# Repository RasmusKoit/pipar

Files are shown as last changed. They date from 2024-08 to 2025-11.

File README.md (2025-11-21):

# Pipar PCBs

ZMK firmware for the Pipar PCBs.



**Pipar** is a collection of different keyboards and keypads that I have designed. Each PCB in the series has unique features tailored to different needs and preferences.

## Designed PCBs

PCB Files for each keyboard/project has been seperated into their own folders. The PCBs are designed in KiCad v9.x

Currently, the following PCBs are available:

- [Pipar & Sool](#pipar-ja-sool-pepper-and-salt) - 36-key split wireless keyboard with a 3x5+3 layout and a dongle.
- [Pipar Point](#pipar-point) - 40-key split wireless keyboard with a 3x5+3+2 layout, trackpoint and LEDs.
- [Pipar Flake](#pipar-flake) - 8+1 key wireless keypad with a rotary encoder and a screen.
- [Pipar Chip](#pipar-chip) - 12-key wireless keypad with Kailh PG1316S switches and LEDs.

### Pipar ja Sool (Pepper and Salt)

> [!TIP]
> Get your own Pipar & Sool from my [Etsy Store](https://piparkeyboards.etsy.com).

Pipar Miryoku builds can be found here: [[RasmusKoit/miryoku_zmk]](https://github.com/RasmusKoit/miryoku_zmk/actions/workflows/build-example-pipar.yml)


The **Pipar ja Sool** is a 36-key split wireless keyboard with a 3x5+3 layout with a dongle. It features:

- **Microcontrollers**: XIAO BLE for both halves and a dongle.
- **Switches**: Ambients Silent Kailh Low Profile Nocturnal Choc Switches.
- **Sockets**: Kailh Hotswap sockets for easy switch replacement.
- **Key Layout**: Pipar & Sool uses Miryoku default key layout.
- **LEDs**: White LEDs for backlight.

#### Pipar ja Sool Pictures

Pictures from version V1

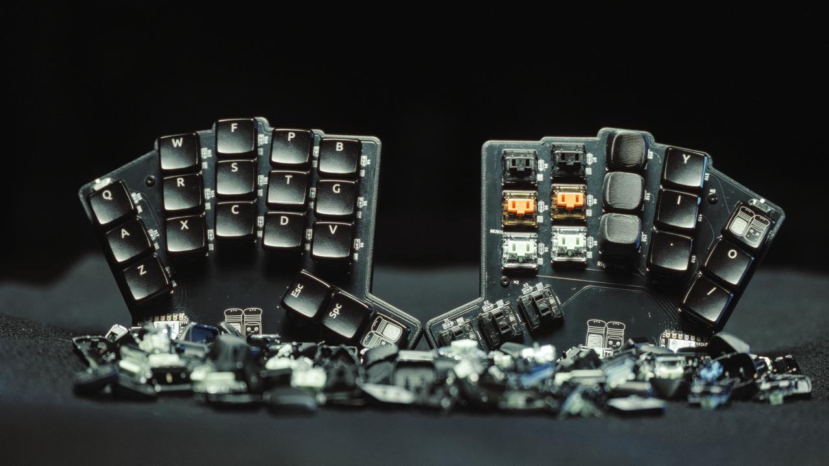
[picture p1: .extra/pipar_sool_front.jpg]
Pipar & Sool front

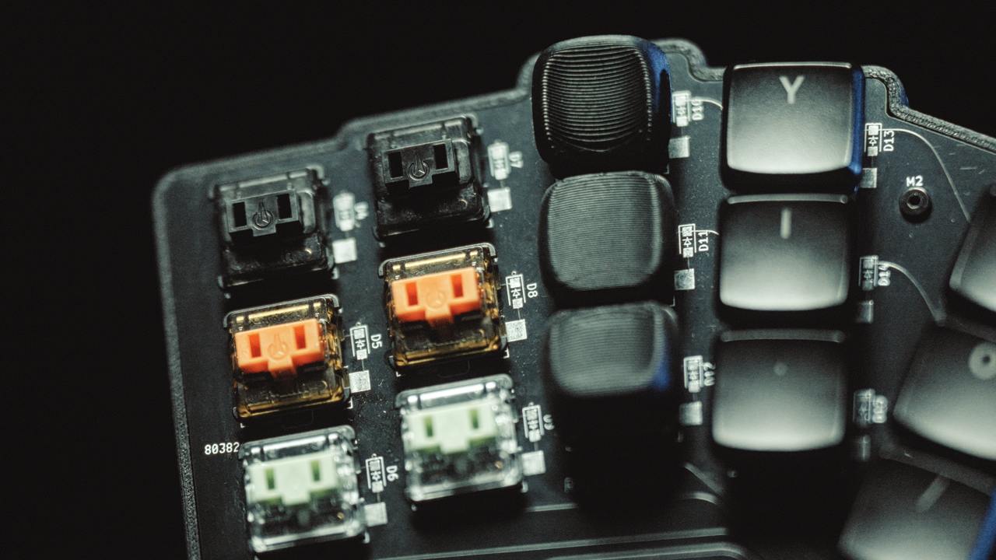
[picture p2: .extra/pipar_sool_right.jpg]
Pipar & Sool right

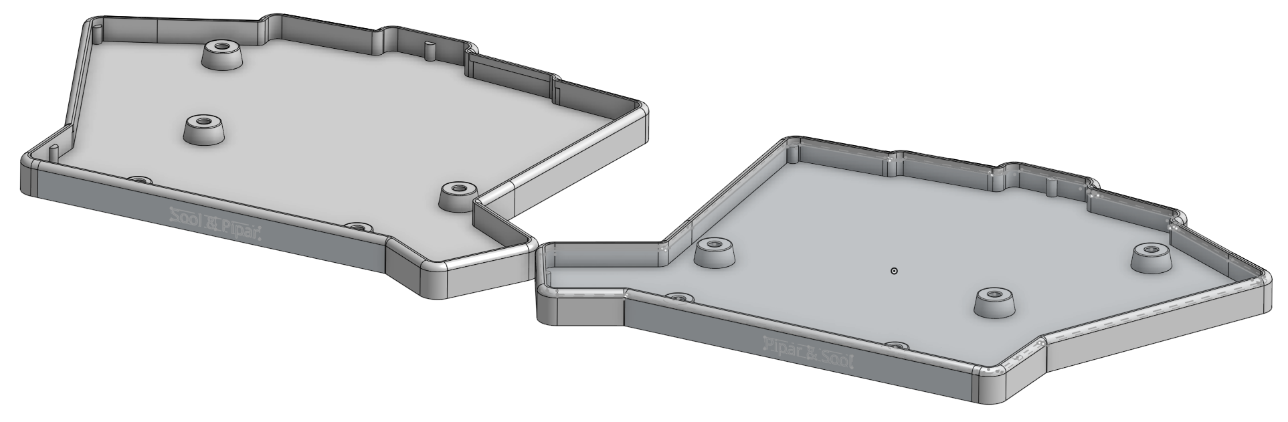
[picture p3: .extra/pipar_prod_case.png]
Pipar & Sool case


<!-- markdownlint-disable MD033 -->
<details>
  <summary>More Pictures V3</summary>

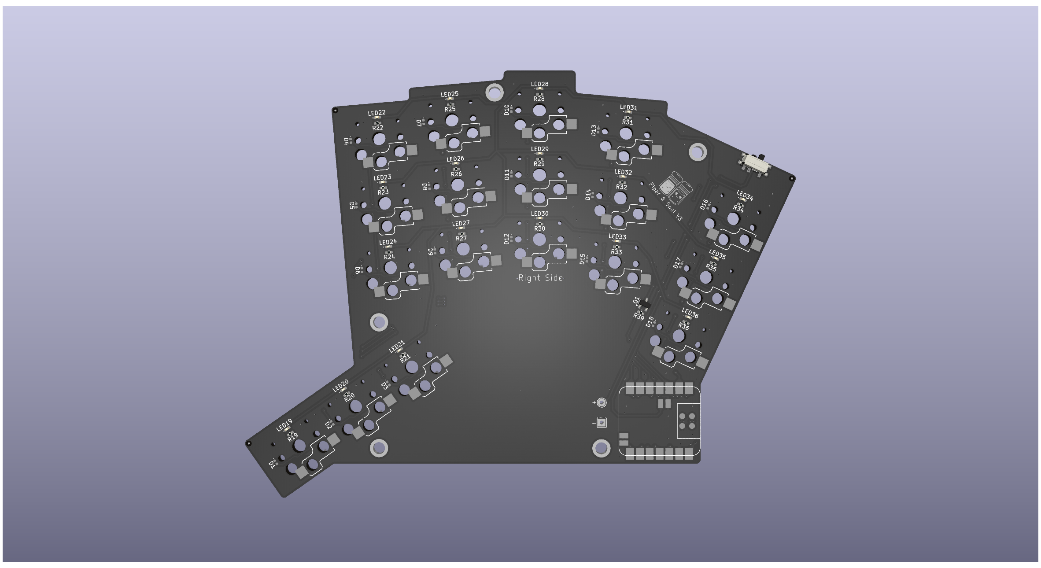
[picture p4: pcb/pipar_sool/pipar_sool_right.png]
Pipar & Sool right
  
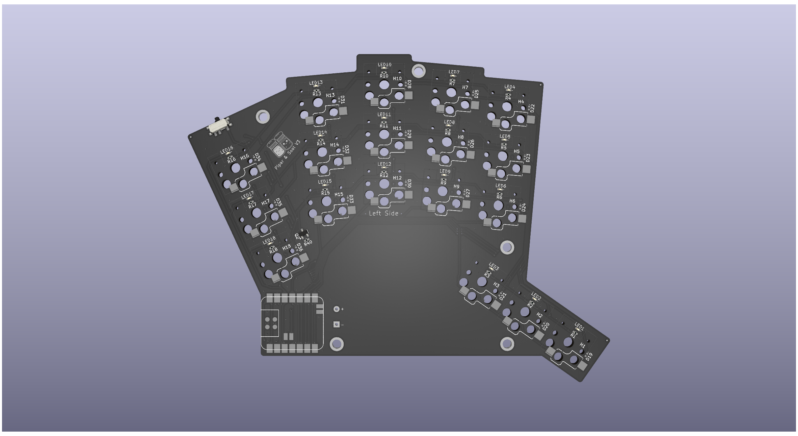
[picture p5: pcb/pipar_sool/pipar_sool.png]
Pipar & Sool left
  
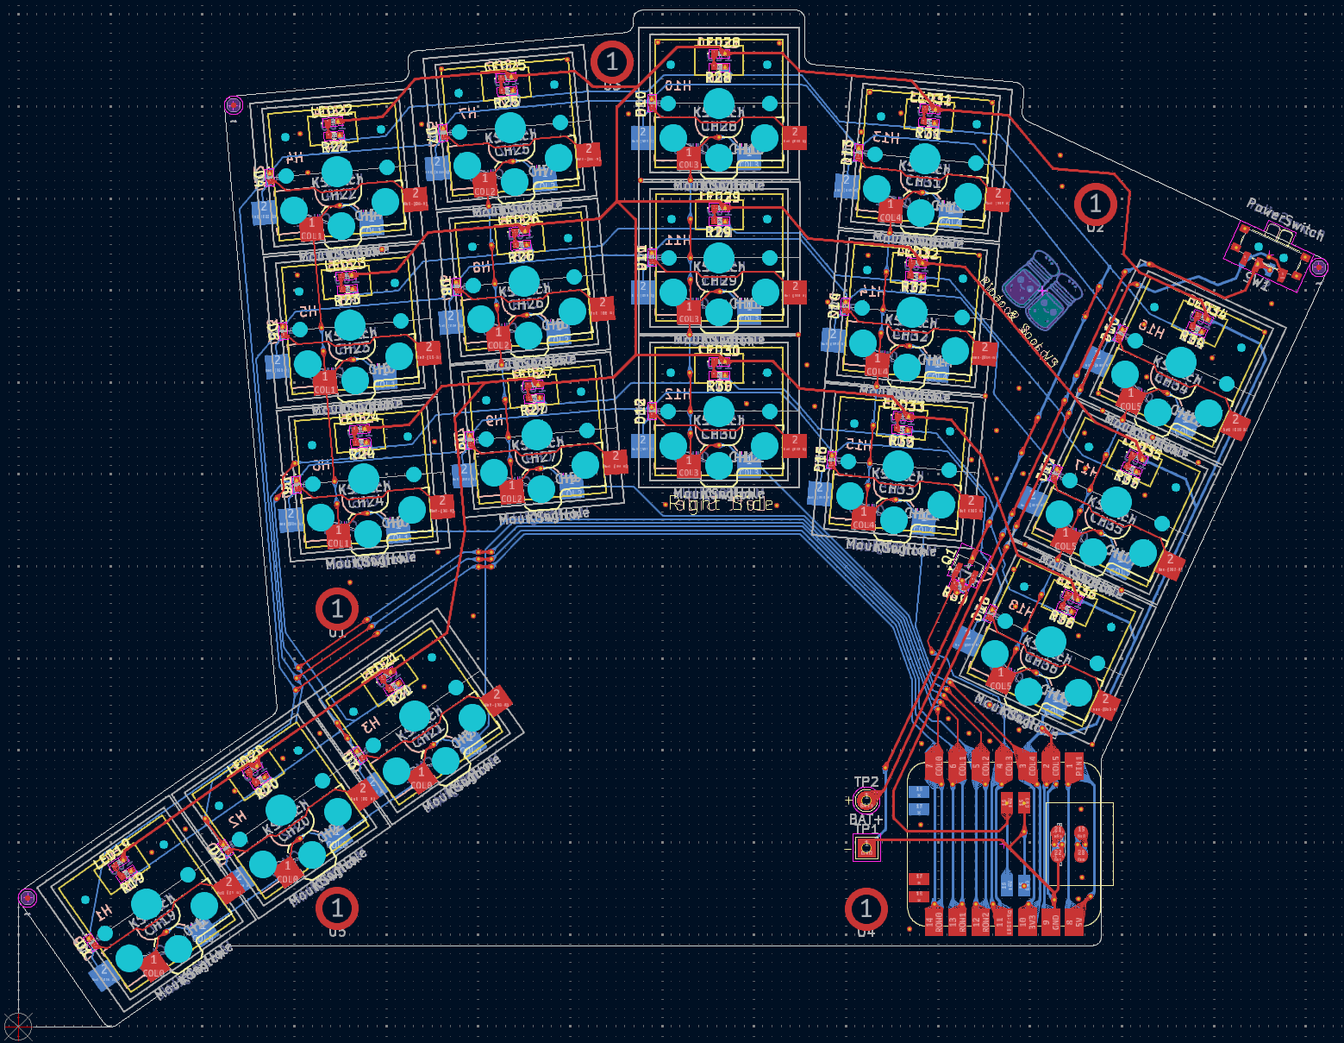
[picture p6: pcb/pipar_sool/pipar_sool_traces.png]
Pipar & Sool traces
  

</details>

#### Pipar ja Sool Design Details

> [!NOTE]
> The V3 design is compatible with the V2 case.

- **Layout**: Splayed split keyboard with a 3x5+3 layout.
  - **Thumb Cluster**: Three keys on each half.
  - **Outer Columns**: Split to reduce the distance to the keys.
- **Wireless**: Uses the XIAO BLE microcontroller for both halves and a dongle.
- **Battery**: Larger area for the battery to ensure longer usage time.
- **LEDs**: I sometimes miss the visual feedback of the LEDs, so I added them to the design.

Changenotes:

V3 version has went with the route of using smaller components with the 0403/SOD-323 package for resistors and diodes. The design is also compatible with the V2 case, so the case can be used with the V3 PCB.
V3 also has the added benefit of using solder nuts for mounting the PCB to the case, instead of just holes for M2 screws. This adds more possibilities for mounting the PCB to the case.

#### Pipar ja Sool V2 Order List

Consider supporting me by purchasing Pipar & Sool V3 Kit from my [Etsy Store](https://piparkeyboards.etsy.com).

The components list is for V2 version of the Pipar & Sool which uses larger components in 0805/SOD-123 package.
V3 version uses smaller components in 0403/SOD-323 package.

If you are interested in building the V2 version, here is a list of components you will need:

- **PCB**: 2x Pipar V2 PCBs [Gerber files here](./.extra/pipar_sool_v2.zip).
- **Microcontroller**: 3x [XIAO BLE microcontrollers (Aliexpress)](https://www.aliexpress.com/item/1005004459618789.html?spm=a2g0o.order_list.order_list_main.20.2f8718028ReplC)
- **On/Off Switch**: 2x [On/Off Switch (Aliexpress)](https://www.aliexpress.com/item/1005006710234187.html?spm=a2g0o.order_list.order_list_main.15.2f8718028ReplC)
- **Thread inserts**: 36x [M2 Thread Inserts (Aliexpress)](https://www.aliexpress.com/item/1005003582355741.html?spm=a2g0o.order_list.order_list_main.10.2f8718028ReplC)
- **Screws**: 10x [M2x4mm Screws (Aliexpress)](https://www.aliexpress.com/item/1005005070119421.html?spm=a2g0o.order_list.order_list_main.5.2f8718028ReplC)
- **Switches**: 36x [Ambients Silent Kailh Low Profile Nocturnal Choc Switches (SplitKB)](https://splitkb.com/products/ambients-kailh-low-profile-choc-switches?variant=48116119830875)
- **Sockets**: 36x [Kailh Hotswap sockets (SplitKB)](https://splitkb.com/products/kailh-hotswap-sockets?variant=39472161456205)
- **Diodes**: 36x [1N4148/SOD-123 Diodes (SplitKB)](https://splitkb.com/products/smd-diodes?variant=42283984027907)
- **Battery**: 2x [320mAh 3x30x40mm (Oomipood)](https://www.oomipood.ee/product/accu_lp303040_cl). Case is designed for 3mm height batteries with some extra space.
- **Case**: 1x [Pipar Case V2](https://cad.onshape.com/documents/0618546ffe3fe295af383a46/w/2cb3b1882647ac70cde86ee4/e/379ba082d1ffd285c3cab9c2)
- **Keycaps**: 1x [Kailh Choc Keycaps **Colemak-DH** (FKCaps)](https://fkcaps.com/custom/KYTMMA)

### Pipar Point

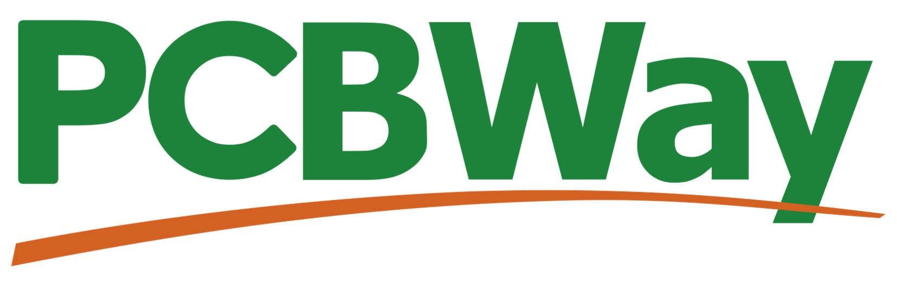
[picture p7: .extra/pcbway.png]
PCBWay


> [!NOTE]
> I am happy to announce that for the Pipar Point project, I have partnered with [PCBWay](https://www.pcbway.com/) to provide the PCBs for the project. PCBWay is a professional PCB manufacturer with over 10 years of experience in the industry. They offer a wide range of services, including PCB manufacturing, PCB assembly, and PCB design. I am excited to be working with PCBWay on this project, and I am confident that they will deliver high-quality PCBs that meet my specifications.

*Currently in third prototype phase.*
*Works and currently in testing*

#### Pipar Point Pictures

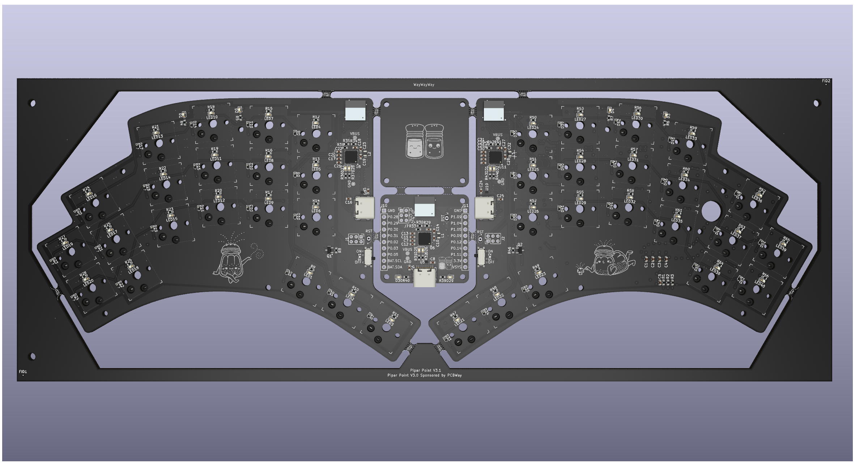
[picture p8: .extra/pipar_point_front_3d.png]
Pipar Point front 3D

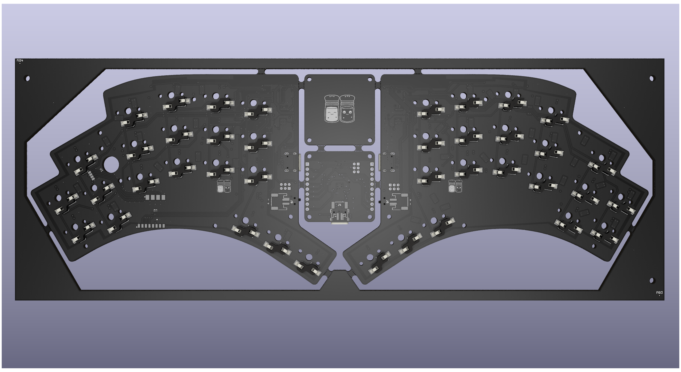
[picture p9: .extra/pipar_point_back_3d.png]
Pipar Point back 3D

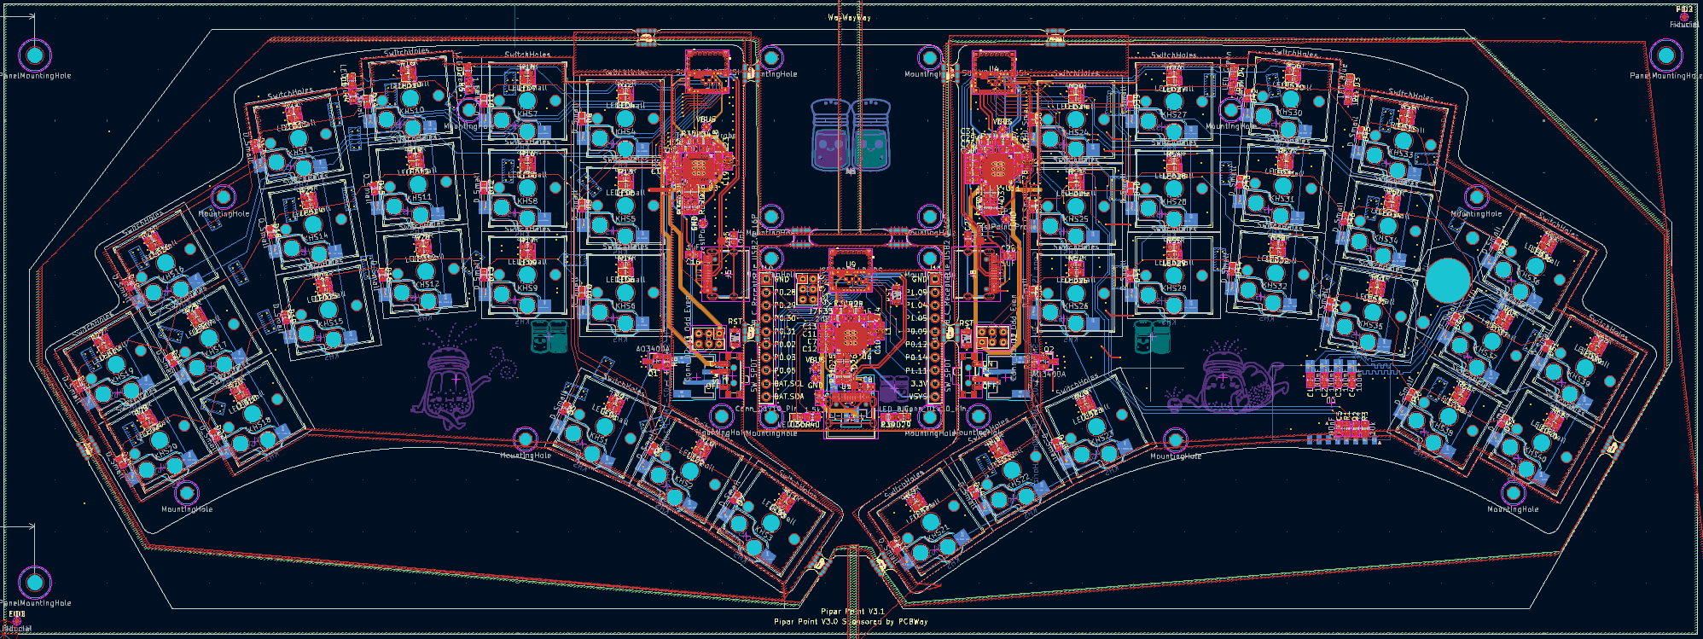
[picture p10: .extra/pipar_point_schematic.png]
Pipar Point Schematic


#### Pipar Point Design Details

- **Layout**: Splayed split keyboard with a 3x5+3+2  layout.
  - **Thumb Cluster**: Three keys on each half.
  - **Pinkie Cluster**: Split to reduce the distance to the keys. Extra Keys for macros or foreign letters
- **Wireless**: Uses ISP1807 SIP IC based on NRF52840 IC for both halves.
- **Battery**: Larger area for the battery to ensure longer usage time.
- **Trackpoint**: Sprintek Trackpoint for mouse control on the right side.
- **LEDs**: I sometimes miss the visual feedback of the LEDs, so I added them to the design.
- **Top Plate**: Designed to be used with a top plate for a more rigid build.
- **Mounting**: Case includes magsafe mounting for easy attachment and detachment. Rubber feet to keep the keyboard in place.

Idea was to iterate on the Pipar ja Sool design and add a trackpoint for mouse control. The design is still in the early stages and will be updated as the project progresses. Because of the trackpoint, LEDs and the battery size has been increased to 2500mAh to compensate for the power draw of the trackpoint and LEDs. With this design, I am aiming to challege myself to design a more complex PCB by using more components which will also be smaller in size. The design will also include a top plate to make the build more rigid and also to hide the trackpoint mounting cleaner.

I want to thank [zhiayang/Mikoto](https://github.com/zhiayang/mikoto) and [Hello9999901/laptop](https://github.com/Hello9999901/laptop/tree/main/keyboard) for making this project possible. Thank you [Eden](https://github.com/galaxyeden) for helping me understand more about Zephyr and getting me started.

### Pipar Chip

Pipar Chip is a 12-key wireless keypad with Kailh PG1316S switches and LEDs.

Pipar Chip features:

- **Onboard Components**: Features ISP1807 SIP IC based on NRF52840 IC
- **Switches**: Kailh PG1316S switches.
- **LEDs**: White LEDs for backlighting. 2 LEDs for charging and error indication. 3 extra LEDs that can be used for any purpose.
- **Components**: Uses smaller components in 0603/SOD-523 package for resistors, capacitors, etc.
- **Battery**: 500mAh battery to ensure longer usage time even with the LEDs.

#### Pipar Chip Pictures

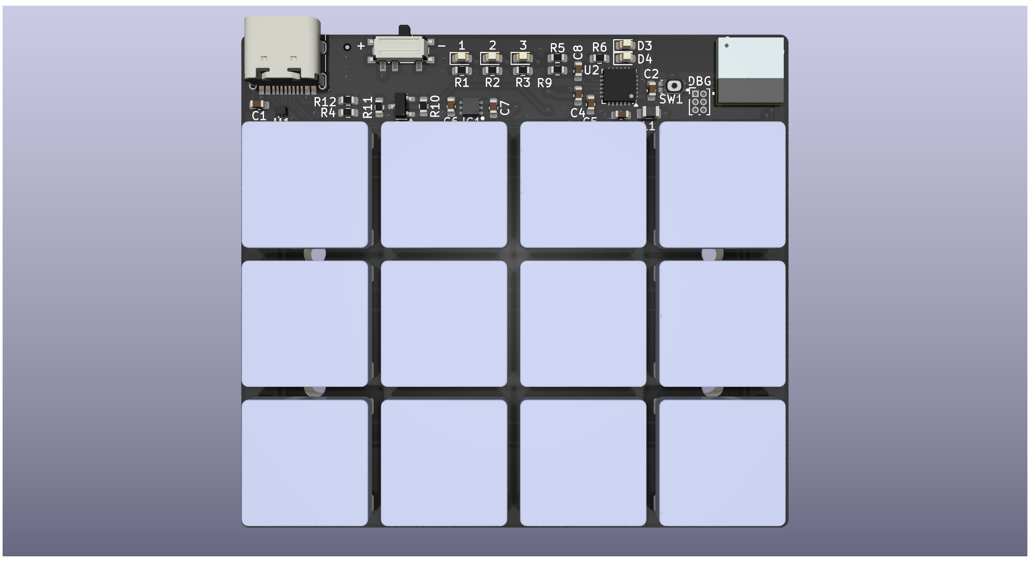
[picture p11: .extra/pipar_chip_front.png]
Pipar Chip Front

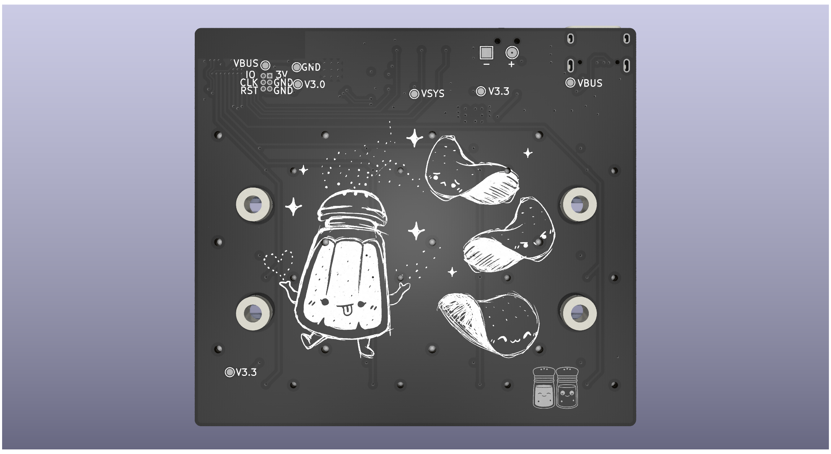
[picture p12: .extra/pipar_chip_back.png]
Pipar Chip Back

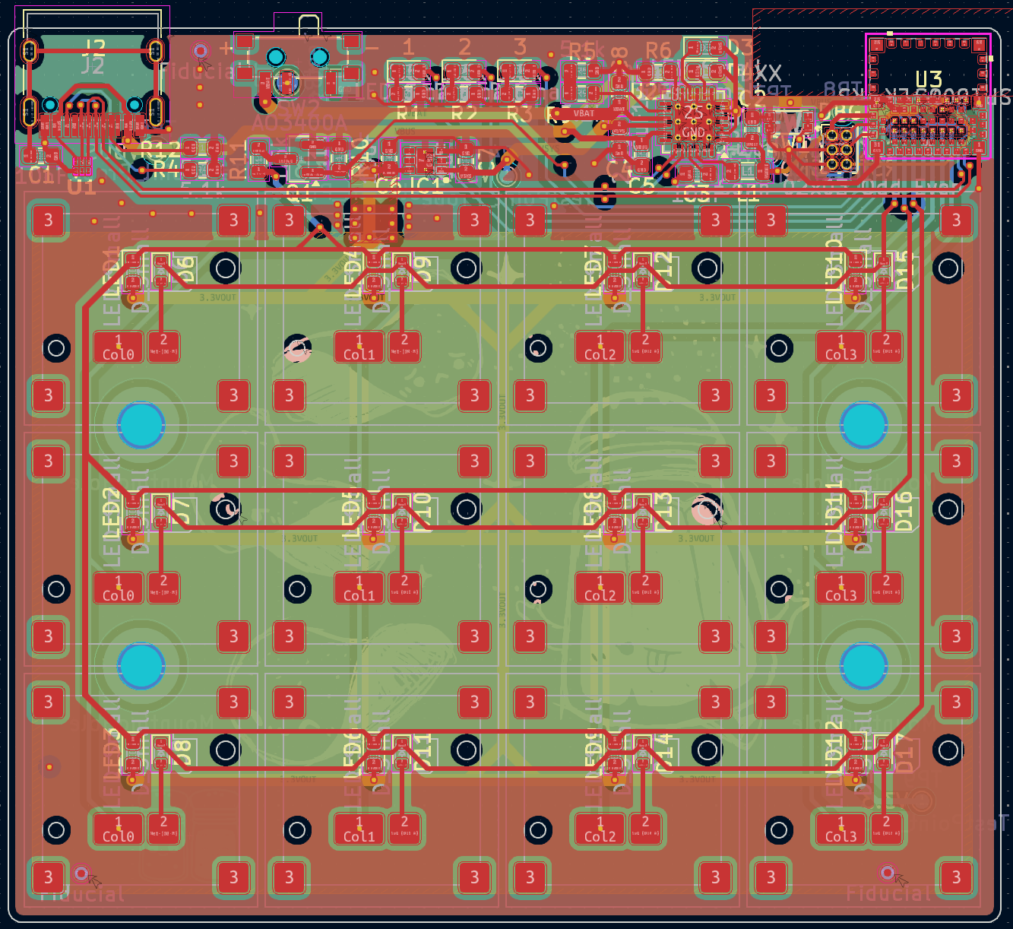
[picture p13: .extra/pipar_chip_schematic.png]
Pipar Chip Schematic


### Pipar Flake

The **Pipar Flake** is an 8+1 key wireless keypad with a rotary encoder (optional) and a screen. It includes:

- **Microcontroller**: SuperMini NRF52840.
- **Display**: Tiny OLED display.
- **Switches**: Ambients Silent Kailh Low Profile Nocturnal Choc Switches.
- **Sockets**: Kailh Hotswap sockets for easy switch replacement.
- **LEDs**: White LEDs for backlighting.

#### Pipar Flake Pictures

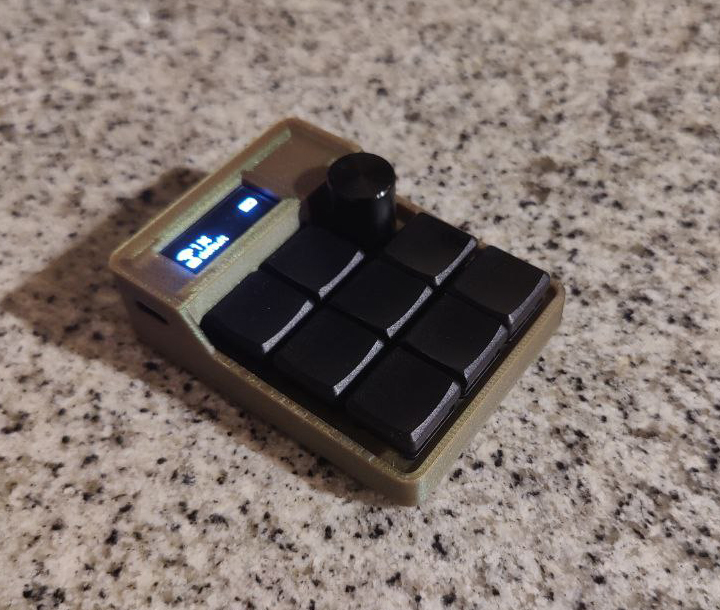
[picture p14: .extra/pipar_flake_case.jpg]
Pipar Flake in a Case

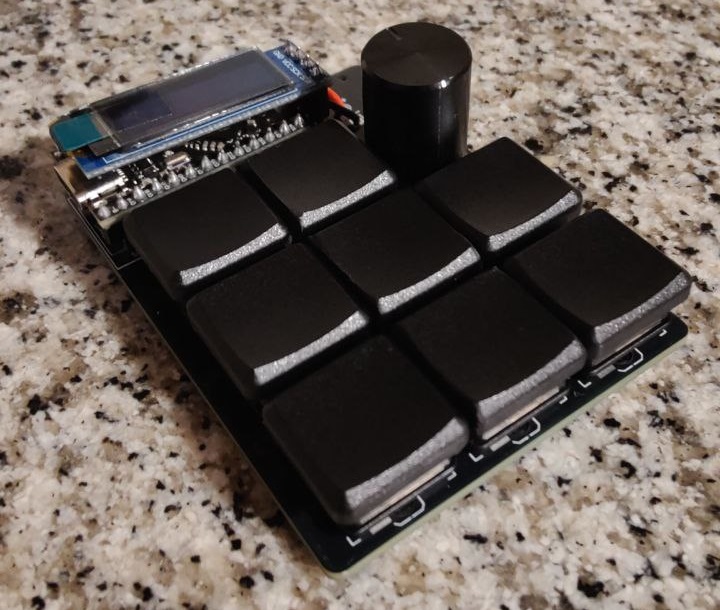
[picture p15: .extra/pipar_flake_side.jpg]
Pipar Flake side


#### Pipar Flake Design Details

- **Usage**: Intended as a tiny keypad or numpad.
  - **Current Use Case**: Control media player (e.g., Kodi).
- **Size**: Designed to be as small as possible while still being usable.
- **Rotary Encoder**:  
  - **Function**: Can control volume.
  - **Push Button**: Can be used to change layers.

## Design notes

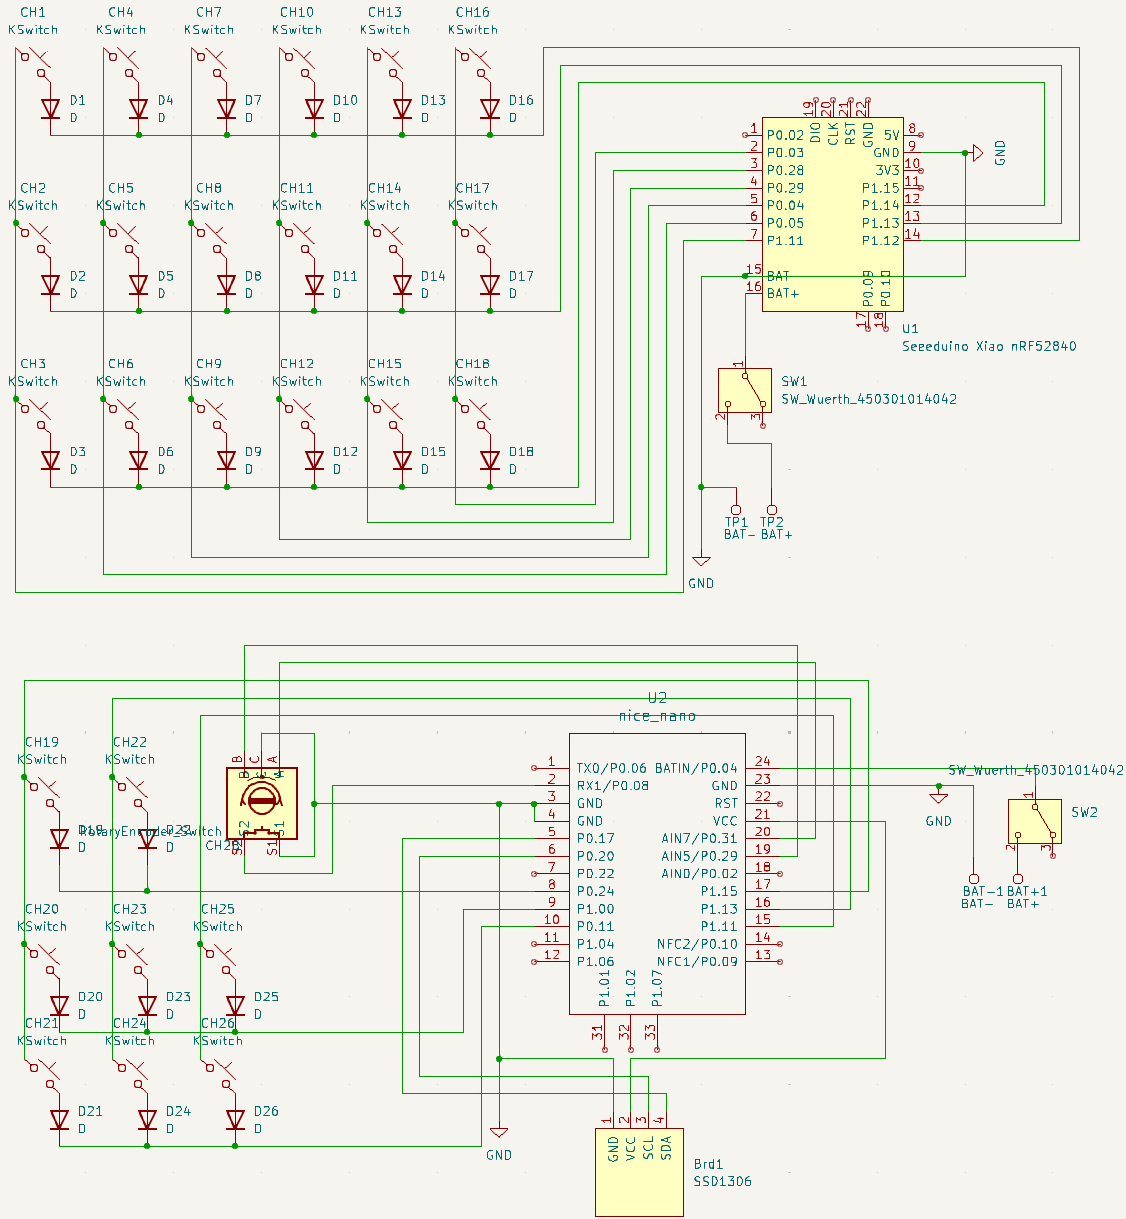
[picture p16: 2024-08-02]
.extra/pipar_schematic.png

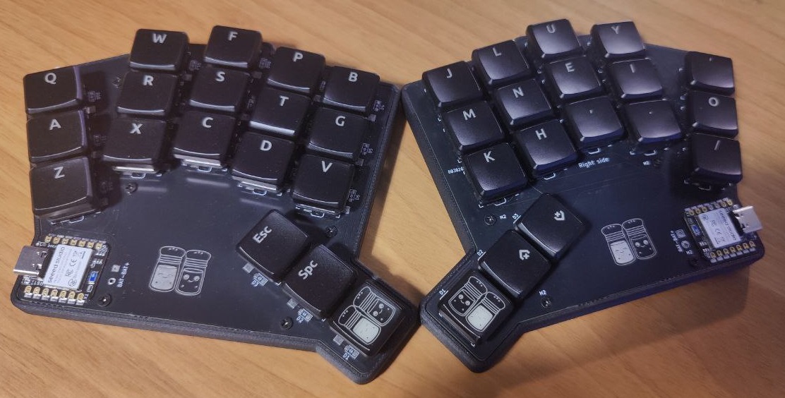
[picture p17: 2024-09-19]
.extra/pipar_prod_top.jpg

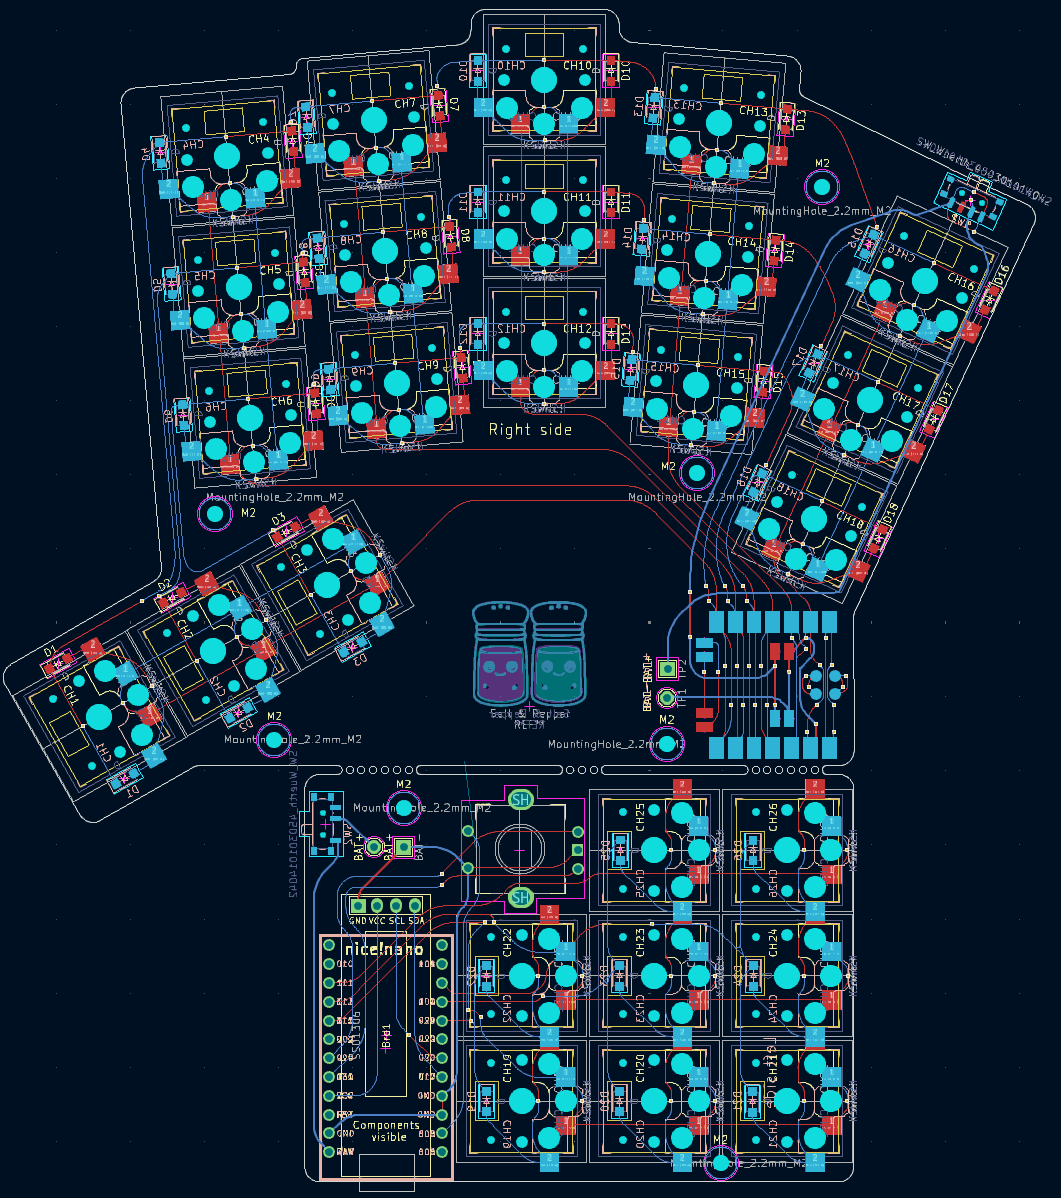
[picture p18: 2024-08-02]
.extra/pipar_layout.png

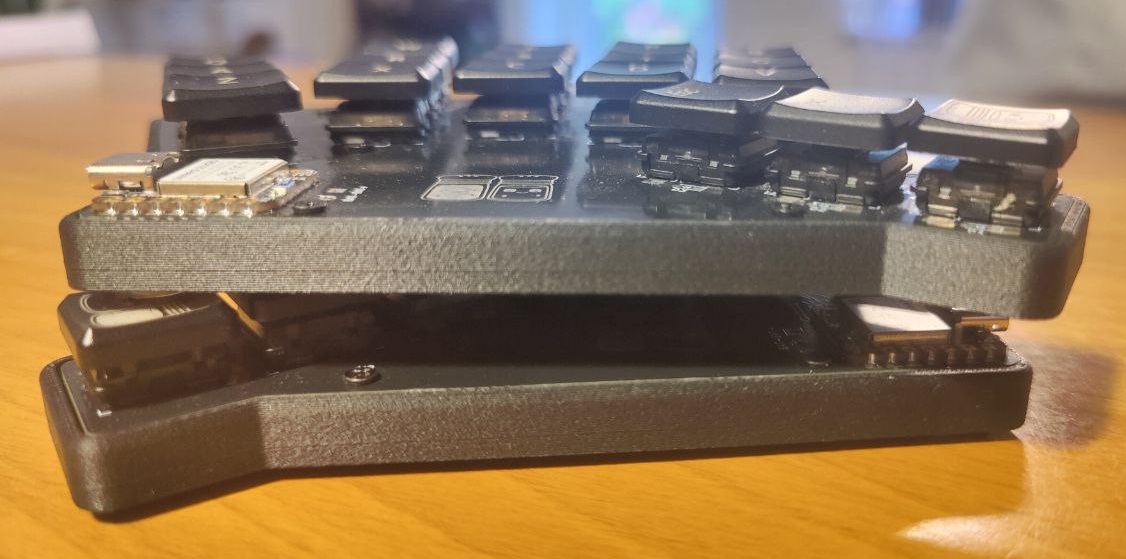
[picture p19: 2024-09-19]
.extra/pipar_prod_side.jpg

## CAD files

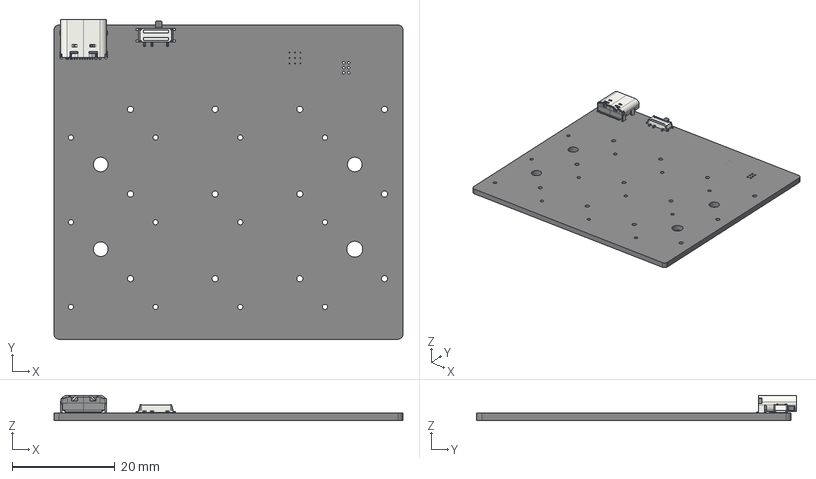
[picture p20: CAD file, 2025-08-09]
pcb/pipar_chip/pipar_chip.step
68.0 x 62.3 x 4.91 mm
USB_C_Receptacle_GCT_USB4105-xx-A_16P_TopMnt_Horizontal
SW_SPDT_PCM12
pipar_chip_PCB

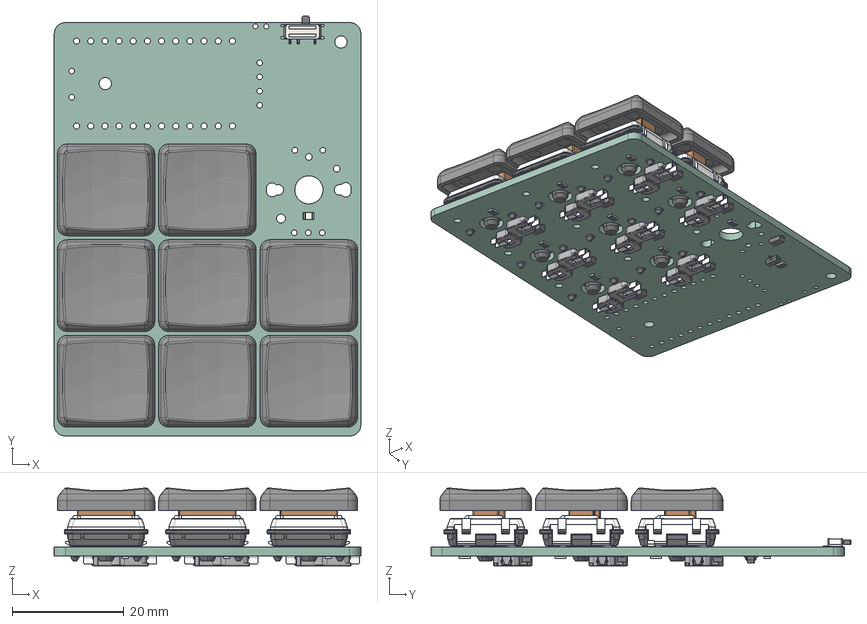
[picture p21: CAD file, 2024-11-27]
pcb/pipar_flake/pipar_flake.step
55.0 x 75.3 x 14.0 mm
SW_Kailh_Choc_V1_cp x 8
SW_Hotswap_Kailh_Choc_v1 x 8
Choc_V1_MBK_Keycap_1u v1 x 8
LED_0805_2012Metric x 17
Fusion_sp
CQ assembly x 9
R_0805_2012Metric x 10
SOT_23
pipar_flake_PCB

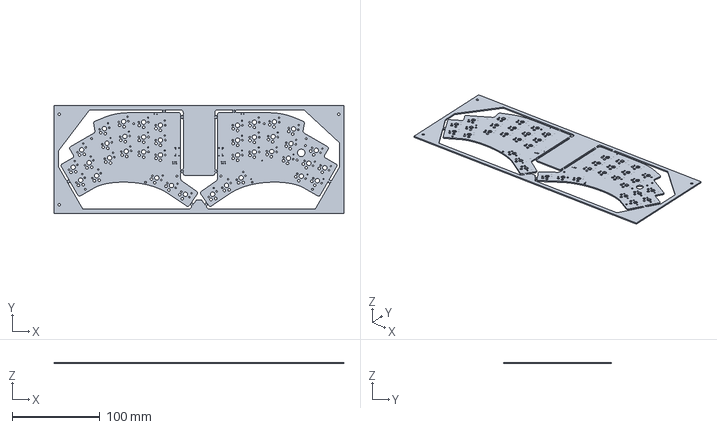
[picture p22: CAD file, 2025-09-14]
pcb/pipar_point_v3/pipar_point_v3.step
329.9 x 122.8 x 1.51 mm

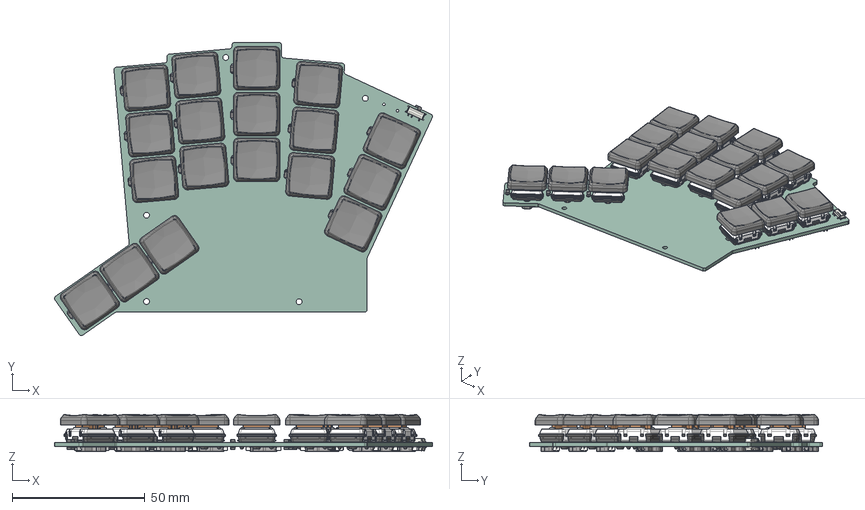
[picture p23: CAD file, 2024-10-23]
pcb/pipar_sool/pipar_sool.step
142.4 x 110.5 x 14.0 mm
SW_Kailh_Choc_V1_cp x 18
SW_Hotswap_Kailh_Choc_v1 x 18
Choc_V1_MBK_Keycap_1u v1 x 18
LED_0805_2012Metric x 18
CQ assembly x 36
Fusion_sp x 2
pipar_sool_PCB

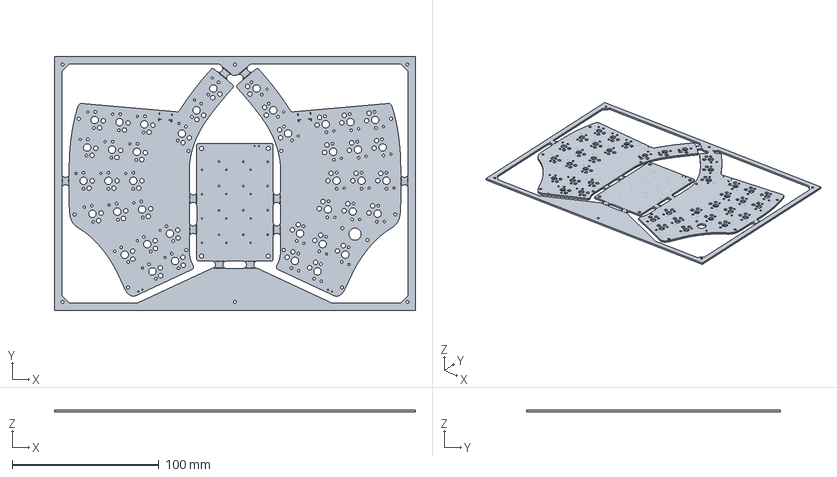
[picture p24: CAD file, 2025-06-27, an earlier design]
pcb/pipar_point_v2/pipar_point.step
245.7 x 172.6 x 1.51 mm

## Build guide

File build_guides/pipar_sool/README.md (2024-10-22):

# Pipar & Sool Build Guide

Front shot

You will be building your own Pipar & Sool keyboard. This guide will help you through the process of building the keyboard.

## Table of Contents

TODO

### What's in the Box

- 2x Pipar PCBs
- 3x XIAO BLE microcontrollers (2 for the halves, 1 for the dongle)
  - 2 of the microcontrollers are installed to the PCBs
- 36x Diodes
- 36x Kailh Hotswap sockets
- 2x On/Off Switches
- 2x cases (one for each half)
- 10x M2x3mm heat-set inserts (Installed in the case)
- 10x M2x4mm screws (hex 1.3 or philips)

### Tools Required

- Soldering Iron
- Solder
- Tweezers
- Screwdriver/Hex key
- Heat gun (optional)
- Multimeter (optional)

### Order of Assembly

1. Solder the diodes to the PCBs.
2. Solder the Kailh hotswap sockets to the PCBs.
3. Solder the power switch to the PCB.
4. Solder the battery to the PCB.
5. Verify the battery is connected correctly.
6. Install the switches and keycaps.

### How to assemble

> [!NOTE]
> If you are new to soldering, you can check out a quick video guide on how to solder [**here**](https://youtu.be/HycbZviKKUg)

1. Unscrew the 10 screws attaching the PCBs to the case.
2. Remove the PCBs from the case.
3. Solder the diodes to the bottom of the PCB on each half (diodes should be mounted inside the case).
    - The direction of the diodes is important, the line direction on the diode should match the line on the PCB.
4. Solder the Kailh hotswap sockets to the bottom of the PCB on each half.
    - The sockets should be mounted inside the case.
    - The sockets should be flush with the PCB.
    - The socket direction is important, make sure the socket is oriented correctly by checking the square and hexagon drawing on the PCB.
5. Verify the diodes and sockets are soldered correctly.
    - Use a multimeter to check the pads.
6. Solder the power switch to the top of the PCB.
7. Turn the power switch off (on both halves - left is off, right is on).
8. Clean the board of any flux residue.
9. Solder on the battery.
10. Verify the battery is soldered correctly by checking the voltage. The battery should be around 3.7V.
11. Turn the power switch on (on both halves - left is off, right is on).
12. Measure the 3.3V and GND pins on the microcontroller to verify the battery is connected correctly. The voltage should be 3.3V.
    - If the voltage is not correct (showing 0), check the battery connection and that the power switch is on.
    - If the voltage shows 3.7V on the battery when the switch is off and 0V when the switch is on then there is a short circuit.
13. Plug in the dongle to your computer and the halves should connect to the dongle.
14. Check the keys on each half to verify they are working correctly, use tweezers to short the pads.
15. Turn everything off
16. Carefully install the switches and keycaps. Support the hotswap sockets from the bottom when installing the switches.
17. Screw the PCB back into the case.
18. Enjoy your new keyboard!

### Tips for soldering

- Add flux when ever possible.
- When soldering the diodes, tin one pad, then heat the pad and slide the diode into place. Then solder the other side.
- When soldering the sockets, tin both pads with a small amount of solder, then place the socket in and while applying pressure with tweezers heat the pad and socket until the solder melts. Then repeat for the other side.
- When soldering the battery, tin the wires so they do not fray and then solder them to the pads. Make sure the positive battery wire is not shorting against the PCB.
- Clean the flux residue with isopropyl alcohol.
  - **Do this before installing the switches and keycaps.**

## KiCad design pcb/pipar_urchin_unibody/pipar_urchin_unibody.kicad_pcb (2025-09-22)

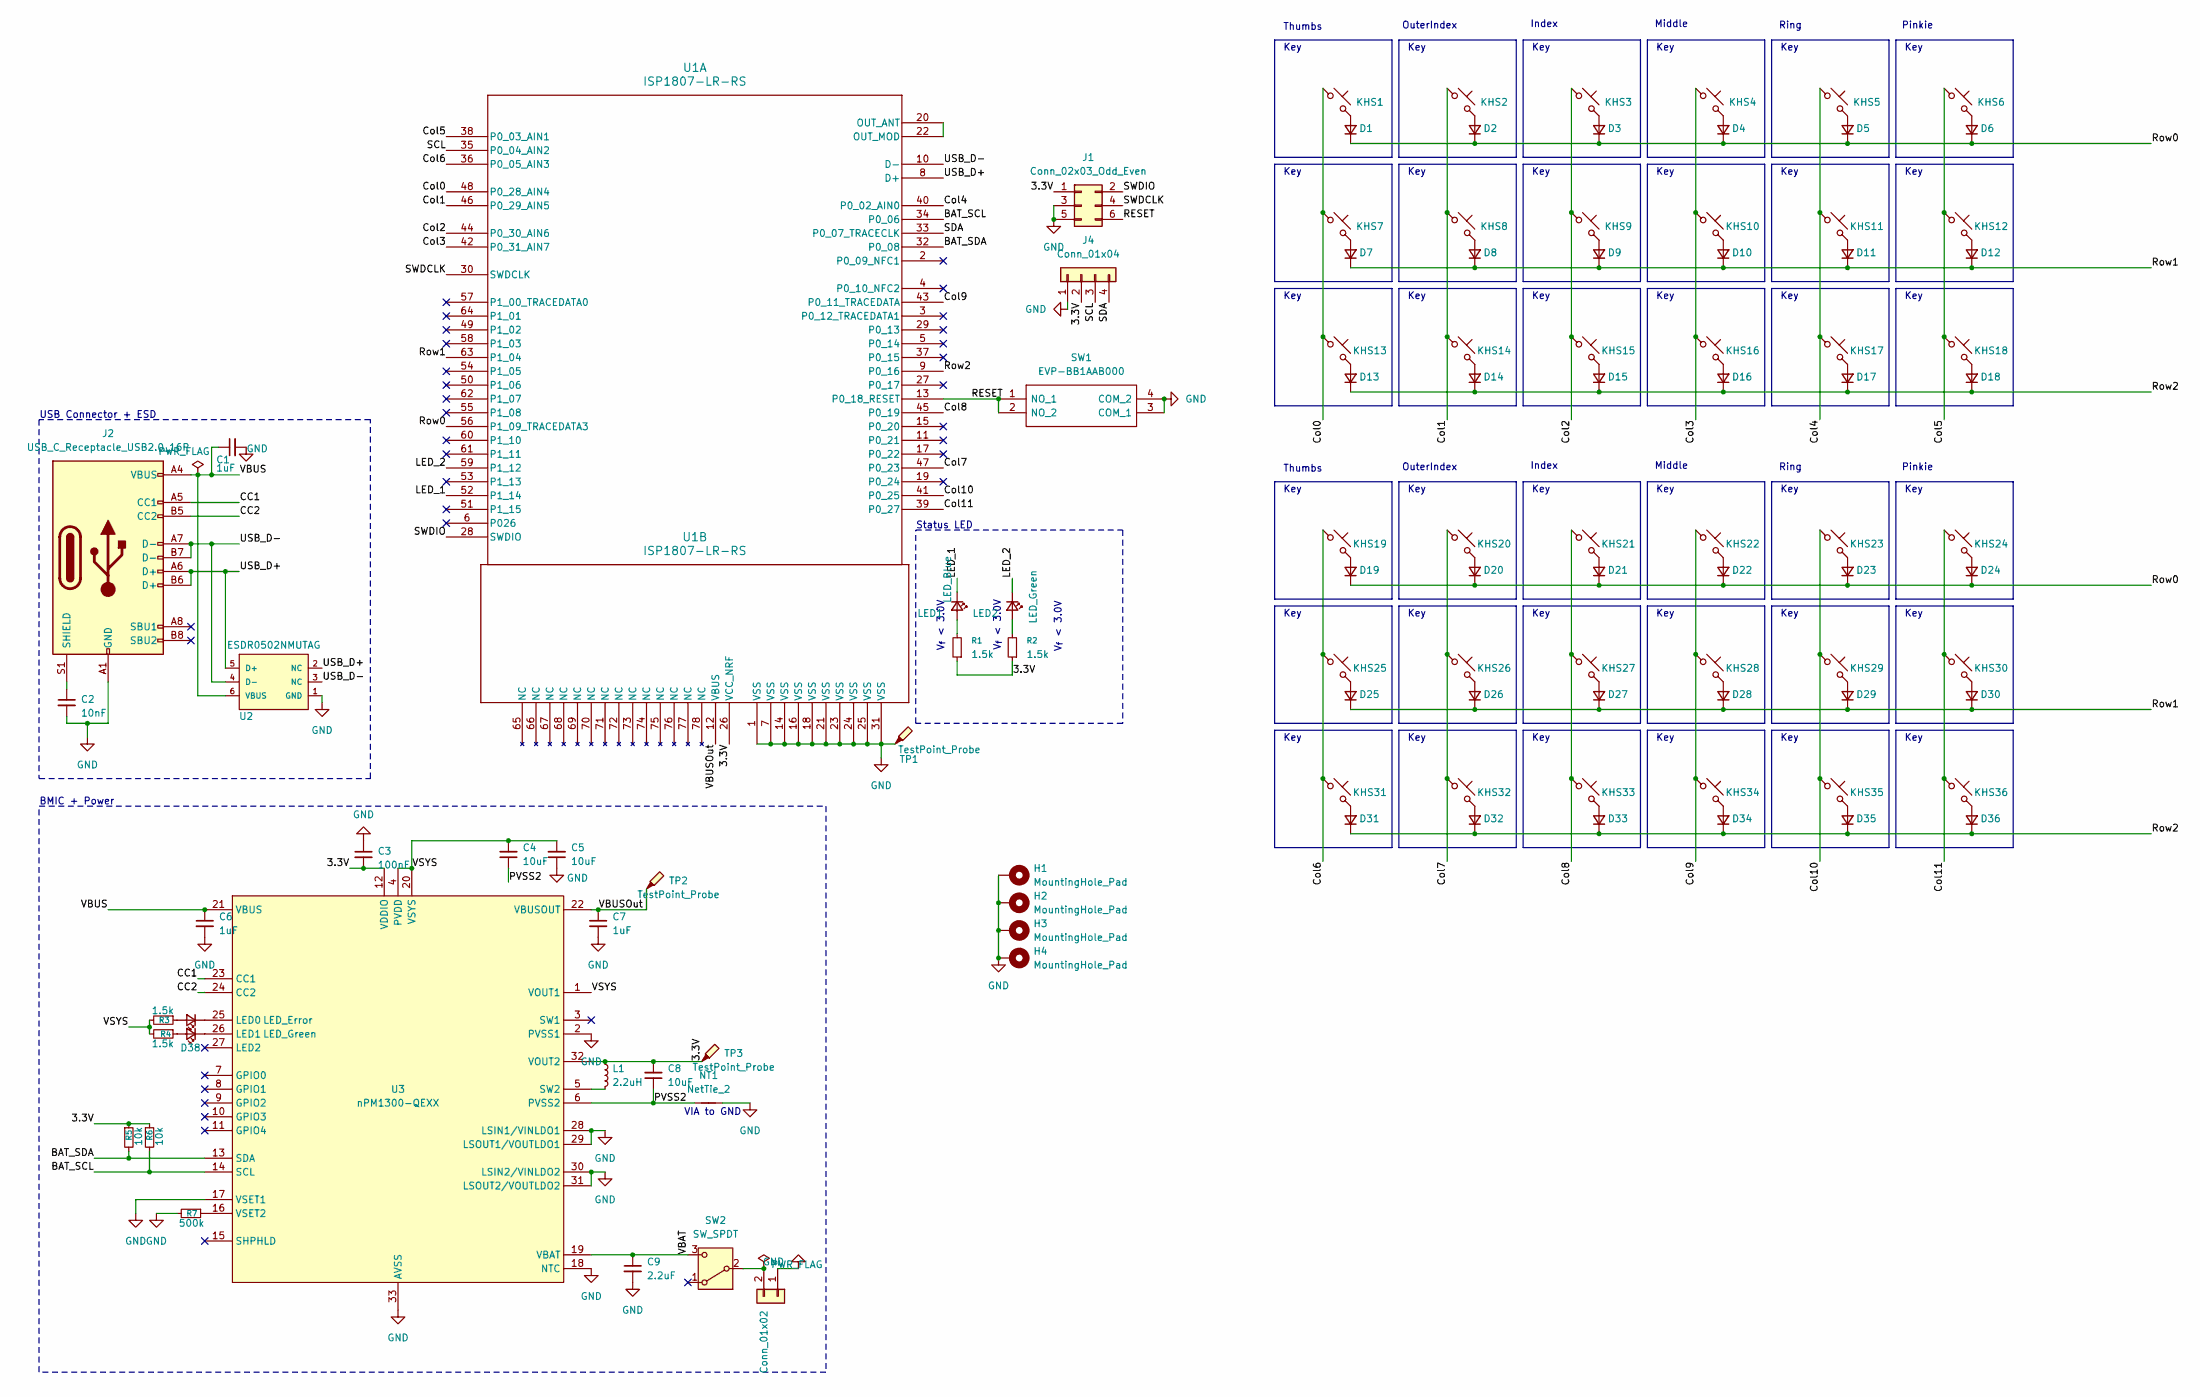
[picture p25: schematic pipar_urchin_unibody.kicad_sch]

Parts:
C1, C6, C7: 1uF; C_0603_1608Metric; Mouser Part Number 963-LMK107B7105KA-T
C2: 10nF; C_0603_1608Metric; Mouser Part Number 810-CGA3E2X7R1H103K
C3: 100nF; C_0603_1608Metric; Mouser Part Number 603-CC603KRX7R8BB104
C4, C5, C8: 10uF; C_0603_1608Metric; Mouser Part Number 81-GRM188R61E106KA3J
C9: 2.2uF; C_0603_1608Metric; Mouser Part Number 963-EMK107BB7225KA-T
D1, D2, D3, D4, D5, D6, D7, D8, D9, D10, D11, D12, D13, D14, D15, D16, D17, D18, D19, D20, D21, D22, D23, D24, D25, D26, D27, D28, D29, D30, D31, D32, D33, D34, D35, D36: D_Small; D_SOD-123; Mouser Part Number 241-1N4148W_R1_00001
D37: LED_Error; LED_0603_1608Metric; Manufacturer_Part_Number IN-S63AT5A; Mouser Part Number 743-IN-S63AT5A
D38: LED_Green; LED_0603_1608Metric; Manufacturer_Part_Number IN-S63AT5G; Mouser Part Number 743-IN-S63AT5G
H1, H2, H3, H4: MountingHole_Pad; MountingHole_2.2mm_M2_DIN965_Pad
J1: Conn_02x03_Odd_Even; PinHeader_2x03_P2.00mm_Vertical
J2: USB_C_Receptacle_USB2.0_16P; USB_C_Receptacle_HRO_TYPE-C-31-M-12; Mouser Part Number 179-UJ20CHGSMTP16TR
J3: Conn_01x02; JST_PH_S2B-PH-SM4-TB_1x02-1MP_P2.00mm_Horizontal; Mouser Part Number 306-S2BPHSM4TBLFSN
J4: Conn_01x04; PinSocket_1x04_P2.54mm_Vertical
KHS1, KHS2, KHS3, KHS4, KHS5, KHS6, KHS7, KHS8, KHS9, KHS10, KHS11, KHS12, KHS13, KHS14, KHS15, KHS16, KHS17, KHS18, KHS19, KHS20, KHS21, KHS22, KHS23, KHS24, KHS25, KHS26, KHS27, KHS28, KHS29, KHS30, KHS31, KHS32, KHS33, KHS34, KHS35, KHS36: KHS; CPG1316S01D02_castelated_mikecinq
L1: 2.2uH; L_0805_2012Metric; Manufacturer_Part_Number MLZ2012A2R2WT000; Mouser Part Number 810-MLZ2012A2R2WT000
LED1: LED_Blue; LED_0603_1608Metric; Manufacturer_Part_Number IN-S63AT5B; Mouser Part Number 743-S63AT5B
LED2: LED_Green; LED_0603_1608Metric; Manufacturer_Part_Number IN-S63AT5G; Mouser Part Number 743-IN-S63AT5G
NT1: NetTie_2; NetTie-2_THT_Pad0.3mm
R1, R2, R3, R4: 1.5k; R_0603_1608Metric; Manufacturer_Part_Number RC0603FR-071K5L; Mouser Part Number 603-RC0603FR-071K5L
R5, R6: 10k; R_0603_1608Metric; Manufacturer_Part_Number CRCW060310K0FKEA; Mouser Part Number 71-CRCW0603-10K-E3
R7: 500k; R_0603_1608Metric; Manufacturer_Part_Number CRCW0603499KFKEA; Mouser Part Number 71-CRCW0603-499K-E3
SW1: EVP-BB1AAB000; EVPBB2A9B000; Mouser Part Number 667-EVP-BB1AAB000
SW2: SW_SPDT; SW_SPDT_PCM12; Manufacturer_Part_Number PCM12SMTBR; Mouser Part Number 611-PCM12SMTBR
TP1, TP2, TP3: TestPoint_Probe; TestPoint_Pad_D1.0mm
U1: ISP1807-LR-RS; Manufacturer_Part_Number ISP1807-LR-RS; Mouser Part Number 359-ISP1807-LR-RS
U2: ESDR0502NMUTAG; UDFN-6_1.2x1.0mm_P0.4mm; Manufacturer Part ESDR0502NMUTBG; LCSC C327480
U3: nPM1300-QEXX; QFN-32-1EP_5x5mm_P0.5mm_EP3.6x3.6mm_ThermalVias; Manufacturer_Part_Number nPM1300-QEAA-R7; Mouser Part Number 949-NPM1300-QEAA-R7

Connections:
/3.3V: C3.2, C8.2, J1.1, J4.2, L1.1, R1.1, R2.1, R5.1, R6.1, TP3.1, U1.26 (VCC_NRF), U3.12 (VDDIO), U3.32 (VOUT2)
/BAT_SCL: R6.2, U1.34 (P0_06), U3.14 (SCL)
/BAT_SDA: R5.2, U1.32 (P0_08), U3.13 (SDA)
/CC1: J2.A5 (CC1), U3.23 (CC1)
/CC2: J2.B5 (CC2), U3.24 (CC2)
/Col0: KHS1.1, KHS7.1, KHS13.1, U1.48 (P0_28_AIN4)
/Col1: KHS2.1, KHS8.1, KHS14.1, U1.46 (P0_29_AIN5)
/Col2: KHS3.1, KHS9.1, KHS15.1, U1.44 (P0_30_AIN6)
/Col3: KHS4.1, KHS10.1, KHS16.1, U1.42 (P0_31_AIN7)
/Col4: KHS5.1, KHS11.1, KHS17.1, U1.40 (P0_02_AIN0)
/Col5: KHS6.1, KHS12.1, KHS18.1, U1.38 (P0_03_AIN1)
/Col6: KHS19.1, KHS25.1, KHS31.1, U1.36 (P0_05_AIN3)
/Col7: KHS20.1, KHS26.1, KHS32.1, U1.47 (P0_23)
/Col8: KHS21.1, KHS27.1, KHS33.1, U1.45 (P0_19)
/Col9: KHS22.1, KHS28.1, KHS34.1, U1.43 (P0_11_TRACEDATA)
/Col10: KHS23.1, KHS29.1, KHS35.1, U1.41 (P0_25)
/Col11: KHS24.1, KHS30.1, KHS36.1, U1.39 (P0_27)
/LED_1: LED1.1 (K), U1.52 (P1_14)
/LED_2: LED2.1 (K), U1.59 (P1_12)
/PVSS2: C4.1, C8.1, NT1.1, U3.6 (PVSS2)
/RESET: J1.6, SW1.1 (NO_1), SW1.2 (NO_2), U1.13 (P0_18_RESET)
/Row0: D1.1 (K), D2.1 (K), D3.1 (K), D4.1 (K), D5.1 (K), D6.1 (K), D19.1 (K), D20.1 (K), D21.1 (K), D22.1 (K), D23.1 (K), D24.1 (K), U1.56 (P1_09_TRACEDATA3)
/Row1: D7.1 (K), D8.1 (K), D9.1 (K), D10.1 (K), D11.1 (K), D12.1 (K), D25.1 (K), D26.1 (K), D27.1 (K), D28.1 (K), D29.1 (K), D30.1 (K), U1.63 (P1_04)
/Row2: D13.1 (K), D14.1 (K), D15.1 (K), D16.1 (K), D17.1 (K), D18.1 (K), D31.1 (K), D32.1 (K), D33.1 (K), D34.1 (K), D35.1 (K), D36.1 (K), U1.9 (P0_16)
/SCL: J4.3, U1.35 (P0_04_AIN2)
/SDA: J4.4, U1.33 (P0_07_TRACECLK)
/SWDCLK: J1.4, U1.30 (SWDCLK)
/SWDIO: J1.2, U1.28 (SWDIO)
/USB_D+: J2.A6 (D+), J2.B6 (D+), U1.8 (D+), U2.2 (NC), U2.5 (D+)
/USB_D-: J2.A7 (D-), J2.B7 (D-), U1.10 (D-), U2.3 (NC), U2.4 (D-)
/VBAT: C9.1, SW2.3 (C), U3.19 (VBAT)
/VBUS: C1.1, C6.1, J2.A4 (VBUS), J2.A9 (VBUS), J2.B4 (VBUS), J2.B9 (VBUS), U2.6 (VBUS), U3.21 (VBUS)
/VBUSOut: C7.1, TP2.1, U1.12 (VBUS), U3.22 (VBUSOUT)
/VSYS: C4.2, C5.2, R3.2, R4.2, U3.1 (VOUT1), U3.4 (PVDD), U3.20 (VSYS)
GND: C1.2, C2.2, C3.1, C5.1, C6.2, C7.2, C9.2, H1.1, H2.1, H3.1, H4.1, J1.3, J1.5, J2.A1 (GND), J2.A12 (GND), J2.B1 (GND), J2.B12 (GND), J3.1, J4.1, NT1.2, R7.2, SW1.3 (COM_1), SW1.4 (COM_2), TP1.1, U1.1 (VSS), U1.7 (VSS), U1.14 (VSS), U1.16 (VSS), U1.18 (VSS), U1.21 (VSS), U1.23 (VSS), U1.24 (VSS), U1.25 (VSS), U1.31 (VSS), U2.1 (GND), U3.2 (PVSS1), U3.17 (VSET1), U3.18 (NTC), U3.28 (LSIN1/VINLDO1), U3.29 (LSOUT1/VOUTLDO1), U3.30 (LSIN2/VINLDO2), U3.31 (LSOUT2/VOUTLDO2), U3.33 (AVSS)
unnamed: D1.2 (A), KHS1.2
unnamed: D2.2 (A), KHS2.2
unnamed: D3.2 (A), KHS3.2
unnamed: D4.2 (A), KHS4.2
unnamed: D5.2 (A), KHS5.2
unnamed: D6.2 (A), KHS6.2
unnamed: D7.2 (A), KHS7.2
unnamed: D8.2 (A), KHS8.2
unnamed: D9.2 (A), KHS9.2
unnamed: D10.2 (A), KHS10.2
unnamed: D11.2 (A), KHS11.2
unnamed: D12.2 (A), KHS12.2
unnamed: D13.2 (A), KHS13.2
unnamed: D14.2 (A), KHS14.2
unnamed: D15.2 (A), KHS15.2
unnamed: D16.2 (A), KHS16.2
unnamed: D17.2 (A), KHS17.2
unnamed: D18.2 (A), KHS18.2
unnamed: D19.2 (A), KHS19.2
unnamed: D20.2 (A), KHS20.2
unnamed: D21.2 (A), KHS21.2
unnamed: D22.2 (A), KHS22.2
unnamed: D23.2 (A), KHS23.2
unnamed: D24.2 (A), KHS24.2
unnamed: D25.2 (A), KHS25.2
unnamed: D26.2 (A), KHS26.2
unnamed: D27.2 (A), KHS27.2
unnamed: D28.2 (A), KHS28.2
unnamed: D29.2 (A), KHS29.2
unnamed: D30.2 (A), KHS30.2
unnamed: D31.2 (A), KHS31.2
unnamed: D32.2 (A), KHS32.2
unnamed: D33.2 (A), KHS33.2
unnamed: D34.2 (A), KHS34.2
unnamed: D35.2 (A), KHS35.2
unnamed: D36.2 (A), KHS36.2
unnamed: D37.2 (A), R3.1
unnamed: D37.1 (K), U3.25 (LED0)
unnamed: D38.2 (A), R4.1
unnamed: D38.1 (K), U3.26 (LED1)
unnamed: C2.1, J2.S1 (SHIELD)
unnamed: J3.2, SW2.2 (B)
unnamed: LED1.2 (A), R1.2
unnamed: LED2.2 (A), R2.2
unnamed: U1.20 (OUT_ANT), U1.22 (OUT_MOD)
unnamed: L1.2, U3.5 (SW2)
unnamed: R7.1, U3.16 (VSET2)

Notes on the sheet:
Index
Status LED
Ring
Key
Middle
V_{f} < 3.0V
BMIC + Power
USB Connector + ESD
Pinkie
Thumbs
OuterIndex
VIA to GND

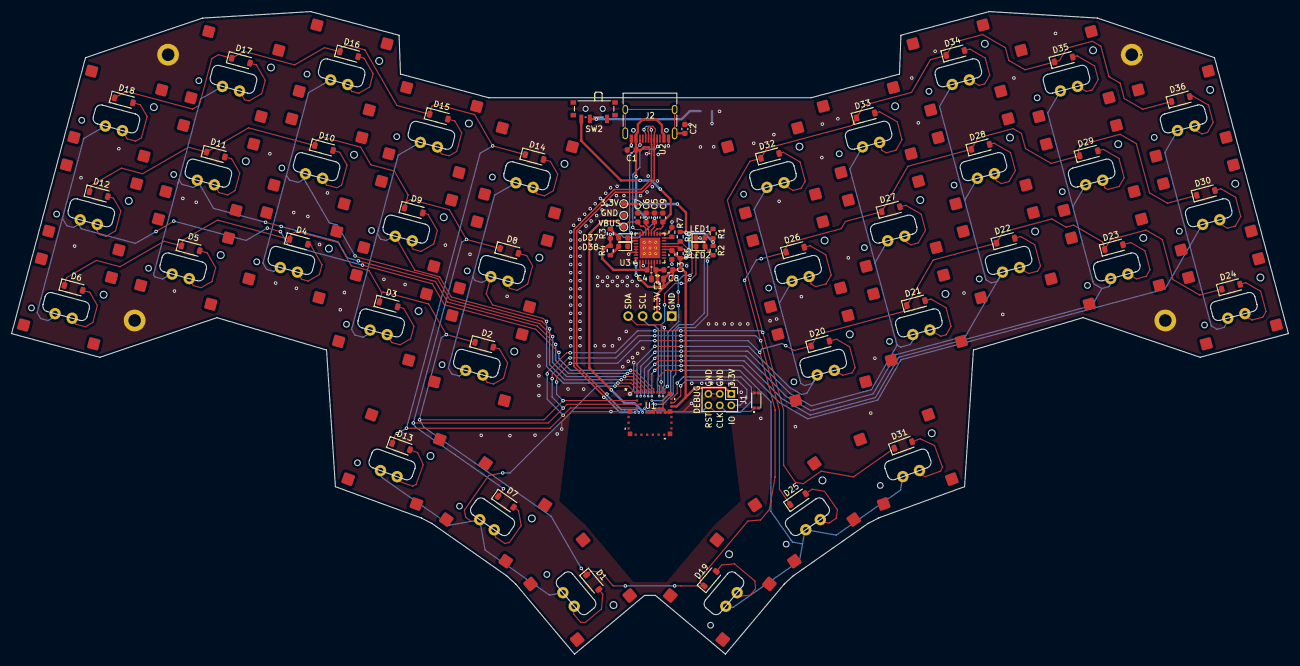
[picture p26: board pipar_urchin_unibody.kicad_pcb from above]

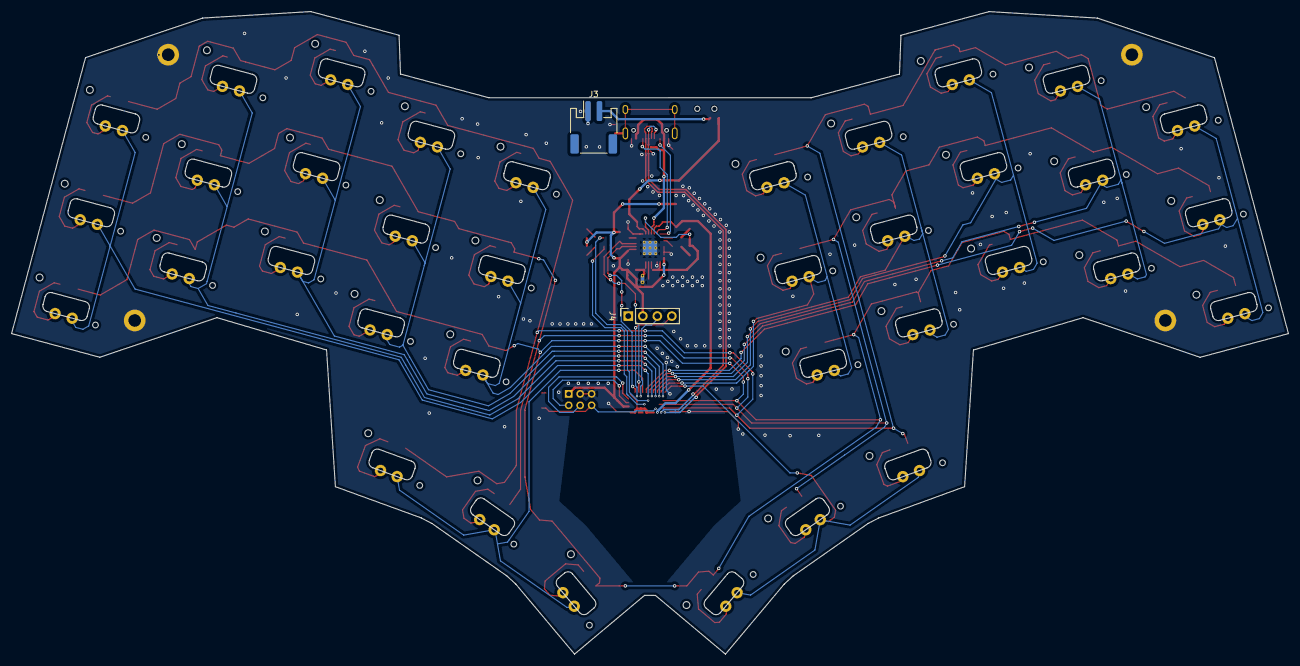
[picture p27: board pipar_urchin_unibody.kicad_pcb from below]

Board: 2 copper layers, 223.5 x 112.5 mm, 110 parts (3 on the bottom side), 82 nets.

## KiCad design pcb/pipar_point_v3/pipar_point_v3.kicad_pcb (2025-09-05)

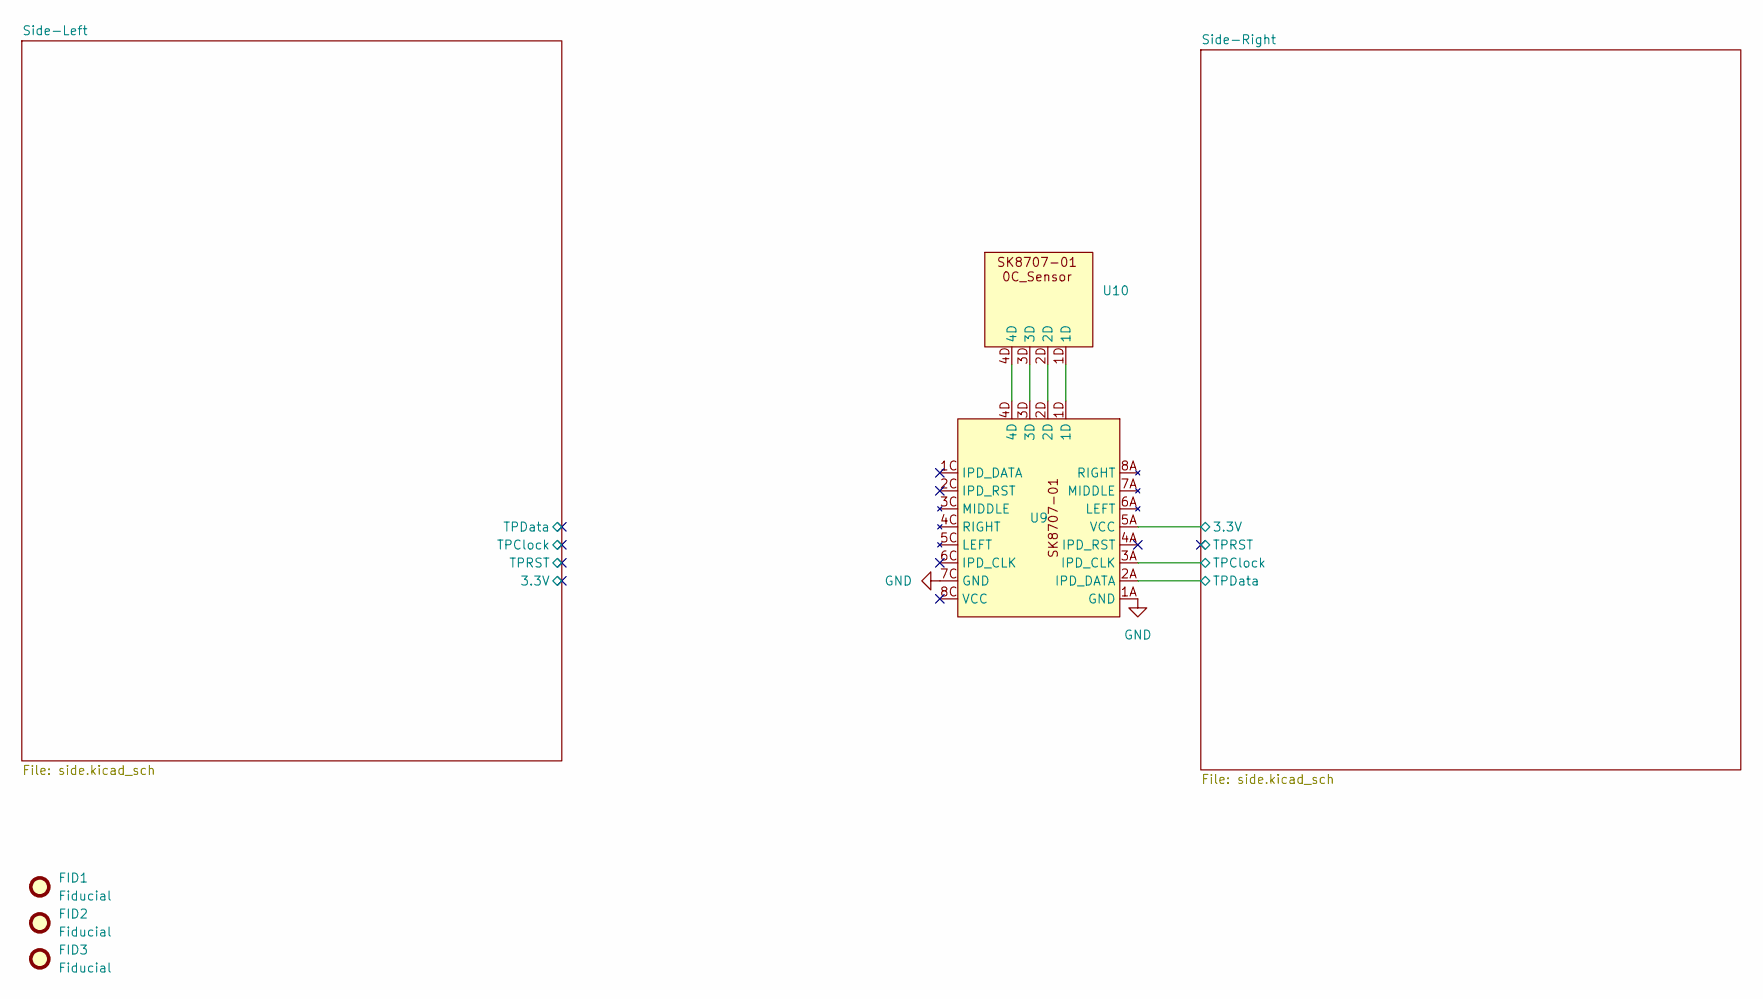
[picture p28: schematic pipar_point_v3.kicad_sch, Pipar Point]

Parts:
FID1, FID2, FID3: Fiducial; Fiducial_0.5mm_Mask1mm
U9: SK8707-01
U10: SK8707-01-0C Sensor

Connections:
/Side-Right/3.3V: U9.5A (VCC); also elsewhere on the board
/Side-Right/TPClock: U9.3A (IPD_CLK); also elsewhere on the board
/Side-Right/TPData: U9.2A (IPD_DATA); also elsewhere on the board
GND: U9.1A (GND), U9.7C (GND); also elsewhere on the board
unnamed: U9.1D, U10.1D
unnamed: U9.4D, U10.4D
unnamed: U9.2D, U10.2D
unnamed: U9.3D, U10.3D

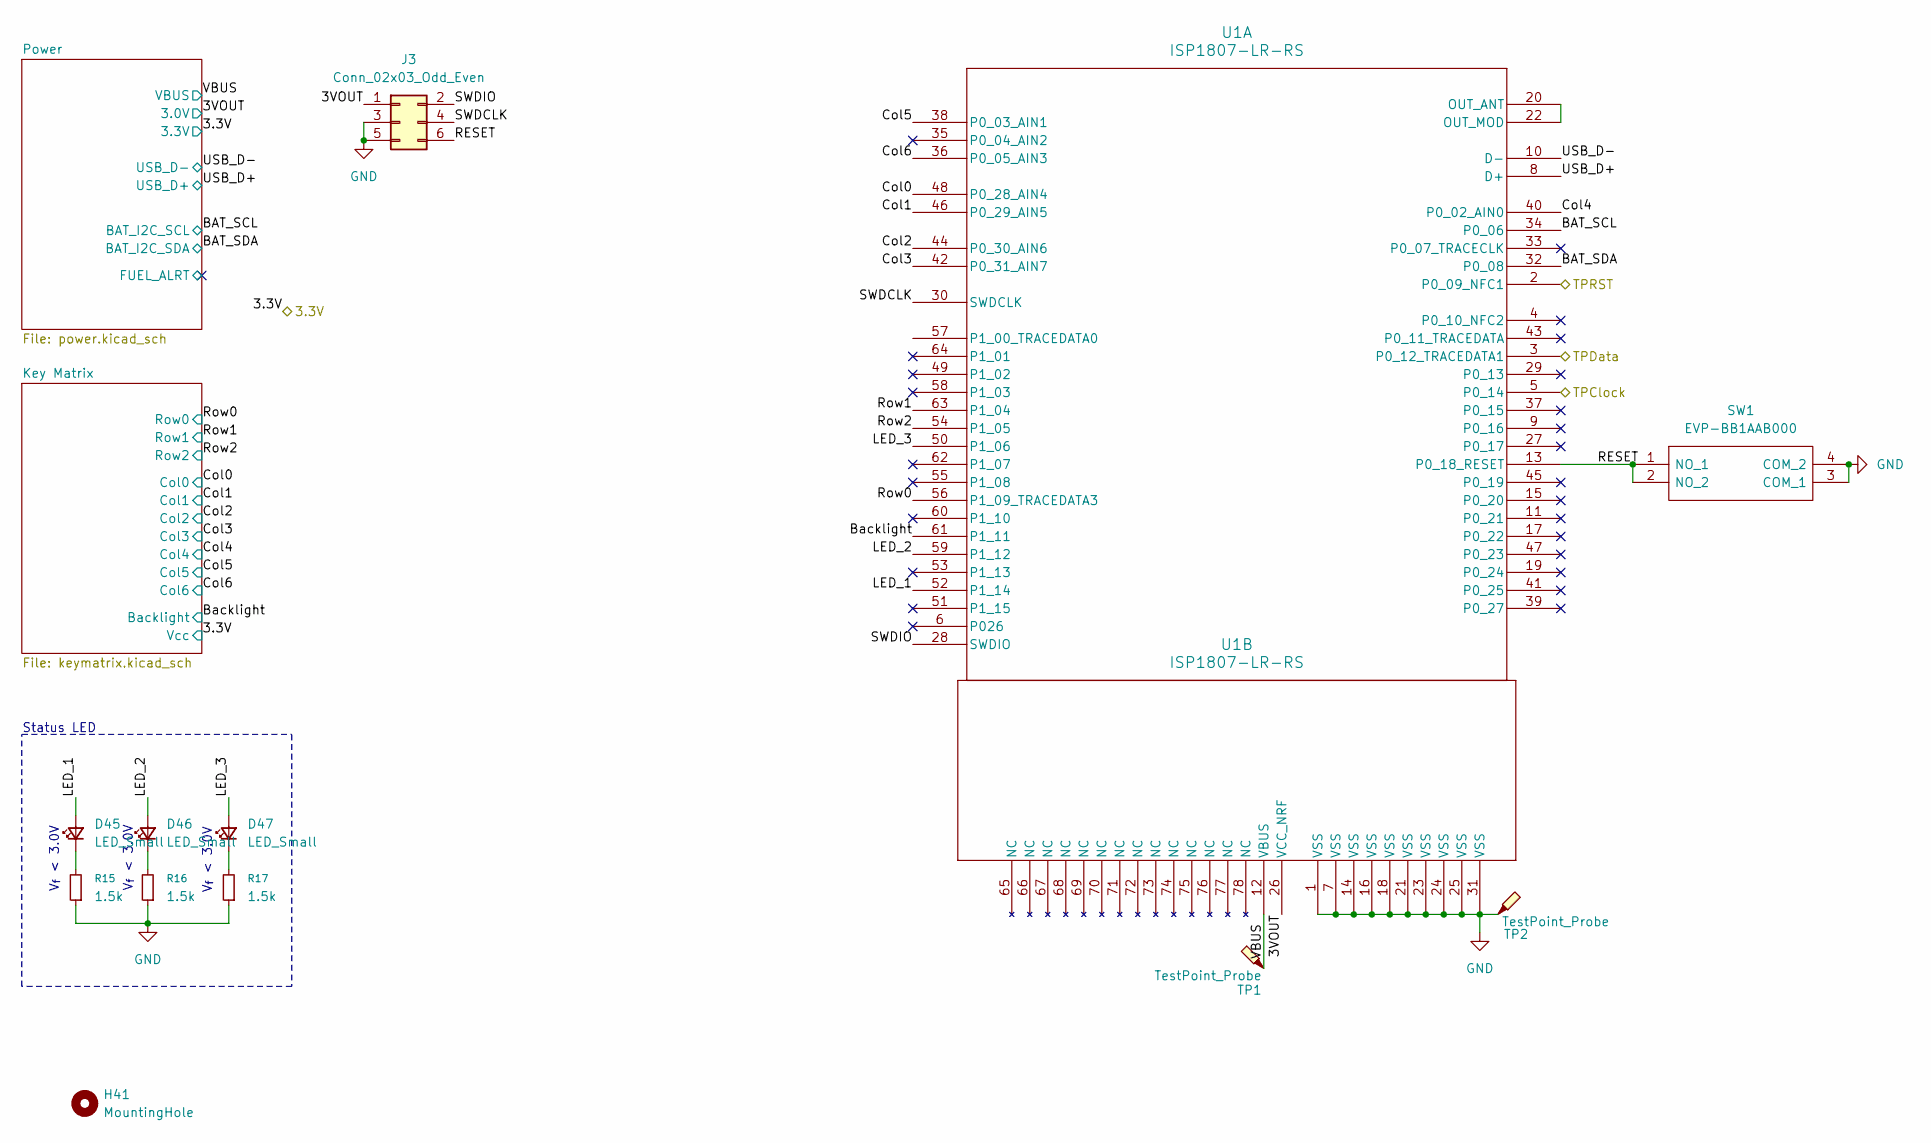
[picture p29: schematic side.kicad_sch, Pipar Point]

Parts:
D45: LED_Small; LED_0603_1608Metric; Manufacturer_Part_Number IN-PIS63BTPR; Mouser Part Number 743-IN-PIS63BTPR
D46: LED_Small; LED_0603_1608Metric; Manufacturer_Part_Number IN-PIS63BTPG; Mouser Part Number 743-IN-PIS63BTPG
D47: LED_Small; LED_0603_1608Metric; Manufacturer_Part_Number IN-PIS63BTPB; Mouser Part Number 743-IN-PIS63BTPB
H41: MountingHole; Salt-smallest
J3: Conn_02x03_Odd_Even; PinHeader_2x03_P2.00mm_Vertical
R15, R16, R17: 1.5k; R_0603_1608Metric; Manufacturer_Part_Number RC0603FR-071K5L; Mouser Part Number 603-RC0603FR-071K5L
SW1: EVP-BB1AAB000; EVPBB2A9B000; Mouser Part Number 667-EVP-BB1AAB000
TP1, TP2: TestPoint_Probe; TestPoint_Pad_D1.0mm
U1: ISP1807-LR-RS; Manufacturer_Part_Number ISP1807-LR-RS; Mouser Part Number 359-ISP1807-LR-RS

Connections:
/Side-Left/3VOUT: J3.1, U1.26 (VCC_NRF); also elsewhere on the board
/Side-Left/BAT_SCL: U1.34 (P0_06); also elsewhere on the board
/Side-Left/BAT_SDA: U1.32 (P0_08); also elsewhere on the board
/Side-Left/Backlight: U1.61 (P1_11); also elsewhere on the board
/Side-Left/Col0: U1.48 (P0_28_AIN4); also elsewhere on the board
/Side-Left/Col1: U1.46 (P0_29_AIN5); also elsewhere on the board
/Side-Left/Col2: U1.44 (P0_30_AIN6); also elsewhere on the board
/Side-Left/Col3: U1.42 (P0_31_AIN7); also elsewhere on the board
/Side-Left/Col4: U1.40 (P0_02_AIN0); also elsewhere on the board
/Side-Left/Col5: U1.38 (P0_03_AIN1); also elsewhere on the board
/Side-Left/Col6: U1.36 (P0_05_AIN3); also elsewhere on the board
/Side-Left/LED_1: D45.2 (A), U1.52 (P1_14)
/Side-Left/LED_2: D46.2 (A), U1.59 (P1_12)
/Side-Left/LED_3: D47.2 (A), U1.50 (P1_06)
/Side-Left/RESET: J3.6, SW1.1 (NO_1), SW1.2 (NO_2), U1.13 (P0_18_RESET)
/Side-Left/Row0: U1.56 (P1_09_TRACEDATA3); also elsewhere on the board
/Side-Left/Row1: U1.63 (P1_04); also elsewhere on the board
/Side-Left/Row2: U1.54 (P1_05); also elsewhere on the board
/Side-Left/SWDCLK: J3.4, U1.30 (SWDCLK)
/Side-Left/SWDIO: J3.2, U1.28 (SWDIO)
/Side-Left/TPClock: U1.5 (P0_14)
/Side-Left/TPData: U1.3 (P0_12_TRACEDATA1)
/Side-Left/TPRST: U1.2 (P0_09_NFC1)
/Side-Left/USB_D+: U1.8 (D+); also elsewhere on the board
/Side-Left/USB_D-: U1.10 (D-); also elsewhere on the board
/Side-Left/VBUS: TP1.1, U1.12 (VBUS); also elsewhere on the board
GND: J3.3, J3.5, R15.1, R16.1, R17.1, SW1.3 (COM_1), SW1.4 (COM_2), TP2.1, U1.1 (VSS), U1.7 (VSS), U1.14 (VSS), U1.16 (VSS), U1.18 (VSS), U1.21 (VSS), U1.23 (VSS), U1.24 (VSS), U1.25 (VSS), U1.31 (VSS); also elsewhere on the board
unnamed: D45.1 (K), R15.2
unnamed: D46.1 (K), R16.2
unnamed: D47.1 (K), R17.2
unnamed: U1.20 (OUT_ANT), U1.22 (OUT_MOD)

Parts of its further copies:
D48: LED_Small; LED_0603_1608Metric; Manufacturer_Part_Number IN-PIS63BTPR; Mouser Part Number 743-IN-PIS63BTPR
D49: LED_Small; LED_0603_1608Metric; Manufacturer_Part_Number IN-PIS63BTPG; Mouser Part Number 743-IN-PIS63BTPG
D50: LED_Small; LED_0603_1608Metric; Manufacturer_Part_Number IN-PIS63BTPB; Mouser Part Number 743-IN-PIS63BTPB
H42: MountingHole; Salt-smallest
J4: Conn_02x03_Odd_Even; PinHeader_2x03_P2.00mm_Vertical
R18, R19, R20: 1.5k; R_0603_1608Metric; Manufacturer_Part_Number RC0603FR-071K5L; Mouser Part Number 603-RC0603FR-071K5L
SW2: EVP-BB1AAB000; EVPBB2A9B000; Mouser Part Number 667-EVP-BB1AAB000
TP3, TP4: TestPoint_Probe; TestPoint_Pad_D1.0mm
U2: ISP1807-LR-RS; Manufacturer_Part_Number ISP1807-LR-RS; Mouser Part Number 359-ISP1807-LR-RS

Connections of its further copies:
/Side-Right/3VOUT: J4.1, U2.26 (VCC_NRF); also elsewhere on the board
/Side-Right/BAT_SCL: U2.34 (P0_06); also elsewhere on the board
/Side-Right/BAT_SDA: U2.32 (P0_08); also elsewhere on the board
/Side-Right/Backlight: U2.61 (P1_11); also elsewhere on the board
/Side-Right/Col0: U2.48 (P0_28_AIN4); also elsewhere on the board
/Side-Right/Col1: U2.46 (P0_29_AIN5); also elsewhere on the board
/Side-Right/Col2: U2.44 (P0_30_AIN6); also elsewhere on the board
/Side-Right/Col3: U2.42 (P0_31_AIN7); also elsewhere on the board
/Side-Right/Col4: U2.40 (P0_02_AIN0); also elsewhere on the board
/Side-Right/Col5: U2.38 (P0_03_AIN1); also elsewhere on the board
/Side-Right/Col6: U2.36 (P0_05_AIN3); also elsewhere on the board
/Side-Right/LED_1: D48.2 (A), U2.52 (P1_14)
/Side-Right/LED_2: D49.2 (A), U2.59 (P1_12)
/Side-Right/LED_3: D50.2 (A), U2.50 (P1_06)
/Side-Right/RESET: J4.6, SW2.1 (NO_1), SW2.2 (NO_2), U2.13 (P0_18_RESET)
/Side-Right/Row0: U2.56 (P1_09_TRACEDATA3); also elsewhere on the board
/Side-Right/Row1: U2.63 (P1_04); also elsewhere on the board
/Side-Right/Row2: U2.54 (P1_05); also elsewhere on the board
/Side-Right/SWDCLK: J4.4, U2.30 (SWDCLK)
/Side-Right/SWDIO: J4.2, U2.28 (SWDIO)
/Side-Right/TPClock: U2.5 (P0_14); also elsewhere on the board
/Side-Right/TPData: U2.3 (P0_12_TRACEDATA1); also elsewhere on the board
/Side-Right/TPRST: U2.2 (P0_09_NFC1)
/Side-Right/USB_D+: U2.8 (D+); also elsewhere on the board
/Side-Right/USB_D-: U2.10 (D-); also elsewhere on the board
/Side-Right/VBUS: TP3.1, U2.12 (VBUS); also elsewhere on the board
GND: J4.3, J4.5, R18.1, R19.1, R20.1, SW2.3 (COM_1), SW2.4 (COM_2), TP4.1, U2.1 (VSS), U2.7 (VSS), U2.14 (VSS), U2.16 (VSS), U2.18 (VSS), U2.21 (VSS), U2.23 (VSS), U2.24 (VSS), U2.25 (VSS), U2.31 (VSS); also elsewhere on the board
unnamed: D48.1 (K), R18.2
unnamed: D49.1 (K), R19.2
unnamed: D50.1 (K), R20.2
unnamed: U2.20 (OUT_ANT), U2.22 (OUT_MOD)

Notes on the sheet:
V_{f} < 3.0V
Status LED

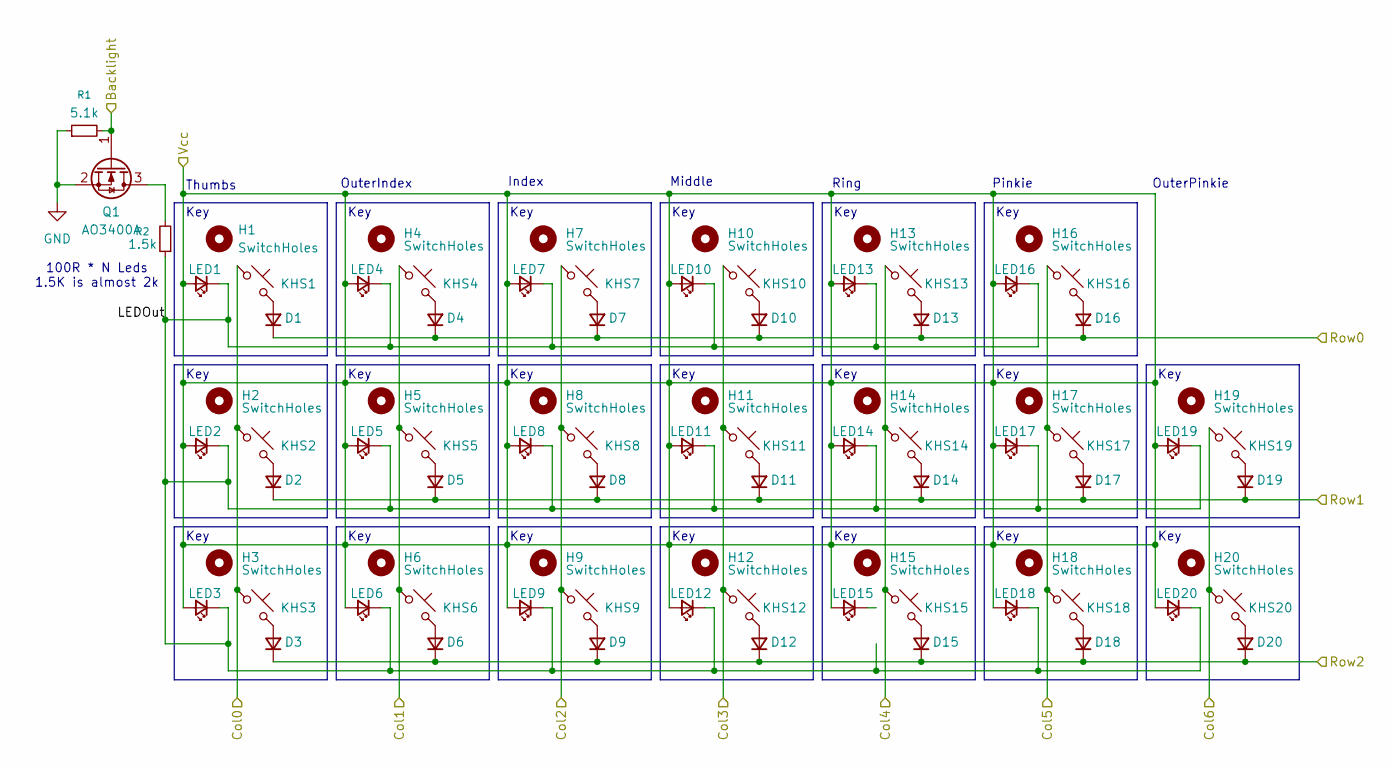
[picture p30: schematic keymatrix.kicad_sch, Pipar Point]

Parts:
D1, D2, D3, D4, D5, D6, D7, D8, D9, D10, D11, D12, D13, D14, D15, D16, D17, D18, D19, D20: D_Small; D_SOD-523
H1, H2, H3, H4, H5, H6, H7, H8, H9, H10, H11, H12, H13, H14, H15, H16, H17, H18, H19, H20: SwitchHoles; SwitchHoles_Kailh_Choc_V1V2
KHS1, KHS2, KHS3, KHS4, KHS5, KHS6, KHS7, KHS8, KHS9, KHS10, KHS11, KHS12, KHS13, KHS14, KHS15, KHS16, KHS17, KHS18, KHS19, KHS20: KHS; Kailh_HS_Socket
LED1, LED2, LED3, LED4, LED5, LED6, LED7, LED8, LED9, LED10, LED11, LED12, LED13, LED14, LED15, LED16, LED17, LED18, LED19, LED20: LED_Small; LED_0603_1608Metric
Q1: AO3400A; SOT-23; Manufacturer_Part_Number IRLML6344TRPBF; Mouser Part Number 942-IRLML6344TRPBF
R1: 5.1k; R_0603_1608Metric; Manufacturer_Part_Number 603-RC0603FR-075K1L; Mouser Part Number 603-RC0603FR-075K1L
R2: 1.5k; R_0603_1608Metric; Manufacturer_Part_Number RC0603FR-071K5L; Mouser Part Number 603-RC0603FR-071K5L

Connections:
/Side-Left/3.3V: LED1.2 (A), LED2.2 (A), LED3.2 (A), LED4.2 (A), LED5.2 (A), LED6.2 (A), LED7.2 (A), LED8.2 (A), LED9.2 (A), LED10.2 (A), LED11.2 (A), LED12.2 (A), LED13.2 (A), LED14.2 (A), LED15.2 (A), LED16.2 (A), LED17.2 (A), LED18.2 (A), LED19.2 (A), LED20.2 (A); also elsewhere on the board
/Side-Left/Backlight: Q1.1 (G), R1.2; also elsewhere on the board
/Side-Left/Col0: KHS1.1, KHS2.1, KHS3.1; also elsewhere on the board
/Side-Left/Col1: KHS4.1, KHS5.1, KHS6.1; also elsewhere on the board
/Side-Left/Col2: KHS7.1, KHS8.1, KHS9.1; also elsewhere on the board
/Side-Left/Col3: KHS10.1, KHS11.1, KHS12.1; also elsewhere on the board
/Side-Left/Col4: KHS13.1, KHS14.1, KHS15.1; also elsewhere on the board
/Side-Left/Col5: KHS16.1, KHS17.1, KHS18.1; also elsewhere on the board
/Side-Left/Col6: KHS19.1, KHS20.1; also elsewhere on the board
/Side-Left/Key Matrix/LEDOut: LED1.1 (K), LED2.1 (K), LED3.1 (K), LED4.1 (K), LED5.1 (K), LED6.1 (K), LED7.1 (K), LED8.1 (K), LED9.1 (K), LED10.1 (K), LED11.1 (K), LED12.1 (K), LED13.1 (K), LED14.1 (K), LED16.1 (K), LED17.1 (K), LED18.1 (K), LED19.1 (K), LED20.1 (K), R2.1
/Side-Left/Row0: D1.1 (K), D4.1 (K), D7.1 (K), D10.1 (K), D13.1 (K), D16.1 (K); also elsewhere on the board
/Side-Left/Row1: D2.1 (K), D5.1 (K), D8.1 (K), D11.1 (K), D14.1 (K), D17.1 (K), D19.1 (K); also elsewhere on the board
/Side-Left/Row2: D3.1 (K), D6.1 (K), D9.1 (K), D12.1 (K), D15.1 (K), D18.1 (K), D20.1 (K); also elsewhere on the board
GND: Q1.2 (S), R1.1; also elsewhere on the board
unnamed: D1.2 (A), KHS1.2
unnamed: D2.2 (A), KHS2.2
unnamed: D3.2 (A), KHS3.2
unnamed: D4.2 (A), KHS4.2
unnamed: D5.2 (A), KHS5.2
unnamed: D6.2 (A), KHS6.2
unnamed: D7.2 (A), KHS7.2
unnamed: D8.2 (A), KHS8.2
unnamed: D9.2 (A), KHS9.2
unnamed: D10.2 (A), KHS10.2
unnamed: D11.2 (A), KHS11.2
unnamed: D12.2 (A), KHS12.2
unnamed: D13.2 (A), KHS13.2
unnamed: D14.2 (A), KHS14.2
unnamed: D15.2 (A), KHS15.2
unnamed: D16.2 (A), KHS16.2
unnamed: D17.2 (A), KHS17.2
unnamed: D18.2 (A), KHS18.2
unnamed: D19.2 (A), KHS19.2
unnamed: D20.2 (A), KHS20.2
unnamed: Q1.3 (D), R2.2

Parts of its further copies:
D25, D26, D27, D28, D29, D30, D31, D32, D33, D34, D35, D36, D37, D38, D39, D40, D41, D42, D43, D44: D_Small; D_SOD-523
H21, H22, H23, H24, H25, H26, H27, H28, H29, H30, H31, H32, H33, H34, H35, H36, H37, H38, H39, H40: SwitchHoles; SwitchHoles_Kailh_Choc_V1V2
KHS21, KHS22, KHS23, KHS24, KHS25, KHS26, KHS27, KHS28, KHS29, KHS30, KHS31, KHS32, KHS33, KHS34, KHS35, KHS36, KHS37, KHS38, KHS39, KHS40: KHS; Kailh_HS_Socket
LED21, LED22, LED23, LED24, LED25, LED26, LED27, LED28, LED29, LED30, LED31, LED32, LED33, LED34, LED35, LED36, LED37, LED38, LED39, LED40: LED_Small; LED_0603_1608Metric
Q2: AO3400A; SOT-23; Manufacturer_Part_Number IRLML6344TRPBF; Mouser Part Number 942-IRLML6344TRPBF
R13: 5.1k; R_0603_1608Metric; Manufacturer_Part_Number 603-RC0603FR-075K1L; Mouser Part Number 603-RC0603FR-075K1L
R14: 1.5k; R_0603_1608Metric; Manufacturer_Part_Number RC0603FR-071K5L; Mouser Part Number 603-RC0603FR-071K5L

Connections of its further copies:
/Side-Right/3.3V: LED21.2 (A), LED22.2 (A), LED23.2 (A), LED24.2 (A), LED25.2 (A), LED26.2 (A), LED27.2 (A), LED28.2 (A), LED29.2 (A), LED30.2 (A), LED31.2 (A), LED32.2 (A), LED33.2 (A), LED34.2 (A), LED35.2 (A), LED36.2 (A), LED37.2 (A), LED38.2 (A), LED39.2 (A), LED40.2 (A); also elsewhere on the board
/Side-Right/Backlight: Q2.1 (G), R13.2; also elsewhere on the board
/Side-Right/Col0: KHS21.1, KHS22.1, KHS23.1; also elsewhere on the board
/Side-Right/Col1: KHS24.1, KHS25.1, KHS26.1; also elsewhere on the board
/Side-Right/Col2: KHS27.1, KHS28.1, KHS29.1; also elsewhere on the board
/Side-Right/Col3: KHS30.1, KHS31.1, KHS32.1; also elsewhere on the board
/Side-Right/Col4: KHS33.1, KHS34.1, KHS35.1; also elsewhere on the board
/Side-Right/Col5: KHS36.1, KHS37.1, KHS38.1; also elsewhere on the board
/Side-Right/Col6: KHS39.1, KHS40.1; also elsewhere on the board
/Side-Right/Key Matrix/LEDOut: LED21.1 (K), LED22.1 (K), LED23.1 (K), LED24.1 (K), LED25.1 (K), LED26.1 (K), LED27.1 (K), LED28.1 (K), LED29.1 (K), LED30.1 (K), LED31.1 (K), LED32.1 (K), LED33.1 (K), LED34.1 (K), LED36.1 (K), LED37.1 (K), LED38.1 (K), LED39.1 (K), LED40.1 (K), R14.1
/Side-Right/Row0: D25.1 (K), D28.1 (K), D31.1 (K), D34.1 (K), D37.1 (K), D40.1 (K); also elsewhere on the board
/Side-Right/Row1: D26.1 (K), D29.1 (K), D32.1 (K), D35.1 (K), D38.1 (K), D41.1 (K), D43.1 (K); also elsewhere on the board
/Side-Right/Row2: D27.1 (K), D30.1 (K), D33.1 (K), D36.1 (K), D39.1 (K), D42.1 (K), D44.1 (K); also elsewhere on the board
GND: Q2.2 (S), R13.1; also elsewhere on the board
unnamed: D25.2 (A), KHS21.2
unnamed: D26.2 (A), KHS22.2
unnamed: D27.2 (A), KHS23.2
unnamed: D28.2 (A), KHS24.2
unnamed: D29.2 (A), KHS25.2
unnamed: D30.2 (A), KHS26.2
unnamed: D31.2 (A), KHS27.2
unnamed: D32.2 (A), KHS28.2
unnamed: D33.2 (A), KHS29.2
unnamed: D34.2 (A), KHS30.2
unnamed: D35.2 (A), KHS31.2
unnamed: D36.2 (A), KHS32.2
unnamed: D37.2 (A), KHS33.2
unnamed: D38.2 (A), KHS34.2
unnamed: D39.2 (A), KHS35.2
unnamed: D40.2 (A), KHS36.2
unnamed: D41.2 (A), KHS37.2
unnamed: D42.2 (A), KHS38.2
unnamed: D43.2 (A), KHS39.2
unnamed: D44.2 (A), KHS40.2
unnamed: Q2.3 (D), R14.2

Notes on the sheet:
Key
Ring
Index
100R * N Leds 1.5K is almost 2k
OuterIndex
Pinkie
OuterPinkie
Thumbs
Middle

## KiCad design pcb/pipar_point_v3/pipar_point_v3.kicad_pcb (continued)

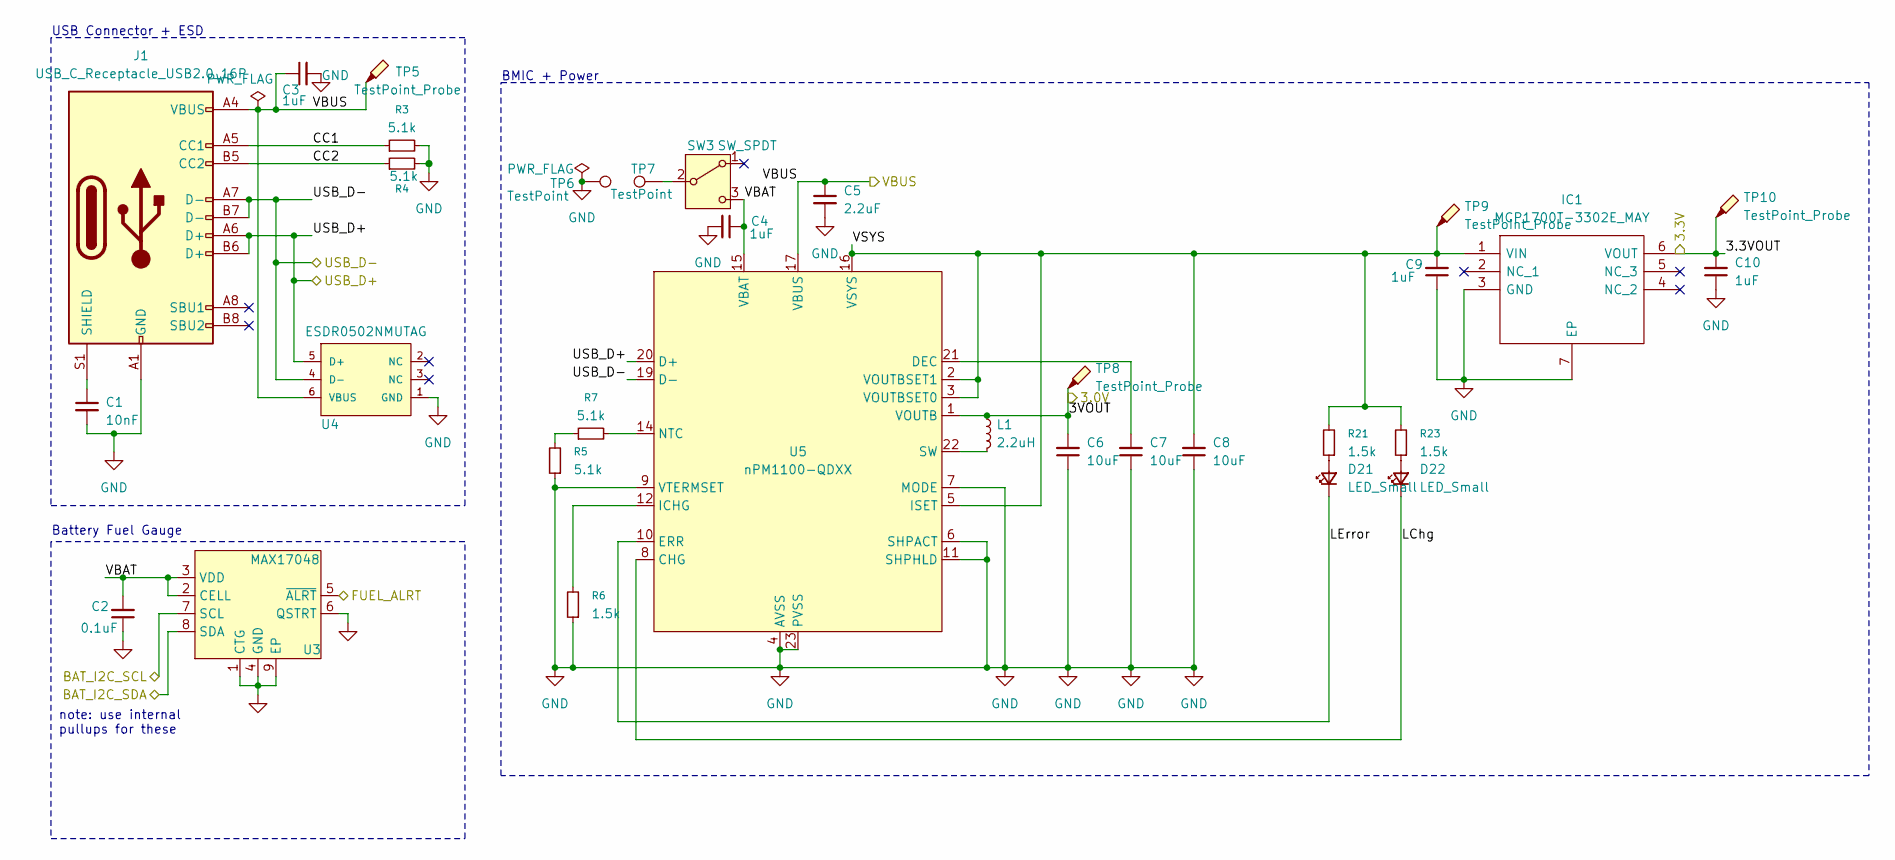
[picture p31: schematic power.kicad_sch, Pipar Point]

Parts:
C1: 10nF; C_0603_1608Metric; Mouser Part Number 810-C1608X5R1H103KAA
C2: 0.1uF; C_0603_1608Metric; Mouser Part Number 603-CC603KRX7R5BB105
C3, C4, C9, C10: 1uF; C_0603_1608Metric; Mouser Part Number 603-CC603KRX7R5BB105
C5: 2.2uF; C_0603_1608Metric; Mouser Part Number 810-C1608X5R1E225M
C6, C7, C8: 10uF; C_0603_1608Metric; Mouser Part Number 810-C1608X5R0J106K
D21: LED_Small; LED_0603_1608Metric; Manufacturer_Part_Number IN-PIS63BTPR; Mouser Part Number 743-IN-PIS63BTPR
D22: LED_Small; LED_0603_1608Metric; Manufacturer_Part_Number IN-PIS63BTPG; Mouser Part Number 743-IN-PIS63BTPG
IC1: MCP1700T-3302E_MAY; SON65P200X200X90-7N; Manufacturer_Part_Number MCP1700T-3302E/MAY; Mouser Part Number 579-MCP1700T3302EMAY
J1: USB_C_Receptacle_USB2.0_16P; USB_C_Receptacle_HRO_TYPE-C-31-M-12
L1: 2.2uH; L_0805_2012Metric; Manufacturer_Part_Number MLZ2012A2R2WT000; Mouser Part Number 810-MLZ2012A2R2WT000
R3, R4, R5, R7: 5.1k; R_0603_1608Metric; Manufacturer_Part_Number 603-RC0603FR-075K1L; Mouser Part Number 603-RC0603FR-075K1L
R6, R21, R23: 1.5k; R_0603_1608Metric; Manufacturer_Part_Number RC0603FR-071K5L; Mouser Part Number 603-RC0603FR-071K5L
SW3: SW_SPDT; SW_SPDT_PCM12; Manufacturer_Part_Number PCM12SMTBR; Mouser Part Number 611-PCM12SMTBR
TP5, TP8, TP9, TP10: TestPoint_Probe; TestPoint_Pad_D1.0mm
TP6: TestPoint; TestPoint_Pad_1.5x1.5mm
TP7: TestPoint; TestPoint_Pad_D1.5mm
U3: MAX17048; TDFN-8-1EP_2x2mm_P0.5mm_EP0.8x1.2mm; LCSC Part C2682616
U4: ESDR0502NMUTAG; UDFN-6_1.2x1.0mm_P0.4mm; Manufacturer Part ESDR0502NMUTBG; LCSC C327480
U5: nPM1100-QDXX; QFN-24-1EP_4x4mm_P0.5mm_EP2.6x2.6mm_ThermalVias; Manufacturer_Part_Number NPM1100-QDAA-R; Mouser Part Number 949-NPM1100-QDAA-R

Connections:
/Side-Left/3.3V: C10.2, IC1.6 (VOUT), TP10.1; also elsewhere on the board
/Side-Left/3VOUT: C6.2, L1.1, TP8.1, U5.1 (VOUTB); also elsewhere on the board
/Side-Left/BAT_SCL: U3.7 (SCL); also elsewhere on the board
/Side-Left/BAT_SDA: U3.8 (SDA); also elsewhere on the board
/Side-Left/Power/CC1: J1.A5 (CC1), R3.1
/Side-Left/Power/CC2: J1.B5 (CC2), R4.1
/Side-Left/Power/FUEL_ALRT: U3.5 (~ALRT)
/Side-Left/Power/LChg: D22.1 (K), U5.8 (CHG)
/Side-Left/Power/LError: D21.1 (K), U5.10 (ERR)
/Side-Left/Power/VBAT: C2.2, C4.1, SW3.3 (C), U3.2 (CELL), U3.3 (VDD), U5.15 (VBAT)
/Side-Left/Power/VSYS: C8.2, C9.2, IC1.1 (VIN), R21.2, R23.2, TP9.1, U5.2 (VOUTBSET1), U5.3 (VOUTBSET0), U5.5 (ISET), U5.16 (VSYS)
/Side-Left/USB_D+: J1.A6 (D+), J1.B6 (D+), U4.5 (D+), U5.20 (D+); also elsewhere on the board
/Side-Left/USB_D-: J1.A7 (D-), J1.B7 (D-), U4.4 (D-), U5.19 (D-); also elsewhere on the board
/Side-Left/VBUS: C3.1, C5.1, J1.A4 (VBUS), J1.A9 (VBUS), J1.B4 (VBUS), J1.B9 (VBUS), TP5.1, U4.6 (VBUS), U5.17 (VBUS); also elsewhere on the board
GND: C1.2, C2.1, C3.2, C4.2, C5.2, C6.1, C7.1, C8.1, C9.1, C10.1, IC1.3 (GND), IC1.7 (EP), J1.A1 (GND), J1.A12 (GND), J1.B1 (GND), J1.B12 (GND), R3.2, R4.2, R5.1, R6.1, TP6.1, U3.1 (CTG), U3.4 (GND), U3.6 (QSTRT), U3.9 (EP), U4.1 (GND), U5.4 (AVSS), U5.6 (SHPACT), U5.7 (MODE), U5.9 (VTERMSET), U5.11 (SHPHLD), U5.23 (PVSS), U5.25 (AVSS); also elsewhere on the board
unnamed: D21.2 (A), R21.1
unnamed: D22.2 (A), R23.1
unnamed: C1.1, J1.S1 (SHIELD)
unnamed: R5.2, R7.1
unnamed: SW3.2 (B), TP7.1
unnamed: C7.2, U5.21 (DEC)
unnamed: R6.2, U5.12 (ICHG)
unnamed: R7.2, U5.14 (NTC)
unnamed: L1.2, U5.22 (SW)

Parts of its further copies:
C11: 10nF; C_0603_1608Metric; Mouser Part Number 810-C1608X5R1H103KAA
C12: 0.1uF; C_0603_1608Metric; Mouser Part Number 603-CC603KRX7R5BB105
C13, C14, C19, C20: 1uF; C_0603_1608Metric; Mouser Part Number 603-CC603KRX7R5BB105
C15: 2.2uF; C_0603_1608Metric; Mouser Part Number 810-C1608X5R1E225M
C16, C17, C18: 10uF; C_0603_1608Metric; Mouser Part Number 810-C1608X5R0J106K
D23: LED_Small; LED_0603_1608Metric; Manufacturer_Part_Number IN-PIS63BTPR; Mouser Part Number 743-IN-PIS63BTPR
D24: LED_Small; LED_0603_1608Metric; Manufacturer_Part_Number IN-PIS63BTPG; Mouser Part Number 743-IN-PIS63BTPG
IC2: MCP1700T-3302E_MAY; SON65P200X200X90-7N; Manufacturer_Part_Number MCP1700T-3302E/MAY; Mouser Part Number 579-MCP1700T3302EMAY
J2: USB_C_Receptacle_USB2.0_16P; USB_C_Receptacle_HRO_TYPE-C-31-M-12
L2: 2.2uH; L_0805_2012Metric; Manufacturer_Part_Number MLZ2012A2R2WT000; Mouser Part Number 810-MLZ2012A2R2WT000
R8, R9, R10, R12: 5.1k; R_0603_1608Metric; Manufacturer_Part_Number 603-RC0603FR-075K1L; Mouser Part Number 603-RC0603FR-075K1L
R11, R22, R24: 1.5k; R_0603_1608Metric; Manufacturer_Part_Number RC0603FR-071K5L; Mouser Part Number 603-RC0603FR-071K5L
SW4: SW_SPDT; SW_SPDT_PCM12; Manufacturer_Part_Number PCM12SMTBR; Mouser Part Number 611-PCM12SMTBR
TP11, TP14, TP15, TP16: TestPoint_Probe; TestPoint_Pad_D1.0mm
TP12: TestPoint; TestPoint_Pad_1.5x1.5mm
TP13: TestPoint; TestPoint_Pad_D1.5mm
U6: MAX17048; TDFN-8-1EP_2x2mm_P0.5mm_EP0.8x1.2mm; LCSC Part C2682616
U7: ESDR0502NMUTAG; UDFN-6_1.2x1.0mm_P0.4mm; Manufacturer Part ESDR0502NMUTBG; LCSC C327480
U8: nPM1100-QDXX; QFN-24-1EP_4x4mm_P0.5mm_EP2.6x2.6mm_ThermalVias; Manufacturer_Part_Number NPM1100-QDAA-R; Mouser Part Number 949-NPM1100-QDAA-R

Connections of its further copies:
/Side-Right/3.3V: C20.2, IC2.6 (VOUT), TP16.1; also elsewhere on the board
/Side-Right/3VOUT: C16.2, L2.1, TP14.1, U8.1 (VOUTB); also elsewhere on the board
/Side-Right/BAT_SCL: U6.7 (SCL); also elsewhere on the board
/Side-Right/BAT_SDA: U6.8 (SDA); also elsewhere on the board
/Side-Right/Power/CC1: J2.A5 (CC1), R8.1
/Side-Right/Power/CC2: J2.B5 (CC2), R9.1
/Side-Right/Power/FUEL_ALRT: U6.5 (~ALRT)
/Side-Right/Power/LChg: D24.1 (K), U8.8 (CHG)
/Side-Right/Power/LError: D23.1 (K), U8.10 (ERR)
/Side-Right/Power/VBAT: C12.2, C14.1, SW4.3 (C), U6.2 (CELL), U6.3 (VDD), U8.15 (VBAT)
/Side-Right/Power/VSYS: C18.2, C19.2, IC2.1 (VIN), R22.2, R24.2, TP15.1, U8.2 (VOUTBSET1), U8.3 (VOUTBSET0), U8.5 (ISET), U8.16 (VSYS)
/Side-Right/USB_D+: J2.A6 (D+), J2.B6 (D+), U7.5 (D+), U8.20 (D+); also elsewhere on the board
/Side-Right/USB_D-: J2.A7 (D-), J2.B7 (D-), U7.4 (D-), U8.19 (D-); also elsewhere on the board
/Side-Right/VBUS: C13.1, C15.1, J2.A4 (VBUS), J2.A9 (VBUS), J2.B4 (VBUS), J2.B9 (VBUS), TP11.1, U7.6 (VBUS), U8.17 (VBUS); also elsewhere on the board
GND: C11.2, C12.1, C13.2, C14.2, C15.2, C16.1, C17.1, C18.1, C19.1, C20.1, IC2.3 (GND), IC2.7 (EP), J2.A1 (GND), J2.A12 (GND), J2.B1 (GND), J2.B12 (GND), R8.2, R9.2, R10.1, R11.1, TP12.1, U6.1 (CTG), U6.4 (GND), U6.6 (QSTRT), U6.9 (EP), U7.1 (GND), U8.4 (AVSS), U8.6 (SHPACT), U8.7 (MODE), U8.9 (VTERMSET), U8.11 (SHPHLD), U8.23 (PVSS), U8.25 (AVSS); also elsewhere on the board
unnamed: D23.2 (A), R22.1
unnamed: D24.2 (A), R24.1
unnamed: C11.1, J2.S1 (SHIELD)
unnamed: R10.2, R12.1
unnamed: SW4.2 (B), TP13.1
unnamed: C17.2, U8.21 (DEC)
unnamed: R11.2, U8.12 (ICHG)
unnamed: R12.2, U8.14 (NTC)
unnamed: L2.2, U8.22 (SW)

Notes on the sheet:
BMIC + Power
USB Connector + ESD
Battery Fuel Gauge
note: use internal pullups for these

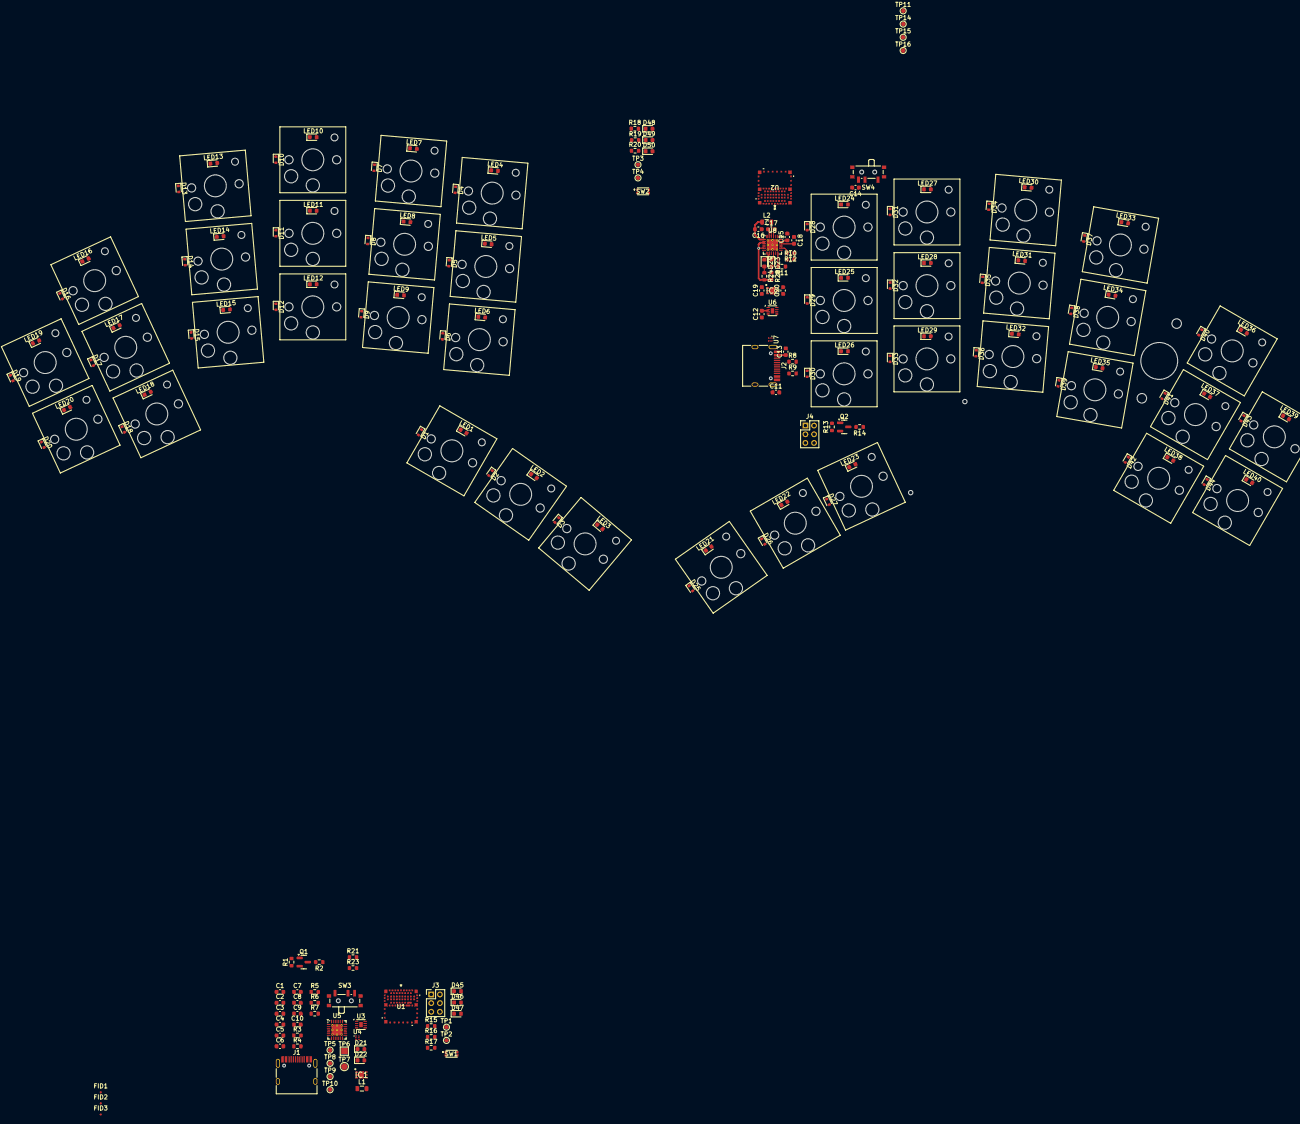
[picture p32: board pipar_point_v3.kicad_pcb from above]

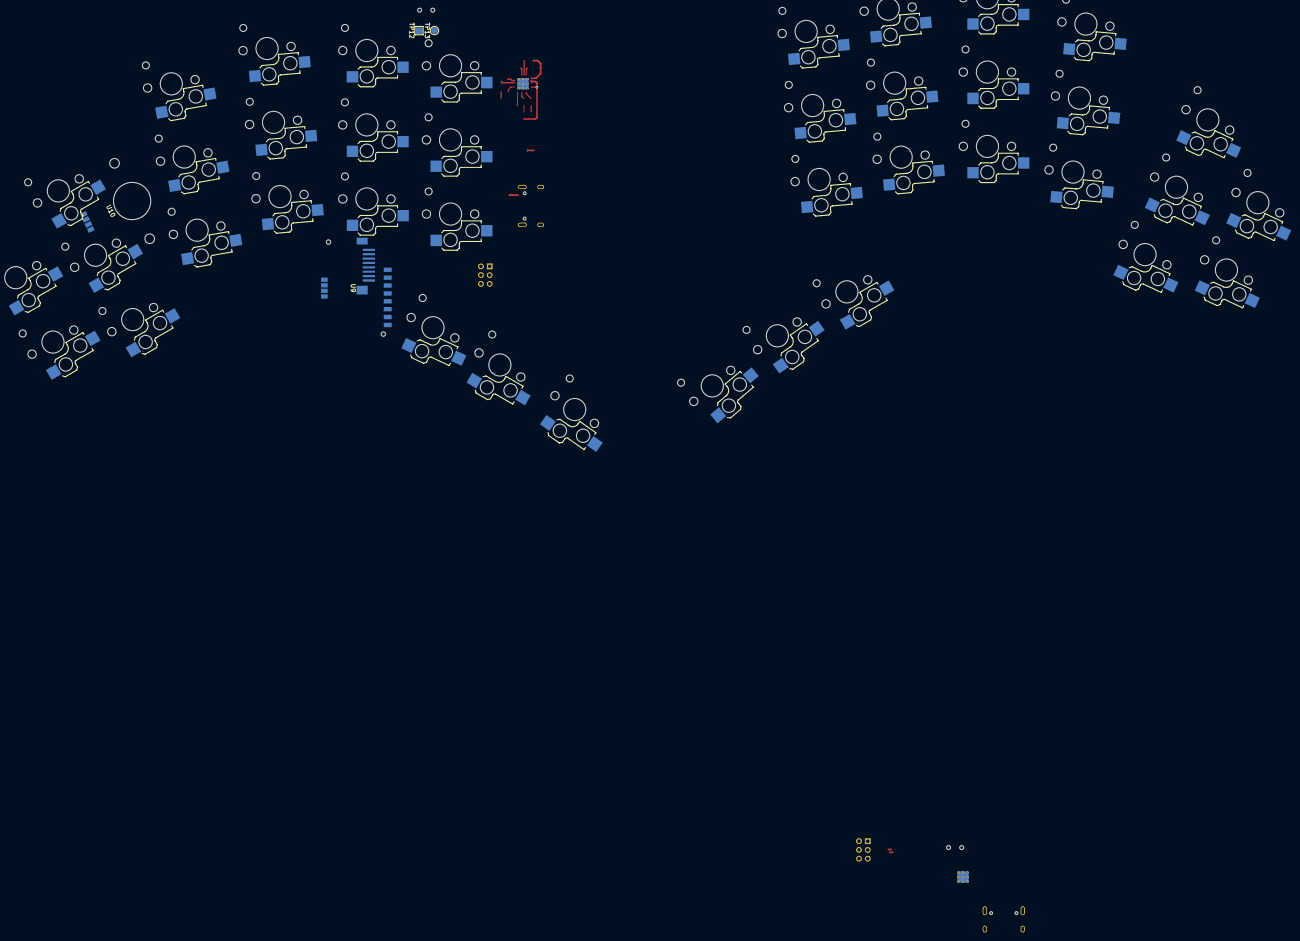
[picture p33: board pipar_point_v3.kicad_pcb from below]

Board: 4 copper layers, 259 parts (4 on the bottom side), 137 nets.

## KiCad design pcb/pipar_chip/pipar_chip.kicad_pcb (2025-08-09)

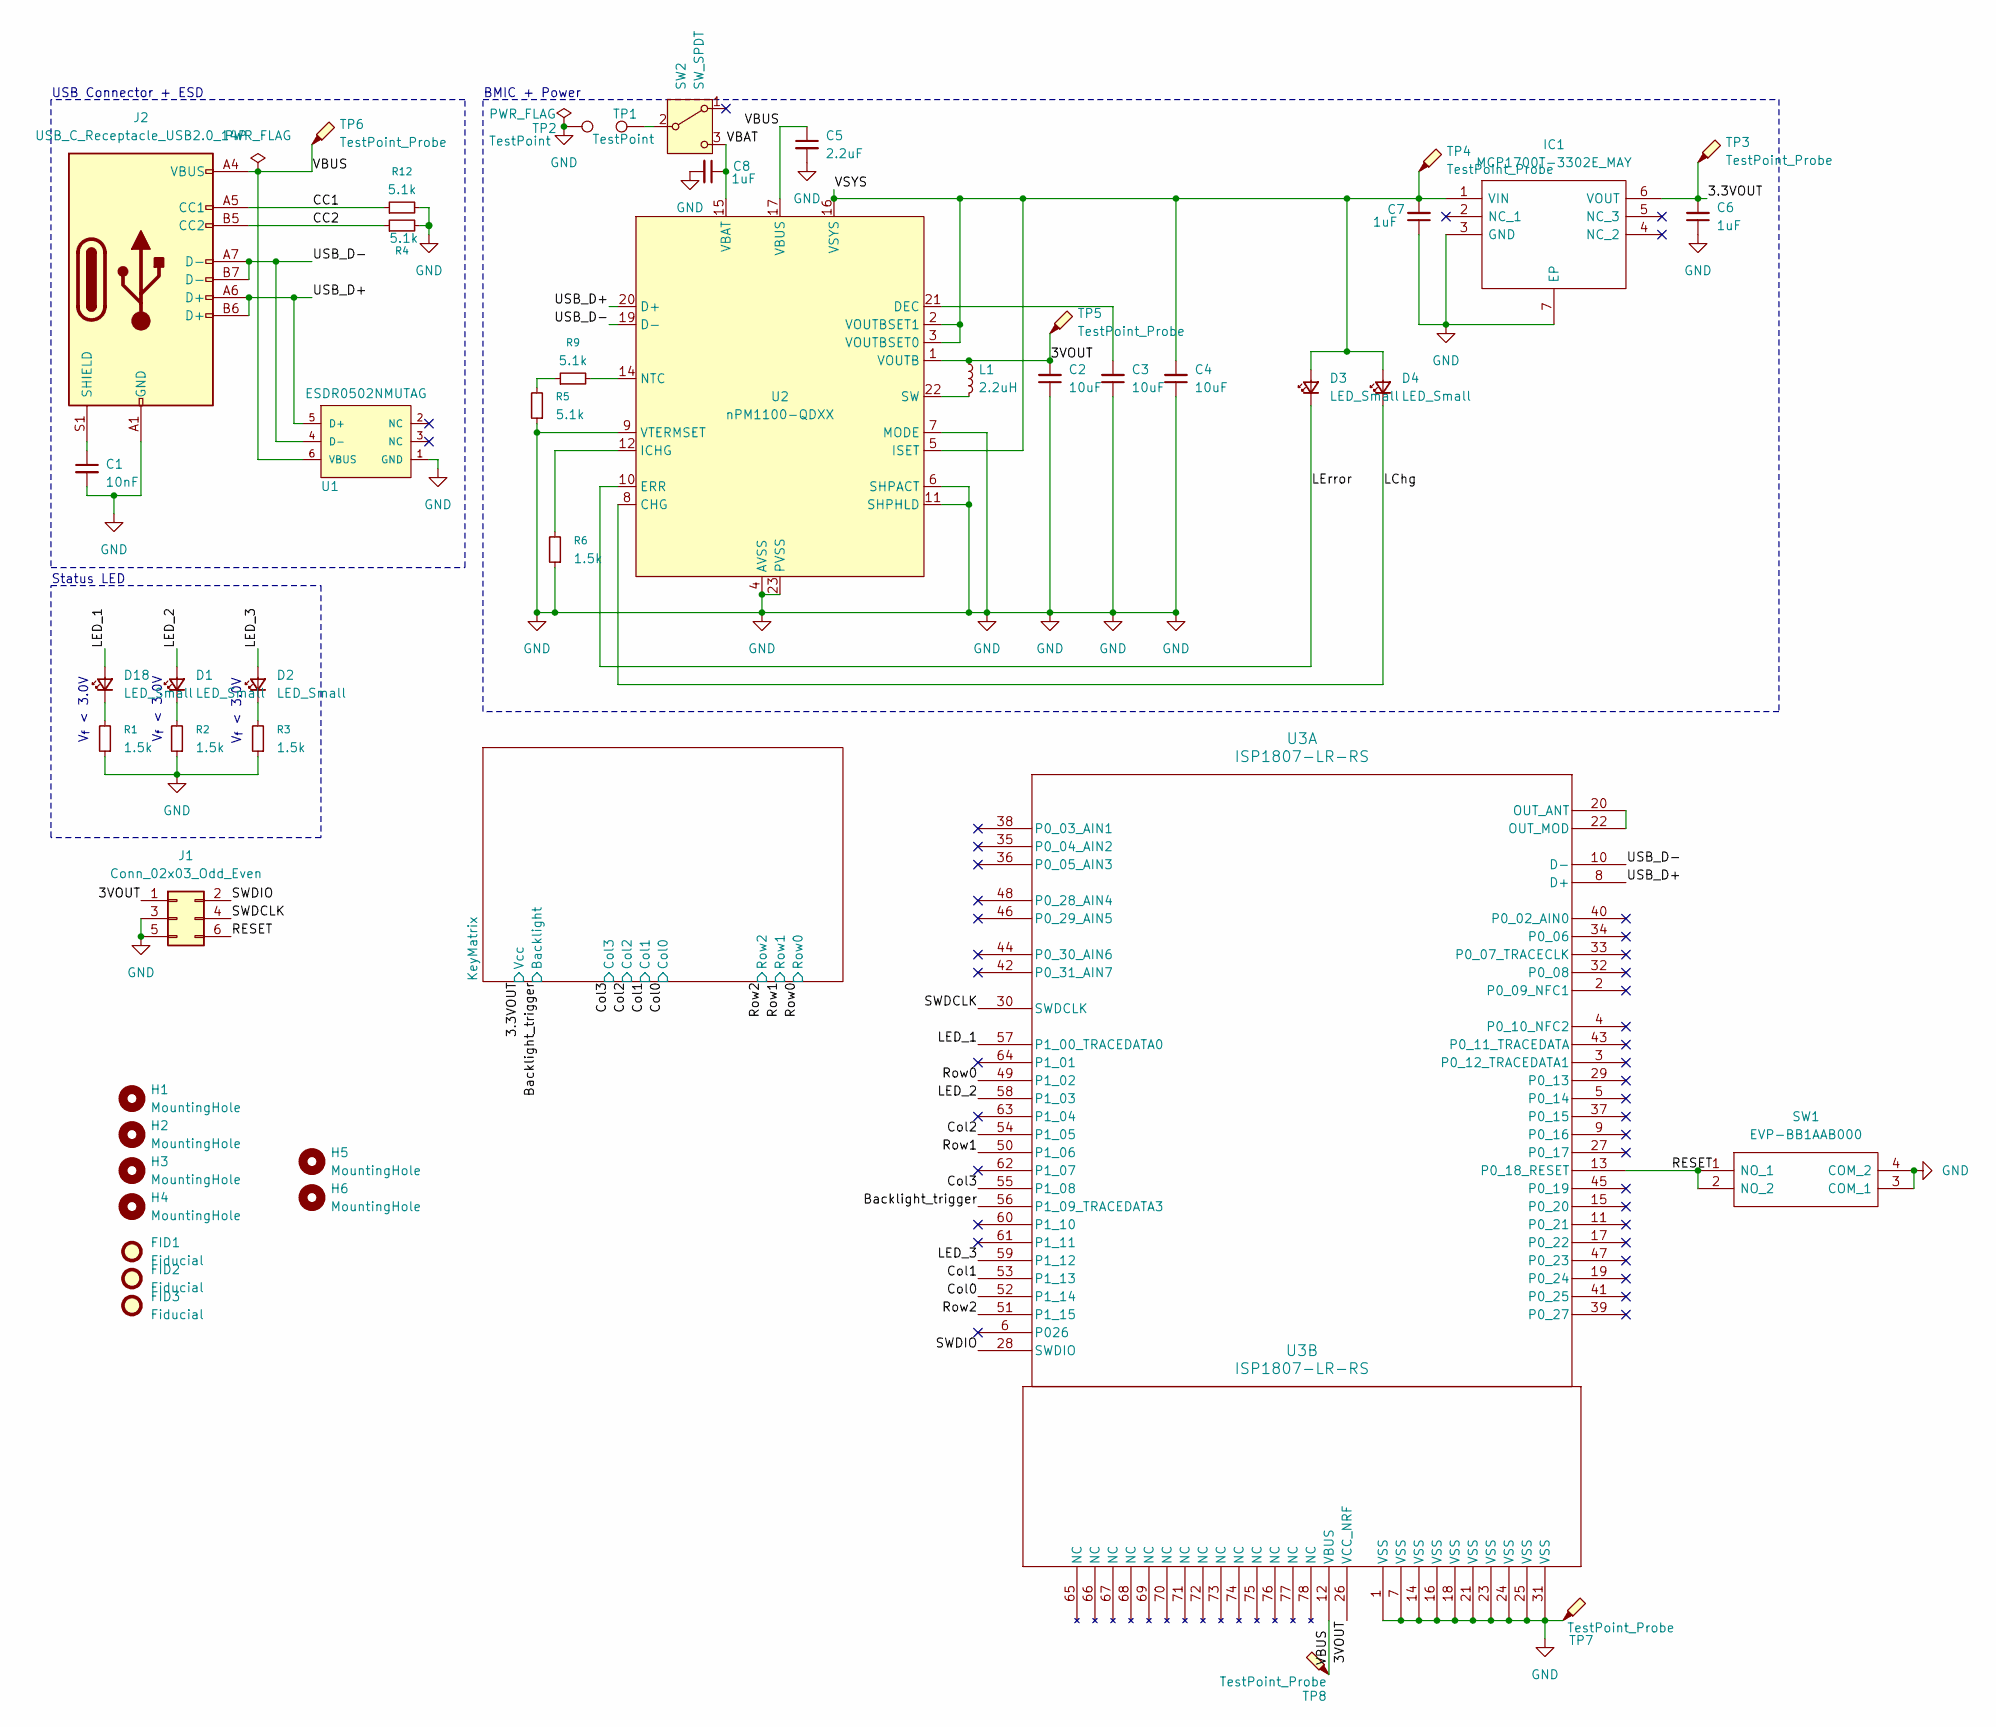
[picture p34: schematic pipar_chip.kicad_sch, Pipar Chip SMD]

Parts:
C1: 10nF; C_0603_1608Metric; Mouser Part Number 810-C1608X5R1H103KAA
C2, C3, C4: 10uF; C_0603_1608Metric; Mouser Part Number 810-C1608X5R0J106K
C5: 2.2uF; C_0603_1608Metric; Mouser Part Number 810-C1608X5R1E225M
C6, C7, C8: 1uF; C_0603_1608Metric; Mouser Part Number 603-CC603KRX7R5BB105
D1, D4: LED_Small; LED_0603_1608Metric; Manufacturer_Part_Number IN-PIS63BTPG; Mouser Part Number 743-IN-PIS63BTPG
D2: LED_Small; LED_0603_1608Metric; Manufacturer_Part_Number IN-PIS63BTPB; Mouser Part Number 743-IN-PIS63BTPB
D3, D18: LED_Small; LED_0603_1608Metric; Manufacturer_Part_Number IN-PIS63BTPR; Mouser Part Number 743-IN-PIS63BTPR
FID1, FID2, FID3: Fiducial; Fiducial_0.5mm_Mask1mm
H1, H2, H3, H4: MountingHole; SMTSO_M2_C4_2+C2.7_1.5
H5: MountingHole; chip
H6: MountingHole; Salt-smallest
IC1: MCP1700T-3302E_MAY; SON65P200X200X90-7N; Manufacturer_Part_Number MCP1700T-3302E/MAY; Mouser Part Number 579-MCP1700T3302EMAY
J1: Conn_02x03_Odd_Even; PinHeader_2x03_P1.00mm_Vertical
J2: USB_C_Receptacle_USB2.0_14P; USB_C_Receptacle_HRO_TYPE-C-31-M-12; Manufacturer_Part_Number UJ20-C-H-G-SMT-P16-TR; Mouser Part Number 179-UJ20CHGSMTP16TR
L1: 2.2uH; L_0805_2012Metric; Manufacturer_Part_Number MLZ2012A2R2WT000; Mouser Part Number 810-MLZ2012A2R2WT000
R1, R2, R3, R6: 1.5k; R_0603_1608Metric; Manufacturer_Part_Number RC0603FR-071K5L; Mouser Part Number 603-RC0603FR-071K5L
R4, R5, R9, R12: 5.1k; R_0603_1608Metric; Manufacturer_Part_Number 603-RC0603FR-075K1L; Mouser Part Number 603-RC0603FR-075K1L
SW1: EVP-BB1AAB000; EVPBB2A9B000; Mouser Part Number 667-EVP-BB1AAB000
SW2: SW_SPDT; SW_SPDT_PCM12; Manufacturer_Part_Number PCM12SMTBR; Mouser Part Number 611-PCM12SMTBR
TP1: TestPoint; TestPoint_Pad_D1.5mm
TP2: TestPoint; TestPoint_Pad_1.5x1.5mm
TP3, TP4, TP5, TP6, TP7, TP8: TestPoint_Probe; TestPoint_Pad_D1.0mm
U1: ESDR0502NMUTAG; UDFN-6_1.2x1.0mm_P0.4mm; Manufacturer Part ESDR0502NMUTBG; LCSC C327480
U2: nPM1100-QDXX; QFN-24-1EP_4x4mm_P0.5mm_EP2.6x2.6mm_ThermalVias; Manufacturer_Part_Number NPM1100-QDAA-R; Mouser Part Number 949-NPM1100-QDAA-R
U3: ISP1807-LR-RS; Manufacturer_Part_Number ISP1807-LR-RS; Mouser Part Number 359-ISP1807-LR-RS

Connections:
/3.3VOUT: C6.2, IC1.6 (VOUT), TP3.1; also elsewhere on the board
/3VOUT: C2.2, J1.1, L1.1, TP5.1, U2.1 (VOUTB), U3.26 (VCC_NRF)
/Backlight_trigger: U3.56 (P1_09_TRACEDATA3); also elsewhere on the board
/CC1: J2.A5 (CC1), R12.1
/CC2: J2.B5 (CC2), R4.1
/Col0: U3.52 (P1_14); also elsewhere on the board
/Col1: U3.53 (P1_13); also elsewhere on the board
/Col2: U3.54 (P1_05); also elsewhere on the board
/Col3: U3.55 (P1_08); also elsewhere on the board
/LChg: D4.1 (K), U2.8 (CHG)
/LED_1: D18.2 (A), U3.57 (P1_00_TRACEDATA0)
/LED_2: D1.2 (A), U3.58 (P1_03)
/LED_3: D2.2 (A), U3.59 (P1_12)
/LError: D3.1 (K), U2.10 (ERR)
/RESET: J1.6, SW1.1 (NO_1), SW1.2 (NO_2), U3.13 (P0_18_RESET)
/Row0: U3.49 (P1_02); also elsewhere on the board
/Row1: U3.50 (P1_06); also elsewhere on the board
/Row2: U3.51 (P1_15); also elsewhere on the board
/SWDCLK: J1.4, U3.30 (SWDCLK)
/SWDIO: J1.2, U3.28 (SWDIO)
/USB_D+: J2.A6 (D+), J2.B6 (D+), U1.5 (D+), U2.20 (D+), U3.8 (D+)
/USB_D-: J2.A7 (D-), J2.B7 (D-), U1.4 (D-), U2.19 (D-), U3.10 (D-)
/VBAT: C8.1, SW2.3 (C), U2.15 (VBAT)
/VBUS: C5.1, J2.A4 (VBUS), J2.A9 (VBUS), J2.B4 (VBUS), J2.B9 (VBUS), TP6.1, TP8.1, U1.6 (VBUS), U2.17 (VBUS), U3.12 (VBUS)
/VSYS: C4.2, C7.2, D3.2 (A), D4.2 (A), IC1.1 (VIN), TP4.1, U2.2 (VOUTBSET1), U2.3 (VOUTBSET0), U2.5 (ISET), U2.16 (VSYS)
GND: C1.2, C2.1, C3.1, C4.1, C5.2, C6.1, C7.1, C8.2, IC1.3 (GND), IC1.7 (EP), J1.3, J1.5, J2.A1 (GND), J2.A12 (GND), J2.B1 (GND), J2.B12 (GND), R1.1, R2.1, R3.1, R4.2, R5.1, R6.1, R12.2, SW1.3 (COM_1), SW1.4 (COM_2), TP2.1, TP7.1, U1.1 (GND), U2.4 (AVSS), U2.6 (SHPACT), U2.7 (MODE), U2.9 (VTERMSET), U2.11 (SHPHLD), U2.23 (PVSS), U2.25 (AVSS), U3.1 (VSS), U3.7 (VSS), U3.14 (VSS), U3.16 (VSS), U3.18 (VSS), U3.21 (VSS), U3.23 (VSS), U3.24 (VSS), U3.25 (VSS), U3.31 (VSS); also elsewhere on the board
unnamed: D1.1 (K), R2.2
unnamed: D2.1 (K), R3.2
unnamed: D18.1 (K), R1.2
unnamed: C1.1, J2.S1 (SHIELD)
unnamed: R5.2, R9.1
unnamed: SW2.2 (B), TP1.1
unnamed: C3.2, U2.21 (DEC)
unnamed: R6.2, U2.12 (ICHG)
unnamed: R9.2, U2.14 (NTC)
unnamed: L1.2, U2.22 (SW)
unnamed: U3.20 (OUT_ANT), U3.22 (OUT_MOD)

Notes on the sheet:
USB Connector + ESD
V_{f} < 3.0V
Status LED
BMIC + Power

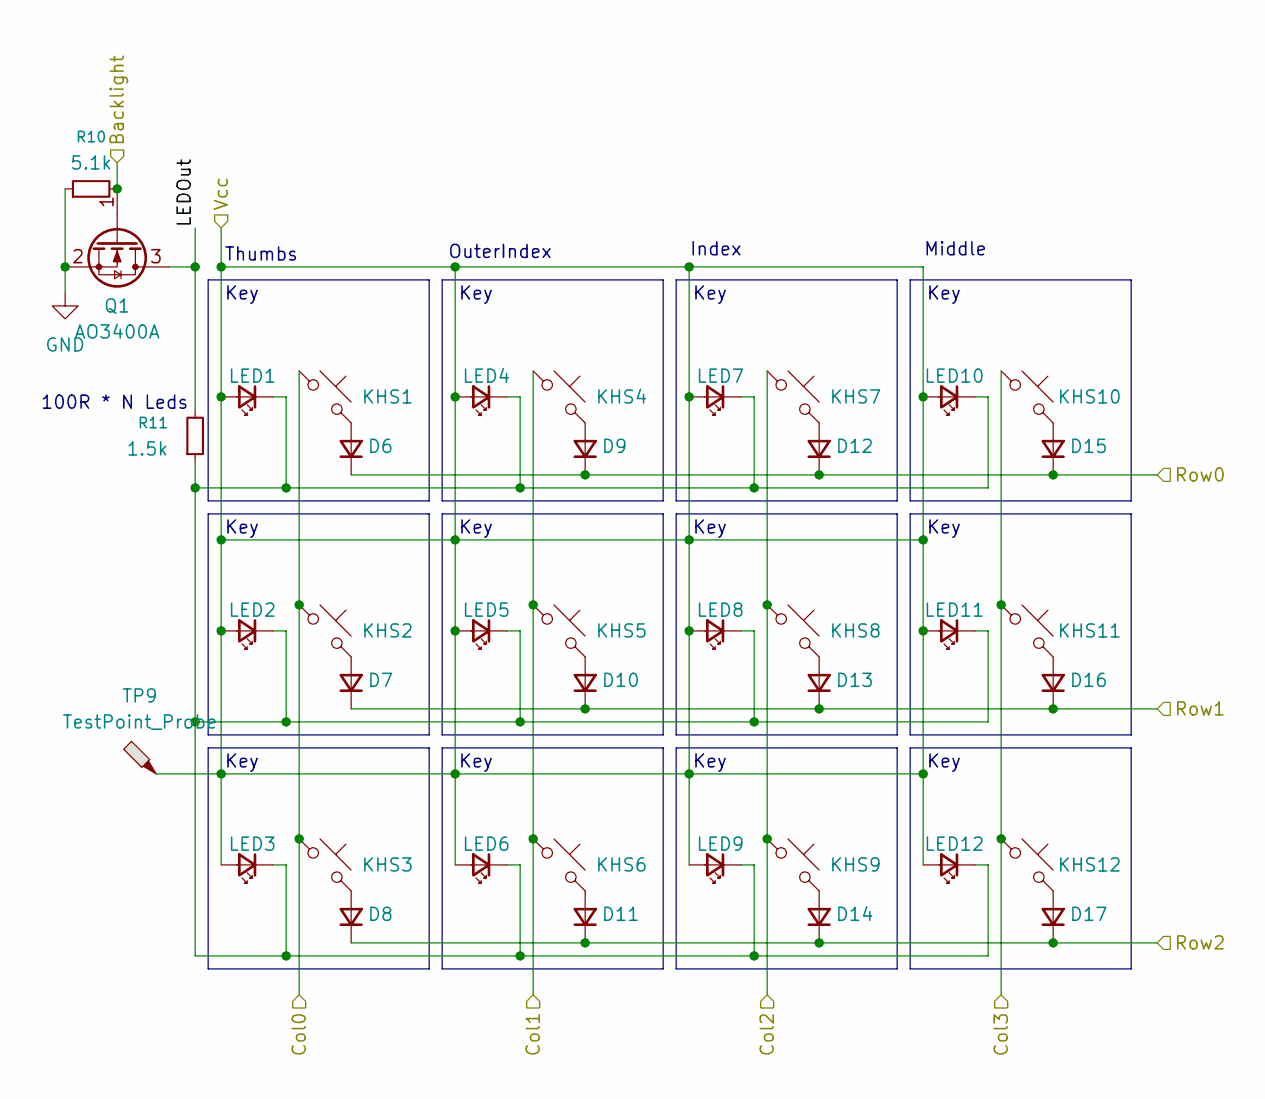
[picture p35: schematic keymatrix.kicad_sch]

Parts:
D6, D7, D8, D9, D10, D11, D12, D13, D14, D15, D16, D17: D_Small; D_SOD-523; Manufacturer_Part_Number 1N4148WT-7; Mouser Part Number 621-1N4148WT
KHS1, KHS2, KHS3, KHS4, KHS5, KHS6, KHS7, KHS8, KHS9, KHS10, KHS11, KHS12: KHS; CPG1316S01D02_front_mikefives
LED1, LED2, LED3, LED4, LED5, LED6, LED7, LED8, LED9, LED10, LED11, LED12: LED_Small; LED_0603_1608Metric; Manufacturer_Part_Number IN-S63BT5UW; Mouser Part Number 743-IN-S63BT5UW
Q1: AO3400A; SOT-23; Manufacturer_Part_Number IRLML6344TRPBF; Mouser Part Number 942-IRLML6344TRPBF
R10: 5.1k; R_0603_1608Metric; Manufacturer_Part_Number 603-RC0603FR-075K1L; Mouser Part Number 603-RC0603FR-075K1L
R11: 1.5k; R_0603_1608Metric; Manufacturer_Part_Number RC0603FR-071K5L; Mouser Part Number 603-RC0603FR-071K5L
TP9: TestPoint_Probe; TestPoint_Pad_D1.0mm

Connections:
/3.3VOUT: LED1.2 (A), LED2.2 (A), LED3.2 (A), LED4.2 (A), LED5.2 (A), LED6.2 (A), LED7.2 (A), LED8.2 (A), LED9.2 (A), LED10.2 (A), LED11.2 (A), LED12.2 (A), TP9.1; also elsewhere on the board
/Backlight_trigger: Q1.1 (G), R10.2; also elsewhere on the board
/Col0: KHS1.1, KHS2.1, KHS3.1; also elsewhere on the board
/Col1: KHS4.1, KHS5.1, KHS6.1; also elsewhere on the board
/Col2: KHS7.1, KHS8.1, KHS9.1; also elsewhere on the board
/Col3: KHS10.1, KHS11.1, KHS12.1; also elsewhere on the board
/KeyMatrix/LEDOut: Q1.3 (D), R11.2
/Row0: D6.1 (K), D9.1 (K), D12.1 (K), D15.1 (K); also elsewhere on the board
/Row1: D7.1 (K), D10.1 (K), D13.1 (K), D16.1 (K); also elsewhere on the board
/Row2: D8.1 (K), D11.1 (K), D14.1 (K), D17.1 (K); also elsewhere on the board
GND: Q1.2 (S), R10.1; also elsewhere on the board
unnamed: D6.2 (A), KHS1.2
unnamed: D7.2 (A), KHS2.2
unnamed: D8.2 (A), KHS3.2
unnamed: D9.2 (A), KHS4.2
unnamed: D10.2 (A), KHS5.2
unnamed: D11.2 (A), KHS6.2
unnamed: D12.2 (A), KHS7.2
unnamed: D13.2 (A), KHS8.2
unnamed: D14.2 (A), KHS9.2
unnamed: D15.2 (A), KHS10.2
unnamed: D16.2 (A), KHS11.2
unnamed: D17.2 (A), KHS12.2
unnamed: LED1.1 (K), LED2.1 (K), LED3.1 (K), LED4.1 (K), LED5.1 (K), LED6.1 (K), LED7.1 (K), LED8.1 (K), LED9.1 (K), LED10.1 (K), LED11.1 (K), LED12.1 (K), R11.1

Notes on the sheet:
Index
Key
Thumbs
Middle
100R * N Leds
OuterIndex

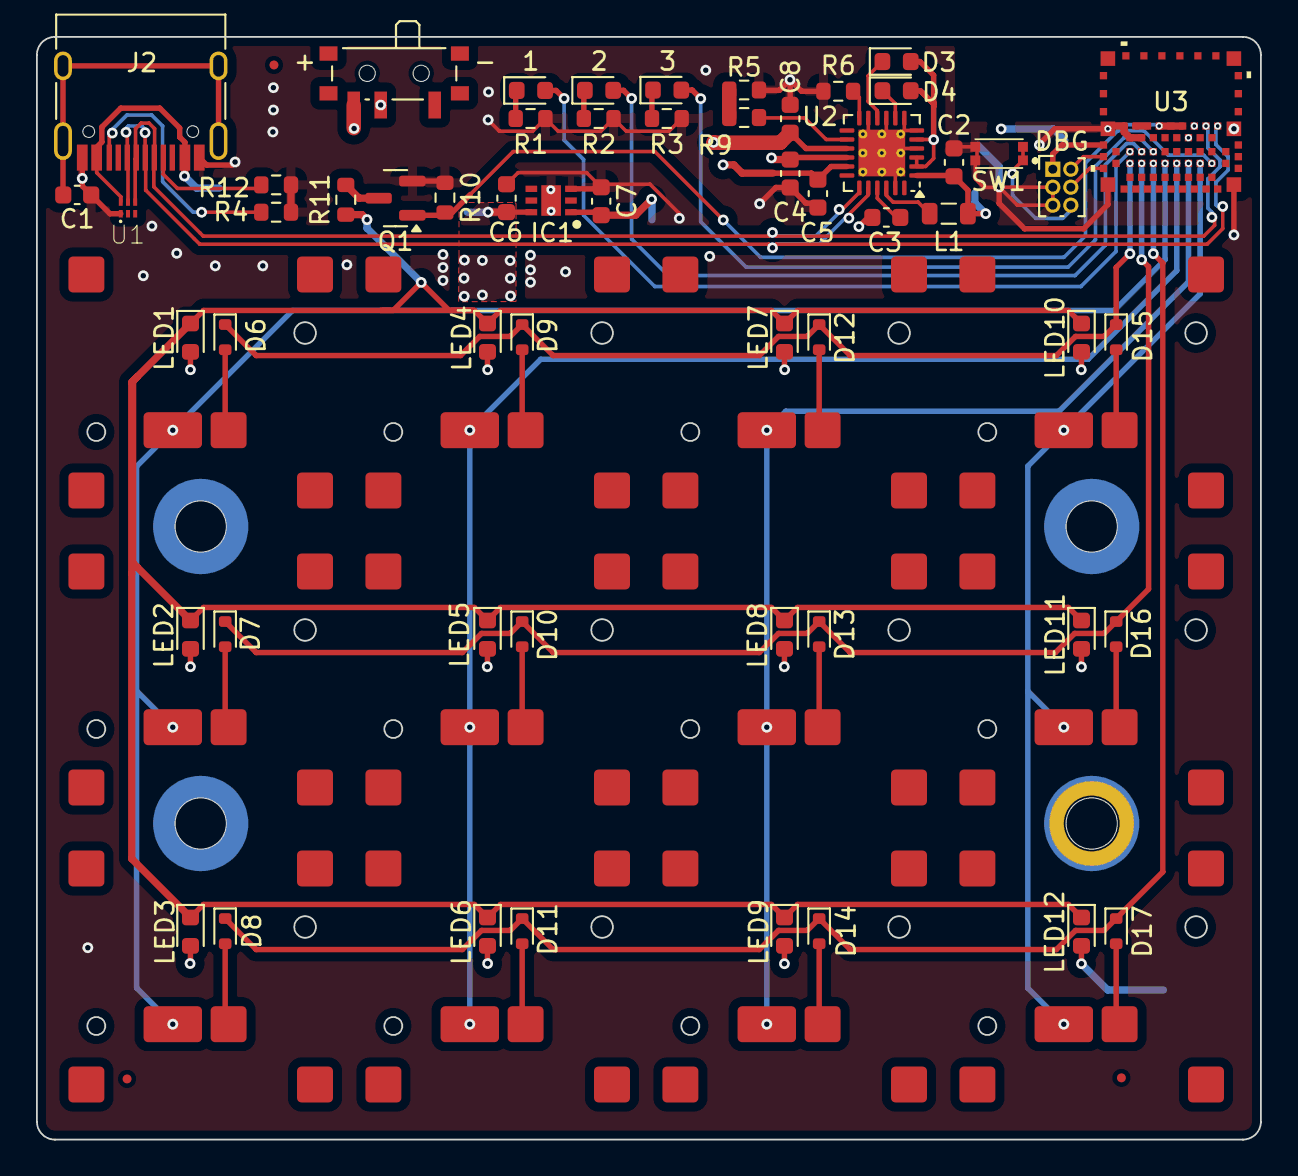
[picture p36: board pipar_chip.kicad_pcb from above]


Board: 4 copper layers, 68.0 x 61.3 mm, 87 parts (15 on the bottom side), 51 nets.

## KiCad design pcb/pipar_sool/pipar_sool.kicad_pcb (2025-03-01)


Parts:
H1, H2, H3, H4, H5, H6, H7, H8, H9, H10, H11, H12, H13, H14, H15, H16, H17, H18: MountingHole; Kailh_socket_PG1350_reversible_Holes
Q1: AO3416 N-channel MOSFET; SOT-23; MPN AO3416; LCSC Part Number C479060
R39: 4.7k; R_0402_1005Metric_Pad0.72x0.64mm_HandSolder; Part Number PF1206FRF070R01L; JLCPCB ID C127703
SW1: PowerSwitch; SW_SPDT_PCM12
SW3: BUTTON-4P; SW4-SMD-2.8-2.6X1.6X0.53MM
TP1: BAT-; TestPoint_THTPad_2.0x2.0mm_Drill1.0mm
TP2: BAT+; TestPoint_THTPad_D2.0mm_Drill1.0mm
U1, U2, U3, U4, U5: Solder Nut
U6, U9: Salt-smallest
U7: Seeeduino Xiao nRF52840; XIAO-nRF52840-Sense-14P-2.54-21X17.8MM
U10, U11, U12, U13, U14, U15: Fiducial_0.5mm_Mask1.5mm

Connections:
3V3: U7.10 (3V3); also elsewhere on the board
5V: U7.8 (5V); also elsewhere on the board
+4V: SW1.1 (B), U7.16 (BAT+); also elsewhere on the board
BAT+: SW1.2 (C), TP2.1; also elsewhere on the board
CLK: U7.20 (CLK); also elsewhere on the board
COL0: U7.7 (P1.11); also elsewhere on the board
COL1: U7.6 (P0.05); also elsewhere on the board
COL2: U7.5 (P0.04); also elsewhere on the board
COL3: U7.4 (P0.29); also elsewhere on the board
COL4: U7.3 (P0.28); also elsewhere on the board
COL5: U7.2 (P0.03); also elsewhere on the board
DIO: U7.19 (DIO); also elsewhere on the board
GND: Q1.2 (S), R39.1, SW3.2 (B0), SW3.4 (B1), TP1.1, U7.9 (GND), U7.15 (BAT-), U7.22 (GND); also elsewhere on the board
LEDOut: Q1.3 (D); also elsewhere on the board
LEDTrig: Q1.1 (G), R39.2, U7.11 (P1.15); also elsewhere on the board
PIN1: U7.1 (P0.02); also elsewhere on the board
ROW0: U7.14 (P1.12); also elsewhere on the board
ROW1: U7.13 (P1.13); also elsewhere on the board
ROW2: U7.12 (P1.14); also elsewhere on the board
RST: SW3.1 (A0), SW3.3 (A1), U7.21 (RST); also elsewhere on the board

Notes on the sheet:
LED Backlight
MCU Switches
MCU
Extras

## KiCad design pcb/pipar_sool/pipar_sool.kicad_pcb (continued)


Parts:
Q2: AO3416 N-channel MOSFET; SOT-23; MPN AO3416; LCSC Part Number C479060
R40: 4.7k; R_0402_1005Metric_Pad0.72x0.64mm_HandSolder; Part Number PF1206FRF070R01L; JLCPCB ID C127703
SW2: PowerSwitch; SW_SPDT_PCM12
SW4: BUTTON-4P; SW4-SMD-2.8-2.6X1.6X0.53MM
U8: Seeeduino Xiao nRF52840; XIAO-nRF52840-Sense-14P-2.54-21X17.8MM

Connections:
3V3: U8.10 (3V3); also elsewhere on the board
5V: U8.8 (5V); also elsewhere on the board
+4V: SW2.1 (B), U8.16 (BAT+); also elsewhere on the board
BAT+: SW2.2 (C); also elsewhere on the board
CLK: U8.20 (CLK); also elsewhere on the board
COL0: U8.7 (P1.11); also elsewhere on the board
COL1: U8.6 (P0.05); also elsewhere on the board
COL2: U8.5 (P0.04); also elsewhere on the board
COL3: U8.4 (P0.29); also elsewhere on the board
COL4: U8.3 (P0.28); also elsewhere on the board
COL5: U8.2 (P0.03); also elsewhere on the board
DIO: U8.19 (DIO); also elsewhere on the board
GND: Q2.2 (S), R40.1, SW4.2 (B0), SW4.4 (B1), U8.9 (GND), U8.15 (BAT-), U8.22 (GND); also elsewhere on the board
LEDOut: Q2.3 (D); also elsewhere on the board
LEDTrig: Q2.1 (G), R40.2, U8.11 (P1.15); also elsewhere on the board
PIN1: U8.1 (P0.02); also elsewhere on the board
ROW0: U8.14 (P1.12); also elsewhere on the board
ROW1: U8.13 (P1.13); also elsewhere on the board
ROW2: U8.12 (P1.14); also elsewhere on the board
RST: SW4.1 (A0), SW4.3 (A1), U8.21 (RST); also elsewhere on the board


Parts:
CH1, CH2, CH3, CH4, CH5, CH6, CH7, CH8, CH9, CH10, CH11, CH12, CH13, CH14, CH15, CH16, CH17, CH18: KSwitch; Kailh_HS_Socket
D1, D2, D3, D4, D5, D6, D7, D8, D9, D10, D11, D12, D13, D14, D15, D16, D17, D18: D; D_0402_1005Metric
LED1, LED2, LED3, LED4, LED5, LED6, LED7, LED8, LED9, LED10, LED11, LED12, LED13, LED14, LED15, LED16, LED17, LED18: LED_0402_1005Metric_Pad0.77x0.64mm_HandSolder
R1, R2, R3, R4, R5, R6, R7, R8, R9, R10, R11, R12, R13, R14, R15, R16, R17, R18: 100; R_0402_1005Metric_Pad0.72x0.64mm_HandSolder

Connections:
3V3: LED1.2 (A), LED2.2 (A), LED3.2 (A), LED4.2 (A), LED5.2 (A), LED6.2 (A), LED7.2 (A), LED8.2 (A), LED9.2 (A), LED10.2 (A), LED11.2 (A), LED12.2 (A), LED13.2 (A), LED14.2 (A), LED15.2 (A), LED16.2 (A), LED17.2 (A), LED18.2 (A); also elsewhere on the board
COL0: CH1.1, CH2.1, CH3.1; also elsewhere on the board
COL1: CH4.1, CH5.1, CH6.1; also elsewhere on the board
COL2: CH7.1, CH8.1, CH9.1; also elsewhere on the board
COL3: CH10.1, CH11.1, CH12.1; also elsewhere on the board
COL4: CH13.1, CH14.1, CH15.1; also elsewhere on the board
COL5: CH16.1, CH17.1, CH18.1; also elsewhere on the board
LEDOut: R1.2, R2.2, R3.2, R4.2, R5.2, R6.2, R7.2, R8.2, R9.2, R10.2, R11.2, R12.2, R13.2, R14.2, R15.2, R16.2, R17.2, R18.2; also elsewhere on the board
unnamed: CH1.2, D1.2 (A)
unnamed: CH2.2, D2.2 (A)
unnamed: CH3.2, D3.2 (A)
unnamed: CH4.2, D4.2 (A)
unnamed: CH5.2, D5.2 (A)
unnamed: CH6.2, D6.2 (A)
unnamed: CH7.2, D7.2 (A)
unnamed: CH8.2, D8.2 (A)
unnamed: CH9.2, D9.2 (A)
unnamed: CH10.2, D10.2 (A)
unnamed: CH11.2, D11.2 (A)
unnamed: CH12.2, D12.2 (A)
unnamed: CH13.2, D13.2 (A)
unnamed: CH14.2, D14.2 (A)
unnamed: CH15.2, D15.2 (A)
unnamed: CH16.2, D16.2 (A)
unnamed: CH17.2, D17.2 (A)
unnamed: CH18.2, D18.2 (A)
unnamed: LED1.1 (K), R1.1
unnamed: LED2.1 (K), R2.1
unnamed: LED3.1 (K), R3.1
unnamed: LED4.1 (K), R4.1
unnamed: LED5.1 (K), R5.1
unnamed: LED6.1 (K), R6.1
unnamed: LED7.1 (K), R7.1
unnamed: LED8.1 (K), R8.1
unnamed: LED9.1 (K), R9.1
unnamed: LED10.1 (K), R10.1
unnamed: LED11.1 (K), R11.1
unnamed: LED12.1 (K), R12.1
unnamed: LED13.1 (K), R13.1
unnamed: LED14.1 (K), R14.1
unnamed: LED15.1 (K), R15.1
unnamed: LED16.1 (K), R16.1
unnamed: LED17.1 (K), R17.1
unnamed: LED18.1 (K), R18.1
ROW0: D1.1 (K), D4.1 (K), D7.1 (K), D10.1 (K), D13.1 (K), D16.1 (K); also elsewhere on the board
ROW1: D2.1 (K), D5.1 (K), D8.1 (K), D11.1 (K), D14.1 (K), D17.1 (K); also elsewhere on the board
ROW2: D3.1 (K), D6.1 (K), D9.1 (K), D12.1 (K), D15.1 (K), D18.1 (K); also elsewhere on the board

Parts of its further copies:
CH19, CH20, CH21, CH22, CH23, CH24, CH25, CH26, CH27, CH28, CH29, CH30, CH31, CH32, CH33, CH34, CH35, CH36: KSwitch; Kailh_HS_Socket
D19, D20, D21, D22, D23, D24, D25, D26, D27, D28, D29, D30, D31, D32, D33, D34, D35, D36: D; D_0402_1005Metric
LED19, LED20, LED21, LED22, LED23, LED24, LED25, LED26, LED27, LED28, LED29, LED30, LED31, LED32, LED33, LED34, LED35, LED36: LED_0402_1005Metric_Pad0.77x0.64mm_HandSolder
R19, R20, R21, R22, R23, R24, R25, R26, R27, R28, R29, R30, R31, R32, R33, R34, R35, R36: 100; R_0402_1005Metric_Pad0.72x0.64mm_HandSolder

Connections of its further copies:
3V3: LED19.2 (A), LED20.2 (A), LED21.2 (A), LED22.2 (A), LED23.2 (A), LED24.2 (A), LED25.2 (A), LED26.2 (A), LED27.2 (A), LED28.2 (A), LED29.2 (A), LED30.2 (A), LED31.2 (A), LED32.2 (A), LED33.2 (A), LED34.2 (A), LED35.2 (A), LED36.2 (A); also elsewhere on the board
COL0: CH19.1, CH20.1, CH21.1; also elsewhere on the board
COL1: CH22.1, CH23.1, CH24.1; also elsewhere on the board
COL2: CH25.1, CH26.1, CH27.1; also elsewhere on the board
COL3: CH28.1, CH29.1, CH30.1; also elsewhere on the board
COL4: CH31.1, CH32.1, CH33.1; also elsewhere on the board
COL5: CH34.1, CH35.1, CH36.1; also elsewhere on the board
LEDOut: R19.2, R20.2, R21.2, R22.2, R23.2, R24.2, R25.2, R26.2, R27.2, R28.2, R29.2, R30.2, R31.2, R32.2, R33.2, R34.2, R35.2, R36.2; also elsewhere on the board
unnamed: CH19.2, D19.2 (A)
unnamed: CH20.2, D20.2 (A)
unnamed: CH21.2, D21.2 (A)
unnamed: CH22.2, D22.2 (A)
unnamed: CH23.2, D23.2 (A)
unnamed: CH24.2, D24.2 (A)
unnamed: CH25.2, D25.2 (A)
unnamed: CH26.2, D26.2 (A)
unnamed: CH27.2, D27.2 (A)
unnamed: CH28.2, D28.2 (A)
unnamed: CH29.2, D29.2 (A)
unnamed: CH30.2, D30.2 (A)
unnamed: CH31.2, D31.2 (A)
unnamed: CH32.2, D32.2 (A)
unnamed: CH33.2, D33.2 (A)
unnamed: CH34.2, D34.2 (A)
unnamed: CH35.2, D35.2 (A)
unnamed: CH36.2, D36.2 (A)
unnamed: LED19.1 (K), R19.1
unnamed: LED20.1 (K), R20.1
unnamed: LED21.1 (K), R21.1
unnamed: LED22.1 (K), R22.1
unnamed: LED23.1 (K), R23.1
unnamed: LED24.1 (K), R24.1
unnamed: LED25.1 (K), R25.1
unnamed: LED26.1 (K), R26.1
unnamed: LED27.1 (K), R27.1
unnamed: LED28.1 (K), R28.1
unnamed: LED29.1 (K), R29.1
unnamed: LED30.1 (K), R30.1
unnamed: LED31.1 (K), R31.1
unnamed: LED32.1 (K), R32.1
unnamed: LED33.1 (K), R33.1
unnamed: LED34.1 (K), R34.1
unnamed: LED35.1 (K), R35.1
unnamed: LED36.1 (K), R36.1
ROW0: D19.1 (K), D22.1 (K), D25.1 (K), D28.1 (K), D31.1 (K), D34.1 (K); also elsewhere on the board
ROW1: D20.1 (K), D23.1 (K), D26.1 (K), D29.1 (K), D32.1 (K), D35.1 (K); also elsewhere on the board
ROW2: D21.1 (K), D24.1 (K), D27.1 (K), D30.1 (K), D33.1 (K), D36.1 (K); also elsewhere on the board



Board: 2 copper layers, 142.4 x 110.5 mm, 187 parts (81 on the bottom side), 92 nets.

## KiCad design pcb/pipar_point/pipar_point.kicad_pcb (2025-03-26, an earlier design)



Board: 2 copper layers, 361 parts (189 on the bottom side), 209 nets.

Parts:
AE1, AE2: Antenna; 2.4GHz-meander-antenna-v2
C1, C4, C13, C19, C33, C34, C39, C44, C62, C64, C67, C68, C69, C70: 4.7uF; C_0402_1005Metric
C2, C20, C35, C45: 1uF; C_0402_1005Metric
C3, C36: 47nF; C_0402_1005Metric
C5, C32: 1nF; C_0402_1005Metric
C6, C31: 100pF; C_0402_1005Metric
C7, C16, C17, C18, C30, C40, C42, C43, C65, C66: 100nF; C_0402_1005Metric
C8, C9, C21, C22, C27, C28, C37, C38: 15pF; C_0402_1005Metric
C10, C25: 1.5pF; C_0402_1005Metric
C11, C12, C26, C29: 1pF; C_0402_1005Metric
C23, C41: 10nF; C_0402_1005Metric
C24, C46: 1000pF/NC; C_0402_1005Metric
C49, C63: 10uF; C_0603_1608Metric
C50, C58: C; C_0805_2012Metric
C51, C53, C54, C55, C56, C57, C59, C60, C61: C_Small; C_0402_1005Metric
C52: C_Small; C_0603_1608Metric
D3, D4: BLUE; LED_0402_1005Metric
D7, D8: B5819WT; D_SOD-523
D9, D10: CHG; LED_0402_1005Metric
D22, D23: CAPS; LED_0402_1005Metric
D90, D91, D92, D93, D94, D95, D96, D97, D98, D99, D100, D101, D102, D103, D104, D105, D106, D107, D108, D109, D110, D111, D112, D113, D114, D115, D116, D117, D118, D119, D120, D121, D122, D123, D124, D125, D126, D127, D128, D129: D_Small; D_0402_1005Metric
H90, H91, H92, H93, H94, H95, H96, H97, H98, H99, H100, H101, H102, H103, H104, H105, H106, H107, H108, H109, H110, H111, H112, H113, H114, H115, H116, H117, H118, H119, H120, H121, H122, H123, H124, H125, H126, H127, H128, H129: SwitchHoles; SwitchHoles_Kailh_Choc_V1V2
J53: Conn_02x04_Odd_Even; PinHeader_2x04_P2.54mm_Vertical_SMD
KHS90, KHS91, KHS92, KHS93, KHS94, KHS95, KHS96, KHS97, KHS98, KHS99, KHS100, KHS101, KHS102, KHS103, KHS104, KHS105, KHS106, KHS107, KHS108, KHS109, KHS110, KHS111, KHS112, KHS113, KHS114, KHS115, KHS116, KHS117, KHS118, KHS119, KHS120, KHS121, KHS122, KHS123, KHS124, KHS125, KHS126, KHS127, KHS128, KHS129: KHS; Kailh_HS_Socket
L1, L6: 15nH; L_0402_1005Metric
L2, L3, L7, L8: 10uH; L_0603_1608Metric
L4, L5: 3.9nH; L_0402_1005Metric
LED90, LED91, LED92, LED93, LED94, LED95, LED96, LED97, LED98, LED99, LED100, LED101, LED102, LED103, LED104, LED105, LED106, LED107, LED108, LED109, LED110, LED111, LED112, LED113, LED114, LED115, LED116, LED117, LED118, LED119, LED120, LED121, LED122, LED123, LED124, LED125, LED126, LED127, LED128, LED129: LED_Small; LED_0402_1005Metric
LR90, LR91, LR92, LR93, LR94, LR95, LR96, LR97, LR98, LR99, LR100, LR101, LR102, LR103, LR104, LR105, LR106, LR107, LR108, LR109, LR110, LR111, LR112, LR113, LR114, LR115, LR116, LR117, LR118, LR119, LR120, LR121, LR122, LR123, LR124, LR125, LR126, LR127, LR128, LR129: R_Small; R_0402_1005Metric
NT1, NT2: NetTie_2; net-tie-2-tiny
P1, P2: USB-C; USB_C_Receptacle_HRO_TYPE-C-31-M-12
Q1, Q2: AO3416 N-channel MOSFET; SOT-23
R1, R12: 0R; R_0402_1005Metric
R5, R16, R31, R32: 1.5k; R_0402_1005Metric
R6, R7, R20, R21: 5.1k; R_0402_1005Metric
R8, R9, R13, R14: 2M; R_0603_1608Metric
R10, R15: 10M; R_0402_1005Metric
R11, R17: 1M; R_0402_1005Metric
R23, R24: 2M; R_0402_1005Metric
R25, R26: 10k; R_0402_1005Metric
R27, R28: 470; R_0402_1005Metric
R39, R40: 4.7k; R_0402_1005Metric_Pad0.72x0.64mm_HandSolder
R50, R51, R52, R53, R54, R55, R56, R57, R58, R59, R60, R61, R64, R65: R_Small; R_0402_1005Metric
R62, R63: R_Small; R_0603_1608Metric
SW1, SW2: Reset; SW4-SMD-2.8-2.6X1.6X0.53MM
TP5, TP7: VBAT; TestPoint_Pad_2.5x2.5mm
TP6, TP8: BAT GND; TestPoint_Pad_2.5x2.5mm
TP9, TP10: W_VBUS; TestPoint_Pad_2.5x2.5mm
TP11, TP12: W_GND; TestPoint_Pad_2.5x2.5mm
U2, U4: nRF52840; Nordic_AQFN-73-1EP_7x7mm_P0.5mm
U3, U5: ESDR0502NMUTAG; UDFN-6_1.2x1.0mm_P0.4mm
U7, U8: XC6220B331MR; SOT-23-5
U9, U10: MAX17048; TDFN-8-1EP_2x2mm_P0.5mm_EP0.8x1.2mm
U50: SSOP-32_6.1x11mm_P0.65mm
U51: MSOP-8_3x3mm_P0.65mm
U52: Trackpointer_4pin
U53, U54: MCP73831-2-MC; DFN-8-1EP_3x2mm_P0.5mm_EP1.7x1.4mm
Y1, Y4: 32.768 kHz; Crystal_SMD_2012-2Pin_2.0x1.2mm
Y2, Y3: 32MHz; Crystal_SMD_2016-4Pin_2.0x1.6mm
Y50: Crystal_GND2; Crystal_SMD 3pin

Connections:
/Keymatrix/Col0: KHS90.1, KHS91.1, KHS92.1, U2.A8 (AIN7/P0.31)
/Keymatrix/Col1: KHS93.1, KHS94.1, KHS95.1, U2.A10 (AIN5/P0.29)
/Keymatrix/Col2: KHS96.1, KHS97.1, KHS98.1, U2.A12 (AIN0/P0.02)
/Keymatrix/Col3: KHS99.1, KHS100.1, KHS101.1, U2.A14 (P1.15)
/Keymatrix/Col4: KHS102.1, KHS103.1, KHS104.1, U2.A16 (P1.13)
/Keymatrix/Col5: KHS105.1, KHS106.1, KHS107.1, U2.A20 (P1.10)
/Keymatrix/Col6: KHS108.1, KHS109.1, U2.B19 (P1.11)
/Keymatrix/LEDOut: LR90.2, LR91.2, LR92.2, LR93.2, LR94.2, LR95.2, LR96.2, LR97.2, LR98.2, LR99.2, LR100.2, LR101.2, LR102.2, LR103.2, LR104.2, LR105.2, LR106.2, LR107.2, LR108.2, LR109.2, Q1.3 (D)
/Keymatrix/Row0: D90.1 (K), D93.1 (K), D96.1 (K), D99.1 (K), D102.1 (K), D105.1 (K), U2.AD16 (P0.20)
/Keymatrix/Row1: D91.1 (K), D94.1 (K), D97.1 (K), D100.1 (K), D103.1 (K), D106.1 (K), D108.1 (K), U2.AD18 (P0.22)
/Keymatrix/Row2: D92.1 (K), D95.1 (K), D98.1 (K), D101.1 (K), D104.1 (K), D107.1 (K), D109.1 (K), U2.AD20 (P0.24)
/Keymatrix/Vcc: C62.2, LED90.2 (A), LED91.2 (A), LED92.2 (A), LED93.2 (A), LED94.2 (A), LED95.2 (A), LED96.2 (A), LED97.2 (A), LED98.2 (A), LED99.2 (A), LED100.2 (A), LED101.2 (A), LED102.2 (A), LED103.2 (A), LED104.2 (A), LED105.2 (A), LED106.2 (A), LED107.2 (A), LED108.2 (A), LED109.2 (A), R60.1, U7.5 (VOUT)
/Keymatrix_left/Col0: KHS110.1, KHS111.1, KHS112.1, U4.A8 (AIN7/P0.31)
/Keymatrix_left/Col1: KHS113.1, KHS114.1, KHS115.1, U4.A10 (AIN5/P0.29)
/Keymatrix_left/Col2: KHS116.1, KHS117.1, KHS118.1, U4.A12 (AIN0/P0.02)
/Keymatrix_left/Col3: KHS119.1, KHS120.1, KHS121.1, U4.A14 (P1.15)
/Keymatrix_left/Col4: KHS122.1, KHS123.1, KHS124.1, U4.A16 (P1.13)
/Keymatrix_left/Col5: KHS125.1, KHS126.1, KHS127.1, U4.A20 (P1.10)
/Keymatrix_left/Col6: KHS128.1, KHS129.1, U4.B19 (P1.11)
/Keymatrix_left/LEDOut: LR110.2, LR111.2, LR112.2, LR113.2, LR114.2, LR115.2, LR116.2, LR117.2, LR118.2, LR119.2, LR120.2, LR121.2, LR122.2, LR123.2, LR124.2, LR125.2, LR126.2, LR127.2, LR128.2, LR129.2, Q2.3 (D)
/Keymatrix_left/Row0: D110.1 (K), D113.1 (K), D116.1 (K), D119.1 (K), D122.1 (K), D125.1 (K), U4.AD16 (P0.20)
/Keymatrix_left/Row1: D111.1 (K), D114.1 (K), D117.1 (K), D120.1 (K), D123.1 (K), D126.1 (K), D128.1 (K), U4.AD18 (P0.22)
/Keymatrix_left/Row2: D112.1 (K), D115.1 (K), D118.1 (K), D121.1 (K), D124.1 (K), D127.1 (K), D129.1 (K), U4.AD20 (P0.24)
/Keymatrix_left/Vcc: C64.2, LED110.2 (A), LED111.2 (A), LED112.2 (A), LED113.2 (A), LED114.2 (A), LED115.2 (A), LED116.2 (A), LED117.2 (A), LED118.2 (A), LED119.2 (A), LED120.2 (A), LED121.2 (A), LED122.2 (A), LED123.2 (A), LED124.2 (A), LED125.2 (A), LED126.2 (A), LED127.2 (A), LED128.2 (A), LED129.2 (A), U8.5 (VOUT)
/Trackpointer/CLK: U2.J1 (AIN2/P0.04), U50.28
/Trackpointer/DATA: U2.L1 (P0.06), U50.2
/Trackpointer/RST: C56.1, U2.G1 (P0.26), U50.5
/Trackpointer/TP_A: C59.2, R59.1, R63.1, U52.13 (A)
/Trackpointer/TP_B: C60.2, R62.2, R64.1, U52.12 (B)
/Trackpointer/TP_D: C55.2, R51.2, R57.1, U50.21, U52.10 (D)
/nRF52840/ANT: AE1.1 (A), C10.2, R1.2
/nRF52840/BAT_I2C_SCL: U2.R1 (TRACEDATA3/P1.09), U9.7 (SCL)
/nRF52840/BAT_I2C_SDA: U2.N1 (P0.08), U9.8 (SDA)
/nRF52840/BAT_VOLT: C23.2, R9.2, R10.1, U2.U1 (TRACEDATA1/P0.12)
/nRF52840/BLUE_LED: D3.2 (A), U2.AD10 (P0.15)
/nRF52840/Backlight_trigger: Q1.1 (G), R39.2, U2.AD8 (P0.13)
/nRF52840/CAPS_LED: D22.2 (A), U2.AD12 (P0.17)
/nRF52840/CC1: P1.A5 (CC), R6.1
/nRF52840/CC2: P1.B5 (VCONN), R7.1
/nRF52840/PPH_VCC_CTRL: R23.1, U2.L24 (NFC1/P0.09), U7.3 (CE)
/nRF52840/RESET: SW1.1, U2.AC9 (P0.14), U2.AC11 (P0.16), U2.AC13 (P0.18/~RESET)
/nRF52840/SWC: J53.1, U2.AA24 (SWDCLK)
/nRF52840/SWD: J53.3, U2.AC24 (SWDIO)
/nRF52840/SWO: J53.5, U2.AD22 (TRACEDATA0/P1.00)
/nRF52840/USB_D+: J53.4, P1.A6 (D+), P1.B6 (D+), U2.AD6 (D+), U3.5 (D+)
/nRF52840/USB_D-: J53.6, P1.A7 (D-), P1.B7 (D-), U2.AD4 (D-), U3.6 (VBUS)
/nRF52840/VBAT: C13.2, C49.2, C65.2, C69.1, R8.1, TP5.1, U2.Y2 (VDDH), U7.1 (VIN), U9.2 (CELL), U9.3 (VDD), U53.3 (V_{BAT}), U53.4 (V_{BAT})
/nRF52840/VBUS: C1.2, D7.2 (A), J53.2, P1.A4 (VBUS), P1.A9 (VBUS), P1.B4 (VBUS), P1.B9 (VBUS), U2.AD2 (VBUS), U3.4 (D-)
/nRF52840/VDD_NRF: C16.2, C17.2, C18.2, C19.2, C20.2, L3.1, U2.A22 (VDD), U2.AD14 (VDD), U2.AD23 (VDD), U2.B1 (VDD), U2.W1 (VDD)
/nRF52840/VSS_PA: C12.1, NT1.1, U2.F23 (VSS_PA)
/nRF52840/W_VBUS: C67.1, D7.1 (K), D9.2 (A), TP9.1, U53.1 (V_{DD}), U53.2 (V_{DD})
/nRF52840_left/ANT: AE2.1 (A), C25.2, R12.2
/nRF52840_left/BAT_I2C_SCL: U4.R1 (TRACEDATA3/P1.09), U10.7 (SCL)
/nRF52840_left/BAT_I2C_SDA: U4.N1 (P0.08), U10.8 (SDA)
/nRF52840_left/BAT_VOLT: C41.2, R14.2, R15.1, U4.U1 (TRACEDATA1/P0.12)
/nRF52840_left/BLUE_LED: D4.2 (A), U4.AD10 (P0.15)
/nRF52840_left/Backlight_trigger: Q2.1 (G), R40.2, U4.AD8 (P0.13)
/nRF52840_left/CAPS_LED: D23.2 (A), U4.AD12 (P0.17)
/nRF52840_left/CC1: P2.A5 (CC), R20.1
/nRF52840_left/CC2: P2.B5 (VCONN), R21.1
/nRF52840_left/PPH_VCC_CTRL: R24.1, U4.L24 (NFC1/P0.09), U8.3 (CE)
/nRF52840_left/RESET: SW2.1, U4.AC9 (P0.14), U4.AC11 (P0.16), U4.AC13 (P0.18/~RESET)
/nRF52840_left/USB_D+: P2.A6 (D+), P2.B6 (D+), U4.AD6 (D+), U5.5 (D+)
/nRF52840_left/USB_D-: P2.A7 (D-), P2.B7 (D-), U4.AD4 (D-), U5.6 (VBUS)
/nRF52840_left/VBAT: C39.2, C63.2, C66.2, C70.1, R13.1, TP7.1, U4.Y2 (VDDH), U8.1 (VIN), U10.2 (CELL), U10.3 (VDD), U54.3 (V_{BAT}), U54.4 (V_{BAT})
/nRF52840_left/VBUS: C34.2, D8.2 (A), P2.A4 (VBUS), P2.A9 (VBUS), P2.B4 (VBUS), P2.B9 (VBUS), U4.AD2 (VBUS), U5.4 (D-)
/nRF52840_left/VDD_NRF: C40.2, C42.2, C43.2, C44.2, C45.2, L8.1, U4.A22 (VDD), U4.AD14 (VDD), U4.AD23 (VDD), U4.B1 (VDD), U4.W1 (VDD)
/nRF52840_left/VSS_PA: C29.1, NT2.1, U4.F23 (VSS_PA)
/nRF52840_left/W_VBUS: C68.1, D8.1 (K), D10.2 (A), TP10.1, U54.1 (V_{DD}), U54.2 (V_{DD})
GND: C1.1, C2.1, C3.1, C4.2, C5.2, C6.2, C7.2, C8.1, C9.1, C10.1, C11.1, C13.1, C16.1, C17.1, C18.1, C19.1, C20.1, C21.2, C22.2, C23.1, C24.2, C25.1, C26.1, C27.2, C28.2, C30.2, C31.2, C32.2, C33.2, C34.1, C35.1, C36.1, C37.1, C38.1, C39.1, C40.1, C41.1, C42.1, C43.1, C44.1, C45.1, C46.2, C49.1, C50.2, C51.1, C52.2, C62.1, C63.1, C64.1, C65.1, C66.1, C67.2, C68.2, C69.2, C70.2, J53.7, J53.8, NT1.2, NT2.2, P1.A1 (GND), P1.A12 (GND), P1.B1 (GND), P1.B12 (GND), P2.A1 (GND), P2.A12 (GND), P2.B1 (GND), P2.B12 (GND), Q1.2 (S), Q2.2 (S), R5.1, R6.2, R7.2, R10.2, R11.1, R15.2, R16.1, R17.1, R20.2, R21.2, R23.2, R24.2, R25.2, R26.2, R31.1, R32.1, R39.1, R40.1, R53.1, R61.1, R62.1, R63.2, SW1.2, SW2.2, TP6.1, TP8.1, TP11.1, TP12.1, U2.B7 (VSS), U2.EP (VSS), U3.1 (GND), U4.B7 (VSS), U4.EP (VSS), U5.1 (GND), U7.2 (GND), U8.2 (GND), U9.1 (CTG), U9.4 (GND), U9.6 (QSTRT), U9.9 (EP), U10.1 (CTG), U10.4 (GND), U10.6 (QSTRT), U10.9 (EP), U50.13, U51.4 (V-), U52.11 (C), U53.6 (V_{SS}), U54.6 (V_{SS}), Y2.2, Y2.4, Y3.2, Y3.4
unnamed: C11.2, L4.1, R1.1
unnamed: C26.2, L5.1, R12.1
unnamed: C50.1, U50.19
unnamed: C51.2, C53.2, C54.2, C58.2, R60.2, U50.14, U50.17, U50.26
unnamed: C52.1, R52.2, R55.2, U50.12
unnamed: C53.1, C54.1, C56.2, C58.1, R53.2, R61.2, U50.8, U50.32, Y50.2
unnamed: C55.1, C59.1, C60.1, R56.2
unnamed: D3.1 (K), R5.2
unnamed: D4.1 (K), R16.2
unnamed: D9.1 (K), R27.1
unnamed: D10.1 (K), R28.1
unnamed: D22.1 (K), R31.2
unnamed: D23.1 (K), R32.2
unnamed: D90.2 (A), KHS90.2
unnamed: D91.2 (A), KHS91.2
unnamed: D92.2 (A), KHS92.2
unnamed: D93.2 (A), KHS93.2
unnamed: D94.2 (A), KHS94.2
unnamed: D95.2 (A), KHS95.2
unnamed: D96.2 (A), KHS96.2
unnamed: D97.2 (A), KHS97.2
unnamed: D98.2 (A), KHS98.2
unnamed: D99.2 (A), KHS99.2
unnamed: D100.2 (A), KHS100.2
unnamed: D101.2 (A), KHS101.2
unnamed: D102.2 (A), KHS102.2
unnamed: D103.2 (A), KHS103.2
unnamed: D104.2 (A), KHS104.2
unnamed: D105.2 (A), KHS105.2
unnamed: D106.2 (A), KHS106.2
unnamed: D107.2 (A), KHS107.2
unnamed: D108.2 (A), KHS108.2
unnamed: D109.2 (A), KHS109.2
unnamed: D110.2 (A), KHS110.2
unnamed: D111.2 (A), KHS111.2
unnamed: D112.2 (A), KHS112.2
unnamed: D113.2 (A), KHS113.2
unnamed: D114.2 (A), KHS114.2
unnamed: D115.2 (A), KHS115.2
unnamed: D116.2 (A), KHS116.2
unnamed: D117.2 (A), KHS117.2
unnamed: D118.2 (A), KHS118.2
unnamed: D119.2 (A), KHS119.2
unnamed: D120.2 (A), KHS120.2
unnamed: D121.2 (A), KHS121.2
unnamed: D122.2 (A), KHS122.2
unnamed: D123.2 (A), KHS123.2
unnamed: D124.2 (A), KHS124.2
unnamed: D125.2 (A), KHS125.2
unnamed: D126.2 (A), KHS126.2
unnamed: D127.2 (A), KHS127.2
unnamed: D128.2 (A), KHS128.2
unnamed: D129.2 (A), KHS129.2
unnamed: L1.2, L2.1
unnamed: L6.2, L7.1
unnamed: LED90.1 (K), LR90.1
unnamed: LED91.1 (K), LR91.1
unnamed: LED92.1 (K), LR92.1
unnamed: LED93.1 (K), LR93.1
unnamed: LED94.1 (K), LR94.1
unnamed: LED95.1 (K), LR95.1
unnamed: LED96.1 (K), LR96.1
unnamed: LED97.1 (K), LR97.1
unnamed: LED98.1 (K), LR98.1
unnamed: LED99.1 (K), LR99.1
unnamed: LED100.1 (K), LR100.1
unnamed: LED101.1 (K), LR101.1
unnamed: LED102.1 (K), LR102.1
unnamed: LED103.1 (K), LR103.1
unnamed: LED104.1 (K), LR104.1
unnamed: LED105.1 (K), LR105.1
unnamed: LED106.1 (K), LR106.1
unnamed: LED107.1 (K), LR107.1
unnamed: LED108.1 (K), LR108.1
unnamed: LED109.1 (K), LR109.1
unnamed: LED110.1 (K), LR110.1
unnamed: LED111.1 (K), LR111.1
unnamed: LED112.1 (K), LR112.1
unnamed: LED113.1 (K), LR113.1
unnamed: LED114.1 (K), LR114.1
unnamed: LED115.1 (K), LR115.1
unnamed: LED116.1 (K), LR116.1
unnamed: LED117.1 (K), LR117.1
unnamed: LED118.1 (K), LR118.1
unnamed: LED119.1 (K), LR119.1
unnamed: LED120.1 (K), LR120.1
unnamed: LED121.1 (K), LR121.1
unnamed: LED122.1 (K), LR122.1
unnamed: LED123.1 (K), LR123.1
unnamed: LED124.1 (K), LR124.1
unnamed: LED125.1 (K), LR125.1
unnamed: LED126.1 (K), LR126.1
unnamed: LED127.1 (K), LR127.1
unnamed: LED128.1 (K), LR128.1
unnamed: LED129.1 (K), LR129.1
unnamed: C24.1, P1.S1 (SHIELD), R11.2
unnamed: C46.1, P2.S1 (SHIELD), R17.2
unnamed: R8.2, R9.1
unnamed: R13.2, R14.1
unnamed: R50.2, R52.1, U50.22
unnamed: R54.1, R55.1, R56.1, R57.2, R58.1, R65.1
unnamed: R54.2, U50.24
unnamed: C12.2, L4.2, U2.H23 (ANT)
unnamed: L2.2, U2.B3 (DCC)
unnamed: L3.2, U2.AB2 (DCCH)
unnamed: C7.1, U2.C1 (DEC1)
unnamed: C6.1, U2.D23 (DEC3)
unnamed: C2.2, C3.2, L1.1, U2.B5 (DEC4), U2.E24 (DEC6)
unnamed: C5.1, U2.N24 (DEC5)
unnamed: C4.1, U2.AC5 (DECUSB)
unnamed: C21.1, U2.B24 (XC1), Y2.1
unnamed: C22.1, U2.A23 (XC2), Y2.3
unnamed: C8.2, U2.D2 (XL1/P0.00), Y1.1
unnamed: C9.2, U2.F2 (XL2/P0.01), Y1.2
unnamed: C29.2, L5.2, U4.H23 (ANT)
unnamed: L7.2, U4.B3 (DCC)
unnamed: L8.2, U4.AB2 (DCCH)
unnamed: C30.1, U4.C1 (DEC1)
unnamed: C31.1, U4.D23 (DEC3)
unnamed: C35.2, C36.2, L6.1, U4.B5 (DEC4), U4.E24 (DEC6)
unnamed: C32.1, U4.N24 (DEC5)
unnamed: C33.1, U4.AC5 (DECUSB)
unnamed: C27.1, U4.B24 (XC1), Y3.1
unnamed: C28.1, U4.A23 (XC2), Y3.3
unnamed: C37.2, U4.D2 (XL1/P0.00), Y4.1
unnamed: C38.2, U4.F2 (XL2/P0.01), Y4.2
unnamed: U50.6, Y50.3
unnamed: U50.7, Y50.1
unnamed: C57.1, R58.2, U51.3 (+IN_A)
unnamed: C61.1, R65.2, U51.5 (+IN_B)
unnamed: C57.2, R59.2, U51.2 (-IN_A)
unnamed: C61.2, R64.2, U51.6 (-IN_B)
unnamed: U50.11, U51.1 (OUT_A)
unnamed: U50.10, U51.7 (OUT_B)
unnamed: R50.1, R51.1, U50.9, U50.20, U50.23, U51.8 (V+)
unnamed: R25.1, U53.8 (PROG)
unnamed: R27.2, U53.5 (STAT)
unnamed: R26.1, U54.8 (PROG)
unnamed: R28.2, U54.5 (STAT)

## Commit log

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2024-07-29 Improves handling of the kicad
    [piparv2.kicad_sch]
2024-07-31 reorganize and combine pcb with zmk
    [pipar.kicad_pcb, pipar.kicad_sch]
2024-07-31 Improves README with pretty pictures
    [pipar.kicad_pcb]
2024-08-01 Improved schematics and PCBs
    [pipar.kicad_pcb, pipar.kicad_sch]
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2024-08-01 updates pcb and zmk, forgot to use i2c pins
    [pipar.kicad_pcb, pipar.kicad_sch]
2024-08-01 adds LVGL config fixes case
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2024-08-01 fixes flow
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2024-08-02 slightly improved PCB design
    [pipar.kicad_pcb]
2024-08-08 flip tab and esc
2024-09-19 updates the pcb for flake
    [pipar.kicad_pcb]
2024-09-19 Updates the prod pcb file
    [pipar.kicad_pcb]
2024-09-19 Adds missing heat inserts and screws
2024-09-24 restructure and seperate pcbs
    [pipar_flake.kicad_pcb, pipar_flake.kicad_sch, pipar_point.kicad_pcb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]
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2024-10-01 schematic done with added button for reset on xiao
    [pipar_point.kicad_pcb, pipar_point.kicad_sch]
2024-10-03 Finish setting up the board
    [pipar_point.kicad_pcb, pipar_point.kicad_sch]
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2024-10-06 moves the through hole away from pad
    [Pipar_Point.3mf, Pipar_Point_TestFit.3mf, pipar_point.kicad_pcb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]
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2024-10-09 starts work on t460s board
    [pipar_point.kicad_pcb, pipar_point.kicad_sch, t460s_trackpoint.kicad_sch]
2024-10-11 Push an update to fix encoder issues on flake
2024-10-11 adds other changes done so far to t460s
    [t460s_trackpoint.kicad_sch]
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2024-10-14 remove logging and revert to use volume
    [pipar_point.kicad_pcb]
2024-10-18 starts work on t460s board 2
    [pipar_point.kicad_pcb, pipar_point.kicad_sch, pipar_point_trackpoint.kicad_pcb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]
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2024-10-21 Recreated Sool & Pipar for production run
    [pipar_sool.kicad_pcb, pipar_sool.kicad_sch]
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2024-10-21 Adds PCBWay zip and adds on off hints
    [pipar_sool.kicad_pcb]
2024-10-23 adds couple of SVGs to sool and etsy link
    [pipar_sool.step]
2024-10-25 Reworks Pipar Flake to add LEDs and a bigger place for battery
    [pipar_flake.kicad_pcb, pipar_flake.kicad_sch]
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2024-10-25 slightly change the cut to be more straight
    [pipar_flake.kicad_pcb]
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2024-11-10 enables display and encoder, fixes used pins
2024-11-10 swap sda and scl pins
    [pipar_flake.kicad_pcb, pipar_flake.kicad_sch]
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2025-01-19 start work on pnp version
    [pipar_sool_pnp.kicad_pcb, pipar_sool_pnp.kicad_sch]
2025-01-19 Further changes to placement
    [pipar_sool_pnp.kicad_pcb]
2025-01-19 Finish PnP position files
    [pipar_sool_pnp.kicad_pcb, pipar_sool_pnp.kicad_sch]
2025-01-24 start of creating newer models
    [KeyMatrix.kicad_sch, PnP.kicad_sch, pipar_sool.kicad_pcb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]
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2025-02-28 Remove obsolete files and update KiCad project settings for compatibility
    [KeyMatrix.kicad_sch, PnP.kicad_sch, pipar_sool.kicad_pcb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]
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2025-03-01 further improvments and cleanup
    [pipar_sool.kicad_pcb, pipar_sool.kicad_sch]
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2025-03-02 push initial schema for t460s
    [pipar_point.kicad_sch, t460s_trackpoint.kicad_sch]
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2025-03-04 start work on pipar point again
    [Lenovo_T460s_Trackpoint.kicad_sch, Pipar_Point.3mf, Pipar_Point_TestFit.3mf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]
2025-03-13 more pipar poimt progress
    [keymatrix.kicad_sch, nRF52840.kicad_sch, pipar_point.kicad_pcb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]
2025-03-18 more progress on pipar point
    [nRF52840.kicad_sch, pipar_point.kicad_pcb]
2025-03-26 update pipar point traces and add more connection pads
    [nRF52840.kicad_sch, pipar_point.kicad_pcb]
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2025-03-29 one side is done
    [nRF52840.kicad_sch]
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2025-05-10 pipar point v1, prototype
    [T460s.kicad_sch, nRF52840.kicad_sch, nrf52840_xiao.kicad_sch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]
2025-05-15 Fixes diode footprint to be sod-523, removes text
    [keymatrix.kicad_sch, keymatrix_macropad.kicad_sch]
2025-05-20 start fixing footprints
    [keymatrix.kicad_sch, keymatrix_macropad.kicad_sch, nRF52840.kicad_sch]
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2025-05-22 fixes traces around leds
2025-05-23 change footprints, fix traces, fix groundfill
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2025-06-19 fix esd routing
    [nRF52840.kicad_sch]
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2025-06-27 test out tap stuff
    [pipar_point.step]
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2025-07-25 adds pipar chip as its own board
    [keymatrix.kicad_sch, pipar_chip.kicad_pcb, pipar_chip.kicad_sch]
2025-08-09 update the ESD component to be in bom
    [pipar_chip.kicad_pcb, pipar_chip.step]
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2025-08-10 Update LED GPIO configuration to active low and optimize keymap bindings
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2025-08-29 start work on pipar point v3
    [Lenovo_T460s_Trackpoint.kicad_sch, T460s.kicad_sch, keymatrix.kicad_sch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]
2025-08-30 updates the pinout for the isp1807
    [pipar_point_v3.kicad_pcb, power.kicad_sch, side.kicad_sch]
2025-09-01 Place keys on the left hand side
    [pipar_point_v3.kicad_pcb]
2025-09-02 Right hand side keys
    [pipar_point_v3.kicad_pcb, pipar_point_v3.kicad_sch, side-right.kicad_sch]
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2025-09-05 Refactor schematic connections and add hierarchical labels
    - Removed redundant no_connect entries and updated UUIDs for clarity.
    - Added new no_connect entries at specified coordinates.
    - Introduced hierarchical labels for "3.3V", "TPClock", "TPData", and "TPRST" with appropriate formatting and positioning.
    [pipar_point_v3.kicad_pcb, pipar_point_v3.kicad_sch, power.kicad_sch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]
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2025-09-12 right side routed, progress on left side
    [side.kicad_sch]
2025-09-14 Pipar Point PCB done, maybe
    [pipar_point_v3.kicad_sch, pipar_point_v3.step, side.kicad_sch]
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2025-09-15 adds a proper battery connector
    [keymatrix.kicad_sch, pipar_point_v3.kicad_sch, power.kicad_sch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]
2025-09-16 cleaned up traces on right side, updated bom
    [keymatrix.kicad_sch, power.kicad_sch, side.kicad_sch]
2025-09-16 fixes small trace issues
2025-09-17 stuff, i dont remember
    [power.kicad_sch, side.kicad_sch]
2025-09-20 changed npm1100 to npm1300 and got rid of some footprints
    [keymatrix.kicad_sch, pipar_point_v3.kicad_sch, power.kicad_sch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]
2025-09-21 finished unibody urchin, maybe ;)
    [pipar_urchin_unibody.kicad_pcb, pipar_urchin_unibody.kicad_sch]
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2025-09-21 changed the body to make room for the oled screen
    [pipar_urchin_unibody.kicad_pcb, pipar_urchin_unibody.kicad_sch]
2025-09-21 Update pipar_urchin_unibody.zip with latest production files
    [pipar_urchin_unibody.kicad_pcb, pipar_urchin_unibody.kicad_sch]
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2025-10-31 Add pipar_point configuration files and update layouts
    - Introduced pipar_point.dtsi with device tree configurations.
    - Added pinctrl settings for I2C in pipar_point-pinctrl.dtsi.
    - Updated physical layout to use pipar_matrix in pipar_point-layouts.dtsi.
    - Created keymap in pipar_point.keymap for key bindings.
    - Added left and right device tree source files for pipar_point.
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2025-11-05 Adds trackpoint reset GPIO Fix floating led 15 and 35 (mirrored)
    [keymatrix.kicad_sch, pipar_point_v3.kicad_sch, side.kicad_sch]
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2025-11-18 feat: add dongle fix: move footprint folders around generates new production files mentions pcbway as the v3 sponsor on silkscreen
    [dongle.kicad_sch, pipar_point_v3.kicad_sch, power.kicad_sch]
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2025-11-21 pcb: fix 3D model paths/orientation and update front render
    - Use ${PIPAR_FOOTPRINTS} for EVP-BB1AAB000 3D model path
    - Tweak EVPBB2A9B000 model offset/rotation
    - Replace updated .extra/pipar_point_front_3d.png
2025-12-09 ci: use correct trackpoint snippet (studio-rpc-usb-uart) in build_pipar_point workflow
2025-12-19 pcb: update manufacturer and Mouser part numbers in schematics
    Replace IRLML6344TRPBF (942-IRLML6344TRPBF) with SI2342DS-T1-GE3 (78-SI2342DS-T1-GE3) in keymatrix.kicad_sch.
    Correct GRM188R61E106KA73J -> GRM188R61E106KA73D and update corresponding Mouser codes (…KA3J -> …KA3D) in power.kicad_sch.
    [keymatrix.kicad_sch, power.kicad_sch]
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2026-04-03 Update zmk-keyboard-pipar with trackpoint driver stability fixes
2026-05-21 Bump zmk-keyboard-pipar: keyboard stability fixes
    I2C transfer timeout, recovery watchdog, battery_indicator
    edge-detect/retry, and explicit BT controller priority demotion.
2026-05-21 Fix board identifiers in build_all.yaml and update README.md with correct GitHub Actions workflow link
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2026-08-24 Add firmware test harness: battery profile unit test + config validation
    ./build.sh test runs (a) a host-compiled unit test of the battery OCV
    profile — the table is regenerated from the nPM1300 profiler's
    characterization data and must match the header the firmware compiles,
    round-trip within 1%, stay monotonic, and never regress to the old
    linear behavior — and (b) post-build validation asserting the
    stability-critical Kconfig symbols (watchdog window, partial flash
    erase, lowprio stack size, stack protection, battery profile, UART
    interrupt API) survive in both halves' resolved .config.
    Claude-Session: https://claude.ai/code/sess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
2026-11-13 CI: build with ZMK's board variants and upstream build workflow
    The Sool and Flake matrices used the plain board IDs (xiao_ble, nice_nano).
    Since the move to Zephyr 4.1 those select Zephyr's stock board, not ZMK's
    board variant, so the Sool builds had no Bluetooth (CONFIG_ZMK_BLE unset):
    the halves could not connect to the dongle. Use xiao_ble//zmk and
    nice_nano//zmk.
    Also use zmkfirmware/zmk's build-user-config workflow; the Zephyr 4.1 branch
    it came from is merged, and upstream now fails a build that selects a board
    without its ZMK variant.
    Claude-Session: https://claude.ai/code/session_01N6WTLUmvKpX4aZ9tWg6q3R
2026-11-13 Release: build with ZMK's board variants and upstream build workflow
    xiao_ble and nice_nano select Zephyr's stock boards since the move to
    Zephyr 4.1, which left the Sool without Bluetooth. Same fix as on master
    (ci/zmk-board-variants).
    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
